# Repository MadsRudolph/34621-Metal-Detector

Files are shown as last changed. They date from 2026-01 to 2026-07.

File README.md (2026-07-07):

<div align="center">

# VLF Metal Detector

**Electromagnetic Sensors & Digital Signal Processing**





_A technical implementation of a VLF induction balance metal detector using real-time DFT-based phase detection._

---

</div>

## Overview

This project targets the development of a functional VLF metal detector built on the ATmega328P. It features modular firmware, IIR signal smoothing, and phase-based classification to distinguish between ferromagnetic and non-ferromagnetic metals.

### Features

- **DSP Core:** Single-bin DFT optimized for 4x oversampling (8 kHz) with real-time phase observation.
- **Power Stage:** High-efficiency H-bridge MOSFET driver for the transmitter coil.
- **Coil System:** Concentric coil design with an integrated bucking coil for balance.
- **Feedback:** Real-time OLED HUD and variable-tone buzzer for proximity detection.

## Architecture

```mermaid
graph LR
    MCU[MCU / 2kHz SQ] --> HB[H-Bridge] --> TX[TX Coil]
    Target((Metal)) -. Induction .-> RX[RX Coil]
    RX --> AMP[RX Amp] --> ADC[10-bit ADC]
    ADC --> DFT[DFT Processing] --> IIR[IIR Filter] --> UI[OLED + Buzzer]
```

## Specifications

| Component | Specification |
| :--- | :--- |
| **TX Frequency** | 2 kHz (Square Wave) |
| **Sample Rate**  | 8 kHz (4x Oversampling) |
| **MCU** | ATmega328P (Arduino Nano @ 16MHz) |
| **Driver** | H-Bridge (IRF5305 + IRL530) |
| **Sensors** | Concentric Coils (Bucking config) |
| **UI** | SSD1306 OLED (I2C) |

## Repository

- `Code/` — Core firmware (PlatformIO, C)
- `Docs/` — Technical reports and [Final PDF](Docs/Metaldetektor_Projekt.pdf)
- `KiCad/` — Hardware schematics and PCB designs
- `Simulation/` — LTspice and QSPICE validation files
- `Scripts/` — MATLAB and Python analysis tools

## Getting Started

Build and upload using [PlatformIO](https://platformio.org/):

```bash
cd Code
pio run -t upload
pio device monitor
```

---

<div align="center">
<b>Mads Rudolph · Andreas Skaaning · Jonas Beck · Sigurd Hestbech</b>
<br>
<sub>DTU Course 34621 · January 2026</sub>
</div>

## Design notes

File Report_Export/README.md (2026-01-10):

# Report Export Assets

This folder contains assets prepared for export to the DTU 34621 VLF Metal Detector report repository (Overleaf).

## Purpose

This folder serves as a staging area for figures, schematics, code snippets, and data that will be included in the final project report. Assets placed here are ready for export to the report repository.

## Folder Structure

| Folder | Description | Export Destination |
|---|---|---|
| `figures/` | Plots, diagrams, photos, and other images | `report/figures/` |
| `schematics/` | Circuit schematics and PCB layouts | `report/figures/schematics/` |
| `code_snippets/` | Key code excerpts for the report | `report/code/` |
| `data/` | Measurement data, CSV files, tables | `report/data/` |

## Workflow for Adding Assets

1. **Create/Export the Asset**
   - Generate figures from simulation tools or measurement software
   - Export schematics as PDF or high-resolution PNG
   - Copy relevant code snippets to separate files
   - Save measurement data as CSV or formatted tables

2. **Place in Appropriate Folder**
   - Use the correct subfolder based on asset type
   - Follow the naming convention (see below)

3. **Run Export Script**
   - Execute `./export_to_report.sh <report_repo_path>` from the project root
   - Commit and push changes in the report repository

## Running the Export Script

From the project root directory:

```bash
# Export to sibling report repository
./export_to_report.sh ../34621-Report

# Export to custom path
./export_to_report.sh /path/to/report/repo
```

The script will:
- Copy all non-empty asset folders to the report repository
- Skip folders that only contain `.gitkeep` files
- Print instructions for committing changes

## Naming Convention

Use **lowercase with underscores** for all filenames. Names should be descriptive and include context.

### Examples

| Good | Bad |
|---|-----|
| `tx_driver_schematic.pdf` | `Schematic1.pdf` |
| `dft_phase_response.png` | `Figure 3.png` |
| `rx_amplifier_bode_plot.png` | `bode.PNG` |
| `power_consumption_data.csv` | `data.csv` |
| `dft_algorithm.c` | `code.c` |

### Recommended Prefixes

- `tx_` - Transmitter related
- `rx_` - Receiver related
- `dft_` - DFT/signal processing related
- `coil_` - Coil design related
- `power_` - Power supply/consumption related
- `test_` - Test results and measurements

## File Formats

| Asset Type | Preferred Format | Alternative |
|---|---|---|
| Schematics | PDF (vector) | PNG (300+ DPI) |
| Plots/Graphs | PDF (vector) | PNG (300+ DPI) |
| Photos | JPEG | PNG |
| Code | `.c`, `.h` | `.txt` |
| Data | CSV | TXT |

## Notes

- Vector formats (PDF) are preferred for schematics and plots as they scale without quality loss
- Ensure all figures have readable labels and appropriate font sizes
- Include units in axis labels for all plots
- Code snippets should be self-contained and well-commented

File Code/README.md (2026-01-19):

# VLF Metaldetektor Firmware

Arduino Nano (ATmega328P @ 16MHz) firmware til VLF metaldetektion.

> **Teori:** [DSP-Bible](obsidian://open?vault=Obsidian&file=Courses%2FDSP%2FFormulas%2FDSP-Bible) | [FIIR & IIR](obsidian://open?vault=Obsidian&file=Courses%2FDSP%2FFormulas%2FFIIR%20%26%20IIR)

## Nuværende Struktur

```
src/
├── main.c            # Hovedprogram, initialisering, hovedløkke
├── adc.c             # ADC sampling og auto-trigger
├── button.c          # Knaphåndtering med debounce
├── buzzer.c          # Buzzer feedback (beeps ved detektion)
├── capture.c         # MATLAB serial capture interface
├── detection.c       # Metal klassificering (ferro/non-ferro)
├── dft.c             # DFT beregning og akkumulering
├── display.c         # OLED display med grafisk HUD og ikoner
├── filter.c          # IIR filter til udglatning
├── jingle.c          # Startup-melodi
├── timer.c           # Timer0/Timer1 konfiguration
│
├── include/          # Header filer
│   ├── config.h      # Globale konstanter og konfiguration
│   ├── adc.h, button.h, buzzer.h, capture.h
│   ├── detection.h, dft.h, display.h, filter.h
│   ├── jingle.h, timer.h
│
└── drivers/          # Hardware drivere (modificer ikke)
    ├── I2C.c/h       # TWI master driver
    ├── ssd1306.c/h   # OLED display driver
    └── data.h        # Font og ikon data (PROGMEM)
```

## Implementeret Funktionalitet

| Funktion | Status | Beskrivelse |
|---|---|---|
| TX Signal | ✅ Færdig | 2 kHz firkantbølge via Timer0 |
| ADC Sampling | ✅ Færdig | 8 kHz auto-trigger fra Timer0 |
| DFT Beregning | ✅ Færdig | Single-bin DFT med 4× oversampling |
| Magnitude/Fase | ✅ Færdig | Beregning fra Re/Im komponenter |
| OLED Display | ✅ Færdig | Grafisk HUD med ikoner og progress bar |
| Debug Knap | ✅ Færdig | D4 skifter mellem DFT/Debug skærm |
| Start/Stop Knap | ✅ Færdig | D2 toggle detektor on/off |
| Kalibrering Knap | ✅ Færdig | D3 gemmer baseline (luft-aflæsning) |
| Metalklassificering | ✅ Færdig | Ferro/non-ferro baseret på fase |
| IIR Filter | ✅ Færdig | Udglatning af display værdier |
| Buzzer Feedback | ✅ Færdig | Bip ved metal detektion |
| Startup Jingle | ✅ Færdig | Melodi ved opstart |
| Splash Screen | ✅ Færdig | Logo ved opstart |

## Build

```bash
pio run              # Kompilér
pio run -t upload    # Upload til board
pio device monitor   # Seriel monitor
```

## Pin Konfiguration

| Pin | Funktion | Retning |
|-----|---|---|
| 9 (PB1) | TX signal output (2kHz) | OUTPUT |
| 11 (PB3) | Buzzer output (PWM tone) | OUTPUT |
| A0 (PC0) | RX signal input (ADC) | INPUT |
| A4 (PC4) | I2C SDA (OLED) | I/O |
| A5 (PC5) | I2C SCL (OLED) | OUTPUT |
| D2 (PD2) | Start/Stop knap | INPUT (pull-up) |
| D3 (PD3) | Kalibrering knap | INPUT (pull-up) |
| D4 (PD4) | Debug knap | INPUT (pull-up) |

## Signalflow

```
Timer0 (8kHz) ──┬──> TX Pin Toggle (hver 2. interrupt = 2kHz)
                │
                └──> ADC Auto-Trigger
                          │
                          ▼
                    ADC ISR (8kHz)
                          │
                          ▼
                    DFT Akkumulering (64 samples)
                          │
                          ▼
                    IIR Filter → Klassificering → Display + Buzzer
```

## Konfigurationsparametre

```c
// Fra include/config.h
#define F_SAMPLE 8000     // Sample frekvens (Hz)
#define F_SIGNAL 2000     // TX/RX signal frekvens (Hz)
#define N 64              // Samples per DFT vindue
#define IIR_ALPHA 0.15f   // Filter udglatning
#define FERRO_THRESHOLD -10   // Fase tærskel for ferro (grader)
#define DETECT_THRESHOLD 5    // Min. magnitude ændring for detektion
```

## Moduler

| Modul | Beskrivelse |
|---|---|
| `timer.c` | Timer0 (8kHz interrupt, TX toggle) og Timer1 (buzzer PWM) |
| `adc.c` | ADC auto-trigger setup og sample håndtering |
| `dft.c` | Optimeret single-bin DFT (kun bin k=16 ved 2kHz) |
| `filter.c` | IIR lavpas filter for stabil visning |
| `detection.c` | Kalibrering og metal klassificering (ferro/non-ferro) |
| `display.c` | Grafisk HUD med ikoner, progress bar, splash screen |
| `button.c` | Debounced knaphåndtering for D2, D3, D4 |
| `buzzer.c` | Tone-generering via Timer1 PWM |
| `jingle.c` | Startup-melodi sekvens |
| `capture.c` | MATLAB serial interface til DFT verifikation |

## Relaterede Dokumenter

- [Project_Roadmap.md](../Docs/Project_Roadmap.md) - Fuld kravanalyse og status
- [Code_Review.md](../Docs/Guides/Code_Review.md) - Kodegennemgang

#firmware #arduino #dft #metaldetektor

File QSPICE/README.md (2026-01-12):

# QSPICE H-Bridge Simulation

> TX driver simulation for VLF metal detector coil excitation.
> Achieved **~98% efficiency** with optimized RLC filter.

> [!note] Danish Documentation
> For detailed theory and design rationale in Danish, see [TX Driver Design](../Docs/Theory/TX%20Driver%20Design.md).

---

## Overview

This folder contains QSPICE simulations for the H-bridge driver that excites the TX coil at 2kHz. The system converts 9V DC battery power to a sinusoidal current through the transmit coil.

```text
┌─────────────┐     ┌─────────────┐     ┌─────────────┐     ┌─────────────┐
│  PWM Input  │────▶│  Dead-Time  │────▶│  Bootstrap  │────▶│   H-Bridge  │────▶ TX Coil
│   (2kHz)    │     │  Generator  │     │ Gate Driver │     │  (IRL530)   │     (LC Tank)
└─────────────┘     └─────────────┘     └─────────────┘     └─────────────┘
```

---

## Files

| File | Description |
|---|---|
| `Hbro_sim.qsch` | Main H-bridge simulation with load |
| `bootstrap.qsch` | Bootstrap gate driver circuit |
| `dead_time.qsch` | Dead-time generator subcircuit |

---

## Hbro_sim.qsch — Main Simulation

### Circuit Topology

```text
        +9V (V1, RSER=1.7Ω)
            │
    ┌───────┴───────┐
    │               │
   M6              M3
  (IRL530)       (IRL530)
    │               │
    ├───[L2]───[C1]─┤───[R10]───┐
    │   6.3mH   1µF │    35Ω    │
   M4              M2           │
  (IRL530)       (IRL530)       │
    │               │           │
    └───────┬───────┘           │
           GND◄─────────────────┘
```

### Power Stage

| Component | Part | Specifications |
|---|---|---|
| M2, M3, M4, M6 | IRL530 | Vds=100V, Ids=15A, Ron=0.16Ω, Qg=17.8nC |
| D3, D4 | 1N4148 | Freewheeling diodes |

### Gate Drivers

| Component | Part | Function |
|---|---|---|
| M1, M7 | BS170 | Level shifter / inverter |
| U1, U2 | INV (OR gate) | Signal inversion |
| D1, D2 | 1N4148 | Bootstrap diode |
| C2, C3 | 1µF | Bootstrap capacitor |
| R3, R7 | Rup (1K) | Pull-up resistor |

### Load (TX Coil Model)

| Component | Value | Purpose |
|---|---|---|
| L2 | 6.332 mH | TX coil inductance |
| C1 | 1µF (param) | Resonance capacitor |
| R10 | 35Ω | Coil DC resistance |

Resonance frequency:
$$f_0 = \frac{1}{2\pi\sqrt{LC}} = \frac{1}{2\pi\sqrt{6.332\text{mH} \cdot 1\mu\text{F}}} \approx 2\text{kHz}$$

### PWM Signals

| Signal | Definition | Description |
|---|---|---|
| V3 (PWM1) | `PULSE 0 5 250µ 10n 10n 245µ 500µ` | Phase A, 250µs delay |
| V4 (PWM2) | `PULSE 0 5 0 10n 10n 245µ 500µ` | Phase B, no delay |
| V5 (PWM) | `pulse 5 0 0 10n 10n 0.5/2K 1/2K` | Master 2kHz clock |

The 180° phase shift between PWM1 and PWM2 creates alternating H-bridge states.

### Simulation Commands

```spice
.tran 0 0.2 0.198 1µ          ; Transient analysis, 0.2s
.options savepowers=1          ; Save power data

; Efficiency measurement
.meas Pl rms p(l2)+p(R10)+p(c1)    ; Load power
.meas Psource rms p(v1)            ; Source power
.meas eta param Pl/Psource         ; Efficiency η

; Parameter sweeps (commented)
;.step param R 0.01K 0.91K 0.1K
;.step param c1 0.1µ 1µ 0.1µ
```

---

## bootstrap.qsch — Gate Driver

The bootstrap circuit enables driving high-side N-channel MOSFETs from a ground-referenced PWM signal.

### Operating Principle

```text
    +9V
     │
     D1 (BAS521)──────┐
     │                │
    [R1=5Ω]          [C1=1µF]  ← Bootstrap Cap
     │                │
     └────────────────┼──── Vboot (floating supply)
                      │
                     M1 (AO3422, High-side)
                      │
                     OUT ──────────────────── To load
                      │
                     M2 (AO4262E, Low-side)
                      │
                     GND
```

### Bootstrap Sequence

1. **Low-side ON**: M2 conducts, OUT = GND
2. **C1 charges**: Current flows +9V → D1 → R1 → C1 → GND
3. **Low-side OFF**: Dead-time begins
4. **High-side ON**: M1 gate driven by Vboot (OUT + 9V)
5. **C1 discharges**: Provides gate charge for M1

### Components

| Half-Bridge | High-Side | Low-Side | Bootstrap | Pull-up |
|---|---|---|---|---|
| Left | M1 (AO3422) | M2 (AO4262E) | D1, C1, R1 | R4 (1K) |
| Right | M4 (AO3422) | M5 (AO4262E) | D2, C2, R5 | R8 (1K) |

Gate resistors (R2, R3, R6, R7 = 10Ω) limit di/dt and reduce EMI.
Pull-up resistors (R4, R8 = 1K) ensure defined gate state when driver is disabled.

---

## dead_time.qsch — Dead-Time Generator

Prevents shoot-through by ensuring both switches are OFF during transitions.

### Block Diagram

```text
                    ┌─────────────┐
     PWM_In ───────▶│   RC Delay  │
                    │  R4=R, C1=C │
                    └──────┬──────┘
                           │
              ┌────────────┴────────────┐
              ▼                         ▼
        ┌──────────┐              ┌──────────┐
        │  OpAmp1  │              │  OpAmp2  │
        │ (comp H) │              │ (comp L) │
        └────┬─────┘              └────┬─────┘
             │                         │
             ▼                         ▼
          H output                  L output
       (high-side)               (low-side)
```

### Timing Network

| Component | Value | Function |
|---|---|---|
| R1 | 1850Ω | Voltage divider |
| R2 | 650Ω | Voltage divider |
| R3 | 2.5kΩ | Threshold setting |
| R4 | R (param) | Dead-time adjust |
| C1 | C (param) | Dead-time adjust |

Dead-time duration: $t_{dead} \approx R \cdot C$

With R=3kΩ, C=5nF: $t_{dead} \approx 15\mu s$

### Comparators

Two RRopAmp (Rail-to-Rail) configured as comparators:
- **U1**: Generates H output (high-side gate)
- **U2**: Generates L output (low-side gate)

The RC network creates delayed thresholds so:
- When PWM rises: L turns OFF first, then H turns ON (after dead-time)
- When PWM falls: H turns OFF first, then L turns ON (after dead-time)

---

## Simulation Results

### Efficiency

| Parameter | Value |
|---|---|
| Source Power (Psource) | ~500 mW |
| Load Power (Pl) | ~490 mW |
| Efficiency (η) | **~98%** |

### Waveforms

Key signals to plot:
```spice
.plot i(L2)              ; Coil current (should be sinusoidal)
.plot is(M6) is(M3)      ; MOSFET currents
.plot v(G9) v(G3,S3)     ; Gate-source voltages
.plot v(G2) v(G11,S11)   ; Bootstrap gate voltages
```

---

## Design Notes

### Why H-Bridge?

The H-bridge converts DC to AC efficiently by alternately connecting the load to +V and GND. Combined with the LC resonant tank, it produces a clean sinusoidal current at 2kHz.

### Why Bootstrap?

N-channel MOSFETs have lower Rds(on) than P-channel for the same die size. The bootstrap circuit allows using N-channel for both high and low sides, maximizing efficiency.

### Component Selection

- **IRL530**: Logic-level gate (Vgs(th)=2V), suitable for 5V drive
- **BS170**: Small-signal MOSFET for inverter/driver
- **1N4148**: Fast switching diode for bootstrap
- **AO3422/AO4262E**: Alternative MOSFETs in bootstrap.qsch

---

## Running the Simulation

1. Open `Hbro_sim.qsch` in QSPICE
2. Run transient simulation (F5 or green play button)
3. View waveforms: Right-click on nets/components
4. Check efficiency: View `.meas` results in output log

### Parameter Sweeps

Uncomment in `Hbro_sim.qsch` to optimize:
```spice
.step param R 0.01K 0.91K 0.1K    ; Sweep dead-time resistor
.step param c1 0.1µ 1µ 0.1µ       ; Sweep tank capacitor
```

---

## Related Documentation

- [TX Driver Design](../Docs/Theory/TX%20Driver%20Design.md) - Theory and design rationale (Danish)
- [Coil Design](../Docs/Theory/Coil%20Design.md) - TX coil specifications
- [Power Budget Analysis](../Docs/Theory/Power%20Budget%20Analysis.md) - System power consumption

---

*Last updated: January 2026*

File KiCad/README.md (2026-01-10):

# KiCad Skemaer & PCB

Hardware designfiler til VLF Metaldetektoren.

> **Teori:** [Op-Amp Design](obsidian://open?vault=Obsidian&file=Courses%2FIntegrated%20Analog%20Electronics%2FLTspice%20%26%20Kicad%2F02%20-%20Two-Stage%20CMOS%20Op-Amp) | [Induktans](obsidian://open?vault=Obsidian&file=Courses%2FElectromagnetics%2FFormulas%2FL23%20-%20Magnetostatics%20II)

## Status

| Del | Status | Noter |
|-----|---|---|
| TX H-bro Driver | ✅ Designet | QSPICE valideret, ~90% effektivitet |
| RX Forstærker | ⏳ Afventer | Design påbegyndt |
| Strømforsyning | ⏳ Afventer | 9V → 5V regulering |
| MCU Sektion | ⏳ Afventer | Arduino Nano breakout |

## Kredsløbsblokke

### 1. Strømforsyning
- 9V batteri input
- Spændingsregulering (5V til MCU)
- Power filtrering
- Batteri monitorering (valgfri)

### 2. TX H-bro Driver
- PWM input fra Arduino (Pin 9)
- **P-kanal MOSFET:** IRF5305PbF (2 stk)
- **N-kanal MOSFET:** IRL530 (2 stk)
- Gate drivere til niveau-skift
- Spoletilslutning (skrueterminal)
- **Effektivitet:** ~90% (QSPICE verificeret)

### 3. RX Forstærker
- Høj-impedans indgangstrin
- Forstærkertrin (op-amp)
- Båndpasfilter omkring 2kHz
- Output skalering til 0-5V for ADC

### 4. Microcontroller Sektion
- Arduino Nano (ATmega328P)
- Intern 10-bit ADC (ingen ekstern ADC nødvendig)
- Timer0 auto-trigger til synkroniseret sampling

### 5. Display & UI
- SSD1306 OLED header (I2C)
- Knapinput (Start/Stop, Kalibrering, Debug)
- Summer output (valgfri)

## Komponentvalg

| Komponent | Delnummer | Pakke | Noter |
|---|---|---|---|
| MCU | Arduino Nano | - | ATmega328P @ 16MHz |
| P-MOSFET | IRF5305PbF | TO-220 | H-bro højside |
| N-MOSFET | IRL530 | TO-220 | H-bro lavside |
| Op-Amp | LM358 / TL072 | DIP-8 | Dual |
| Regulator | 7805 | TO-220 | 5V 1A |
| OLED | SSD1306 | - | 128×64, I2C |

## Pin Mapping (Arduino Nano / ATmega328P)

| Funktion | Arduino Pin | ATmega Pin | Port |
|---|---|---|---|
| TX Output | 9 | PB1 (15) | PORTB |
| RX Input (ADC) | A0 | PC0 (23) | PORTC |
| I2C SDA | A4 | PC4 (27) | PORTC |
| I2C SCL | A5 | PC5 (28) | PORTC |
| Debug Knap | 4 | PD4 (6) | PORTD |
| Start/Stop | 2 | PD2 (4) | PORTD |
| Kalibrering | 3 | PD3 (5) | PORTD |

## Design Regler (2-lags PCB)

| Parameter | Værdi |
|---|---|
| Min sporbredde | 0.25mm (10mil) |
| Min afstand | 0.25mm (10mil) |
| Via diameter | 0.8mm |
| Via boring | 0.4mm |
| Kobbertykkelse | 1oz |

## Tjekliste

- [x] H-bro design færdigt
- [x] QSPICE simulering bekræftet
- [ ] Skematisk capture komplet
- [ ] ERC (Electrical Rules Check) bestået
- [ ] Footprints tildelt
- [ ] PCB layout komplet
- [ ] DRC (Design Rules Check) bestået
- [ ] Gerbers genereret
- [ ] BOM eksporteret

## Relaterede Dokumenter

- [TX Driver Design.md](../Docs/Theory/TX%20Driver%20Design.md) - H-bro designanalyse
- [Power Budget Analysis.md](../Docs/Theory/Power%20Budget%20Analysis.md) - Strømforbrugsanalyse
- [[../Literature/kravspecifikation.pdf|Kravspecifikation]]

#kicad #pcb #hardware #skema

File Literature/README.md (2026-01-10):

# Litteratur

Kursusmaterialer, datablade og referencedokumenter til VLF Metaldetektor projektet.

## Kursusdokumenter

| Dokument | Beskrivelse |
|---|---|
| [[Course_intro.pdf]] | Kursusintroduktion og overblik |
| [[kravspecifikation.pdf]] | Kravspecifikation (16 krav) |
| [[arbejdsplan.pdf]] | Arbejdsplan skabelon |
| [[pseudocode_stm_MD.pdf]] | Pseudokode til tilstandsmaskine |

## Teori & Baggrund

### Signalbehandling
| Dokument | Emner |
|---|---|
| [[The_Discrete_Fourier_Transform.pdf]] | DFT teori, implementering |
| [[Filter_lektion.pdf]] | Filterdesign forelæsning |
| [[filters_v3_III_v1.pdf]] | Avanceret filterteori |

### Kredsløbsteori
| Dokument | Emner |
|---|---|
| [[RLC_Circuits_and_Resonance.pdf]] | Resonans, Q-faktor |
| [[Lesson_3_RLC_circuits__resonance.pdf]] | RLC kredsløbsanalyse |
| [[Transients_and_Oscillations_in_RLC_Circuitsv2m.pdf]] | Transient respons |
| [[Coil_Basics.pdf]] | Spoledesign |

### Elektronik
| Dokument | Emner |
|---|---|
| [[op_amps_everyone.pdf]] | Op-amp kredsløb, design |
| [[duracell_9volt.pdf]] | 9V batteri specifikationer |

### Metaldetektor Specifikt
| Dokument | Emner |
|---|---|
| [[Advanced_Instrumentation_for_Polyharmonic_Metal_Detectors.pdf]] | Avancerede MD teknikker |

## Læserækkefølge (Anbefalet)

1. **Uge 1 - Grundlæggende**
   - [ ] Course_intro.pdf
   - [ ] kravspecifikation.pdf
   - [ ] Coil_Basics.pdf
   - [ ] RLC_Circuits_and_Resonance.pdf

2. **Uge 2 - Signalbehandling**
   - [ ] The_Discrete_Fourier_Transform.pdf
   - [ ] Filter_lektion.pdf
   - [ ] op_amps_everyone.pdf

3. **Uge 3 - Integration**
   - [ ] pseudocode_stm_MD.pdf
   - [ ] Advanced_Instrumentation_for_Polyharmonic_Metal_Detectors.pdf

## Nøglebegreber

### DFT (Diskret Fourier Transformation)
- Single-bin DFT til 2kHz detektion
- 4× oversampling optimering: `cos = {1,0,-1,0}`, `sin = {0,1,0,-1}`
- Ingen trigonometriske funktioner nødvendige!
- Se: [[The_Discrete_Fourier_Transform.pdf]]

### RLC Resonans
- Resonansfrekvens: $f_0 = \frac{1}{2\pi\sqrt{LC}}$
- Kvalitetsfaktor: $Q = \frac{f_0}{BW}$
- Faseforskel indikerer metaltype
- Se: [[RLC_Circuits_and_Resonance.pdf]]

### Spoledesign
- TX spole: Generér 2kHz magnetfelt (Ø200mm, 20 vindinger)
- RX spole: Opfang reflekteret signal (Ø80mm, 200 vindinger)
- Bucking spole: Annullér direkte kobling (Ø120mm, 20 vindinger)
- Se: [[Coil_Basics.pdf]], [Coil Design.md](../Docs/Theory/Coil%20Design.md)

### Fasedetektion
- Ferromagnetiske metaller: Fase < 65° (høj permeabilitet)
- Ikke-ferromagnetiske metaller: Fase > 65° (hvirvelstrømme)
- Amplitude indikerer nærhed
- Se: [[Course_intro.pdf]]

## Eksterne Ressourcer

### Datablade (til download)
- [ATmega328P Datasheet](https://ww1.microchip.com/downloads/en/DeviceDoc/Atmel-7810-Automotive-Microcontrollers-ATmega328P_Datasheet.pdf) - Microcontroller
- [SSD1306 Datasheet](https://cdn-shop.adafruit.com/datasheets/SSD1306.pdf) - OLED display
- [IRF5305PbF Datasheet](https://www.infineon.com/dgdl/irf5305pbf.pdf) - P-kanal MOSFET (H-bro)
- [IRL530 Datasheet](https://www.infineon.com/dgdl/irl530.pdf) - N-kanal MOSFET (H-bro)
- [LM358 Datasheet](https://www.ti.com/lit/ds/symlink/lm358.pdf) - Op-amp

## Relaterede Dokumenter

- [Project_Roadmap.md](../Docs/Project_Roadmap.md) - Projektstatus og kravanalyse
- [Theory References.md](../Docs/Theory/Theory%20References.md) - Teori krydsreferencer

#litteratur #reference #teori #datablade

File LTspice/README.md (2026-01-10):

# LTspice & QSPICE Simuleringer

Kredsløbssimuleringer til VLF Metaldetektoren.

> **Teori:** [Op-Amp Design](obsidian://open?vault=Obsidian&file=Courses%2FIntegrated%20Analog%20Electronics%2FLTspice%20%26%20Kicad%2F02%20-%20Two-Stage%20CMOS%20Op-Amp) | [Filter Prototyper](obsidian://open?vault=Obsidian&file=Courses%2FDSP%2FFormulas%2FFilter_Prototypes_Comparison)

## Simuleringsværktøjer

| Værktøj | Anvendelse | Mappe |
|---|---|---|
| LTspice | Generelle simuleringer | `LTspice/` |
| QSPICE | H-bro driver (bedre MOSFET modeller) | `QSPICE/` |

## Status

| Kredsløb | Skema | Transient | AC Analyse | Status |
|---|---|---|---|---|
| TX H-bro Driver | ✅ | ✅ | ✅ | **Færdig** (QSPICE) |
| RX Forstærker | ⬜ | ⬜ | ⬜ | Afventer |
| Båndpasfilter | ⬜ | ⬜ | ⬜ | Afventer |
| Fuld Analog Kæde | ⬜ | ⬜ | ⬜ | Afventer |

## TX H-bro Driver (QSPICE) ✅

H-bro MOSFET driver til TX spole er fuldt simuleret og verificeret.

### Nøgleresultater
- **Effektivitet:** ~90%
- **Output:** 2 kHz firkantbølge
- **P-MOSFET:** IRF5305PbF (2 stk, højside)
- **N-MOSFET:** IRL530 (2 stk, lavside)
- **Strømforbrug:** Inden for power budget

Se: [TX Driver Design.md](../Docs/Theory/TX%20Driver%20Design.md) for fuld analyse.

## Planlagte Simuleringer

### 1. RX Spole Forstærker
- [ ] Forstærkningsberegning
- [ ] Støjanalyse
- [ ] Båndbredde (centreret på 2kHz)

### 2. Båndpasfilter
- [ ] Centerfrekvens: 2 kHz
- [ ] Q-faktor valg
- [ ] Faserespons

### 3. Fuld Analog Kæde
- [ ] End-to-end simulering
- [ ] Faseforskel verifikation
- [ ] Signalniveauer ved hvert trin

## LTspice Tips

### Nyttige Direktiver
```spice
.tran 0 10m 0 1u      ; Transient: 10ms, 1µs step
.ac dec 100 10 100k   ; AC: 10Hz til 100kHz, 100 pkt/dekade
.param Vcc=9          ; Parameter for forsyningsspænding
```

### Måling af Fase
1. Kør AC analyse
2. Tilføj plot: `V(out)` og `V(in)`
3. Højreklik → Add Trace → Phase

### Op-Amp Modeller
Brug generiske modeller eller specifikke:
- `UniversalOpAmp2` - Generisk
- `LM358` - Dual, rail-to-rail input
- `TL072` - Lav støj JFET

## Mappestruktur

```
LTspice/
├── simulations/      # .asc simuleringsfiler
├── models/           # .lib og .mod komponentmodeller
└── exports/          # Eksporterede plots og data
    ├── bode_plots/
    └── transient/

QSPICE/
└── [H-bro simuleringer]
```

## Relaterede Dokumenter

- [TX Driver Design.md](../Docs/Theory/TX%20Driver%20Design.md) - H-bro analyse
- [Power Budget Analysis.md](../Docs/Theory/Power%20Budget%20Analysis.md) - Strømforbrug
- [[../Literature/op_amps_everyone.pdf|Op Amps for Everyone]]
- [[../Literature/RLC_Circuits_and_Resonance.pdf|RLC Kredsløb]]

#ltspice #qspice #simulering #analog #kredsløb

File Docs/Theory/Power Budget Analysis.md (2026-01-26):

# Strømbudget Analyse

> [!abstract] Kernekrav
> Metaldetektoren skal køre i **100 minutter** på et 9V batteri (6LR61) med resterende spænding **>6V**.
>
> Se: [[kravspecifikation.pdf|Kravspecifikation]] krav 4 & 5

> [!success] Status: VERIFICERET (2026-01-21)
> **Batteritestresultat:** 164 min køretid med spænding **>7.7V** (test stoppet manuelt).
> Ved 100 min: **8.03V** — langt over 6V kravet. Kravet opfyldes med **>1.6× margin**.
>
> *Lav strøm opnås via H-bridge sleep mode (PD5 → enable pin) med ~50% duty cycle.*
>
> Se [[#5.1 Batteriafladetest (2026-01-21)]] for detaljerede måleresultater.

---

## 1. Batteri Karakteristik

### 1.1 Duracell MN1604 Specifikationer

> **Datablad:** [[Literature/duracell_9volt.pdf|Duracell 9V Datablad]]

| Parameter | Værdi | Betingelser |
|---|---|---|
| Nominel spænding | 9.0 V | Åben kreds |
| Frisk spænding | 9.4 - 9.6 V | Ingen belastning |
| Driftsområde | 9.6 V - 4.8 V | Under belastning |
| Indre impedans | 1.7 Ω | @ 1 kHz, frisk |
| Indre impedans | 3-5 Ω | @ 1 kHz, afladet |
| Nominel kapacitet | 580 mAh | Til 4.8V @ 25mA |
| Vægt | 45.6 g | |
| Kemi | Alkalisk (Zn-MnO₂) | |

### 1.2 Kapacitet vs. Afladningsrate

Alkaliske batterier udviser reduceret effektiv kapacitet ved højere afladningsrater på grund af indre modstand og elektrokemiske begrænsninger.

**Peukerts ligning (modificeret for alkalisk):**

$$C_{eff} = C_{nom} \times \left(\frac{I_{nom}}{I_{actual}}\right)^{n-1}$$

Hvor:
- $C_{eff}$ = effektiv kapacitet (mAh)
- $C_{nom}$ = nominel kapacitet ved standardrate (~500 mAh)
- $I_{nom}$ = nominel afladningsrate (~25 mA for 9V alkalisk)
- $I_{actual}$ = faktisk afladningsstrøm
- $n$ = Peukert eksponent (~1.1 for alkalisk)

### 1.3 Afladningskurve Analyse

Fra datablad kurver ved 21°C:

| Strøm (mA) | Køretid til 6V | Effektiv Kapacitet | Effektivitet |
|---|---|---|---|
| 10 | 2400 min (40t) | 400 mAh | 80% |
| 25 | 1080 min (18t) | 450 mAh | 90% |
| 50 | 600 min (10t) | 500 mAh | 100% |
| 100 | 210 min (3.5t) | 350 mAh | 70% |
| 150 | 120 min (2t) | 300 mAh | 60% |
| 200 | 75 min (1.25t) | 250 mAh | 50% |

---

## 2. Køretidskrav Udledning

### 2.1 Kravspecifikation

Fra kravspecifikation:
- Minimum køretid: $t_{min} = 100$ minutter
- Slutspænding: $V_{end} > 6.0V$

### 2.2 Maksimal Strømberegning

**Metode 1: Lineær interpolation fra afladningsdata**

Fra datablad:
- Ved $I_1 = 100$ mA → $t_1 = 210$ min
- Ved $I_2 = 150$ mA → $t_2 = 120$ min

For $t_{target} = 100$ min:

$$I_{max} = 100 + \frac{(210 - 100)}{(210 - 120)} \times (150 - 100) = 161\ \text{mA}$$

**Metode 2: Konservativt estimat med usikkerheder**

Faktorer der reducerer faktisk kapacitet:
- Temperaturvariation: -10%
- Batteri aldring: -5%
- Produktionsvariation: -5%

Kombineret nedvurderingsfaktor: $0.9 \times 0.95 \times 0.95 = 0.81$

$$I_{konservativ} = 161 \times 0.81 = 130\ \text{mA}$$

> [!danger] Design Maksimum
> $I_{max} = 120$ mA (afrundet ned for margin)

### 2.3 Designmål med Sikkerhedsmargin

$$I_{target} = \frac{I_{max}}{1.2} = \frac{120}{1.2} = 100\ \text{mA}$$

> [!success] Designmål
> $I_{system} \leq 100$ mA (konservativ) eller $\leq 120$ mA (maksimal)

---

## 3. Arduino Nano Strømanalyse

### 3.1 Board Blokdiagram

```
                    ┌─────────────────────────────────────────┐
                    │           Arduino Nano                   │
                    │          (ATmega328P)                    │
                    │                                         │
    9V Batteri ────►│──► AMS1117 ──► 5V Rail ──┬──► ATmega328P│
         │          │    (LDO)        │        │              │
         │          │                 │        ├──► CH340/FTDI│
         │          │                 │        │   (USB chip) │
         │          │                 │        ├──► Power LED │
         │          │                 │        └──► OLED      │
         │          │                 │                       │
         └──────────│─────────────────┴─► 3.3V Regulator     │
                    │                                         │
                    └─────────────────────────────────────────┘
```

### 3.2 Komponent-for-Komponent Analyse

#### 3.2.1 ATmega328P Mikrocontroller

**Fra ATmega328P Datablad, Sektion 29.2:**

| Tilstand | Betingelser | Strøm |
|---|---|---|
| Aktiv | 16 MHz, 5V | 12 mA (typ), 20 mA (max) |
| Idle | 16 MHz, 5V | 3.6 mA |
| Power-save | 32 kHz RTC, 5V | 0.9 mA |
| Power-down | WDT aktiveret, 5V | 15 µA |
| Power-down | WDT deaktiveret, 5V | 0.1 µA |

**Periferi strømtillæg:**

| Periferi | Ekstra Strøm | Noter |
|---|---|---|
| ADC | 0.3 mA | Under konvertering |
| Timer0 | 0.1 mA | TX generering |
| TWI (I2C) | 0.1 mA | OLED display |
| Brown-out Detector | 0.02 mA | Altid aktiv som standard |

**Estimeret ATmega328P total (vores applikation):**

$$I_{MCU} = I_{aktiv} + I_{ADC} + I_{Timer0} + I_{TWI} = 12 + 0.3 + 0.1 + 0.1 = 12.5\ \text{mA (typisk)}$$

Med datasheet maksimum for sikkerhed: **$I_{MCU} = 15$ mA**

#### 3.2.2 USB Interface Chip (CH340 eller FTDI)

De fleste Arduino Nano kloner bruger CH340G til USB-til-Serial konvertering.

**Fra CH340G datablad:**

| Tilstand | Strøm |
|---|---|
| Aktiv (USB forbundet) | 15 mA |
| Standby (USB afbrudt) | 2-3 mA |

**$I_{USB\_chip} = 3$ mA** (USB afbrudt, kun serial)

#### 3.2.3 Power LED

Grøn LED med strømbegrænsende modstand.

**Kredsløb:** 5V → LED ($V_f \approx 2.1V$) → R → GND

For typisk 1kΩ modstand:
$$I_{LED} = \frac{5V - 2.1V}{1000\Omega} = 2.9\ \text{mA}$$

**$I_{LED} = 3$ mA**

#### 3.2.4 Spændingsregulator Analyse

AMS1117 (eller lignende) er en lineær (LDO) regulator.

**Lineær regulator grundlæggende:**

$$I_{ind} = I_{ud} + I_q$$

**AMS1117 specifikationer:**
- Quiescent strøm: $I_q = 5$ mA (typisk)
- Dropout spænding: 1.1V @ 800mA

**Effekttab i regulator:**

Ved $V_{ind} = 9V$, $V_{ud} = 5V$, $I_{ud} = 40mA$:

$$P_{tab} = (V_{ind} - V_{ud}) \times I_{ud} = 4V \times 40mA = 160\ \text{mW}$$

**Regulator overhead: $I_q = 5$ mA**

#### 3.2.5 SSD1306 OLED Display

**Fra SSD1306 datablad:**

| Parameter | Værdi |
|---|---|
| Forsyningsspænding | 3.3V - 5V |
| Standby strøm | 10 µA |
| Driftsstrøm (50% pixels) | 8-10 mA |
| Driftsstrøm (alle pixels TIL) | 20 mA |

For typisk tekst display (~30% pixels tændt):

**$I_{OLED} = 12$ mA**

### 3.3 Total Board Strømoversigt

| Komponent | Strøm (mA) | Noter |
|---|---|---|
| ATmega328P (aktiv) | 15 | Konservativt estimat |
| CH340G (USB chip) | 3 | Standby tilstand |
| Power LED | 3 | Grøn LED |
| AMS1117 quiescent | 5 | LDO overhead |
| SSD1306 OLED | 12 | ~30% pixels |
| PCB lækage | 2 | Kondensatorer, spor |
| **Total (5V rail)** | **40 mA** | |

---

## 4. DSP Overhead — Detaljeret Analyse

### 4.1 Timer0 (TX Signalgenerering & ADC Trigger)

**Konfiguration:**
- Mode: CTC (Clear Timer on Compare)
- Interrupt rate: 8 kHz
- TX toggle hver 2. interrupt = 2 kHz firkantbølge
- ADC auto-trigger fra Timer0 Compare Match A

**Strømanalyse:**

Timer0 tilføjer cirka:
$$\Delta I_{Timer0} \approx 0.1\ \text{mA}$$

**Total Timer0 overhead: ~0.1 mA** (ubetydelig)

### 4.2 ADC Konvertering

**Konfiguration:**
- Opløsning: 10-bit
- Clock: 250 kHz (16 MHz / 64)
- Konverteringstid: 13 ADC cykler = 52 µs
- Sample rate: 8 kHz (auto-triggered)

52 µs konverteringstid vs 125 µs sample periode betyder ADC er aktiv ~42% af tiden.

**ADC strøm:**

Fra datablad: ADC tilføjer 0.3 mA når aktiv.

Ved 42% duty cycle:
$$I_{ADC} = 0.3\ \text{mA} \times 0.42 = 0.13\ \text{mA}$$

**Total ADC overhead: ~0.15 mA**

### 4.3 DFT Beregning

**Algoritme:** Single-bin DFT med 4× oversampling optimering

Se [[DFT Algorithm|DFT Algoritme]] for detaljer.

**Strømpåvirkning:**

CPU'en kører allerede. DFT beregning øger ikke strømmen — den bruger bare CPU cykler.

**DFT overhead: 0 mA** (ingen ekstra strøm, kun CPU tid)

### 4.4 Total DSP Overhead

| Komponent | Strøm (mA) |
|---|---|
| Timer0 periferi | 0.1 |
| ADC (42% aktiv) | 0.15 |
| DFT beregning | 0 |
| **Total DSP overhead** | **~0.3 mA** |

---

## 5. Revideret Strømbudget

### 5.1 Batteriafladetest (2026-01-21)

> [!success] Verificeret med Faktisk Batteriafladetest
> Test udført med fuldt system kørende i 164 minutter. Batteri ikke opbrugt — test stoppet manuelt.

**Testopsætning:**
- Batteri: 9V alkalisk (Duracell-type)
- System: Fuld metaldetektor med H-bro, Arduino Nano, OLED
- Måleudstyr: Analog Discovery 3 (spændingslogning hvert sekund)
- Afbrydelseskriterie: 6.0V eller 100+ min (krav opfyldt)

**Måleresultater:**

| Parameter | Målt Værdi |
|---|---|
| Startspænding | 8.88V |
| Spænding ved 100 min | **8.03V** |
| Slutspænding (164 min) | 7.76V |
| Total testtid | 164.3 min |
| Spændingsfald | 1.12V |
| Gennemsnitlig afladerate | 6.8 mV/min |

**Afladetest Graf:**

![[../Images/battery_discharge_test.png]]

> [!note] Test Status
> Testen blev stoppet manuelt efter 164 min da kravet (100 min ved >6V) var opfyldt med god margin.
> Batteriet havde stadig 7.76V — langt over 6V grænsen.

### 5.2 Strømestimering fra Afladedata

Baseret på batteriets afladekurve kan strømforbruget estimeres:

| Komponent | Estimeret (mA) | Noter |
|---|---|---|
| Elektronik baseline | ~40 | Arduino + OLED + regulatorer |
| TX System (H-bro) | ~16 avg | Duty-cycled via sleep mode |
| **Total System** | **~56** | **Estimeret fra afladekurve** |

### 5.3 Sleep Mode Forklaring

Den lave strøm skyldes **H-bridge sleep mode** implementeret i firmware:

**Hardware:**
- Pin 5 (PD5) er forbundet til H-bridge enable/sleep pin
- Når PD5 = HIGH → H-bridge i sleep mode (TX off)
- Når PD5 = LOW → H-bridge aktiv (TX on)

**Firmware (timer.c):**
```c
// Timer1 toggler SLEEP_PIN periodisk
ISR(TIMER1_COMPB_vect) {
    if (!do_sleep) {
        do_sleep = 1;
        PORTD |= (1 << SLEEP_PIN);   // H-bridge sleep
    } else {
        do_sleep = 0;
        PORTD &= ~(1 << SLEEP_PIN);  // H-bridge aktiv
    }
}
```

**Timer1 Konfiguration:**
- Phase correct PWM, 10-bit mode
- Prescaler 64: timer clock = 250 kHz
- Toggle rate: ~122 Hz (hver ~8.2 ms)
- **Duty cycle: ~50%** for H-bridge

**Strømbesparelse:**
| Tilstand | H-bridge Strøm | Gennemsnit ved 50% duty |
|---|---|---|
| Aktiv | ~32 mA | ~16 mA |
| Sleep | ~0 mA | - |

> [!note] MCU Idle Mode
> Når `do_sleep = 1` går MCU'en også i idle mode, hvilket sparer yderligere ~5-10 mA.
> CPU'en stopper, men Timer0/ADC/TWI fortsætter.

### 5.4 Køretidsberegning fra Faktisk Test

**Metode: Ekstrapolering fra målt afladekurve**

Fra batteritesten (sektion 5.1):
- Afladerate: 6.8 mV/min (gennemsnit over 164 min)
- Startspænding: 8.88V
- Målspænding: 6.0V (kravspecifikation)
- Nødvendigt spændingsfald: 8.88V - 6.0V = 2.88V

**Lineær ekstrapolering:**
$$t_{6V} = \frac{2880\ \text{mV}}{6.8\ \text{mV/min}} \approx 424\ \text{min}$$

> [!warning] Konservativt Estimat
> Alkaliske batterier aflader **hurtigere** ved lavere spændinger pga. stigende indre modstand.
> Den faktiske køretid til 6V er sandsynligvis **350-400 minutter**.

> [!success] Køretid (Verificeret)
> **Konservativt estimat: ~350-400 minutter (~6-7 timer)**
> Dette overstiger kravet på 100 minutter med **faktor 3.5-4×**
>
> **Faktisk målt ved 100 min: 8.03V** — langt over 6V grænsen.

### 5.5 Total Systemeffekt

$$P_{total} = V_{bat} \times I_{total} = 9V \times 56mA = 0.5W$$

| Batteri Tilstand | $V_{bat}$ (V) | $I_{total}$ (mA) | $P_{total}$ (W) |
|---|---|---|---|
| Frisk | 9.0 | 56 | **0.50** |
| 75% kapacitet | 8.0 | 56 | **0.45** |
| 50% kapacitet | 7.5 | 56 | **0.42** |
| Slut på levetid | 6.5 | 56 | **0.36** |

> [!success] Strømbudget OK
> Total systemstrøm på **56 mA** er vel inden for 9V batteriets kapacitet.
> Kravet om 100 min køretid opfyldes med stor margin.

---

## 6. TX Spole og Driver

> [!info] Detaljeret Dokumentation
> - **Spole specifikationer:** Se [[Coil Design|Spole Design]]
> - **Driver kredsløb:** Se [[TX Driver Design|TX Driver Design]]

### 6.1 Nøgletal for Strømbudget

| Parameter | Værdi | Kilde |
|---|---|---|
| TX induktans | 6.33 mH | Spole Design |
| Spole DC modstand | ~3 Ω | 0.56mm tråd |
| Serie modstand | 32 Ω (5W) | Forstærker matching |
| Total modstand | 35 Ω | R_coil + R_serie |
| H-bro spænding | 18 Vpp | 2 × 9V batteri |
| **TX strøm (RMS)** | **360 mA** | Beregnet |
| Effekt i serie R | ~4.1 W | $I^2 \times R$ |
| Driver effektivitet | >98% | QSPICE simulation |

---

## 7. Komplet Strømbudget Oversigt

### 7.1 Verificeret Strømbudget (Batteriafladetest 2026-01-21)

```
┌──────────────────────────────────────────────────────────────────────┐
│          STRØMBUDGET - VERIFICERET MED BATTERIAFLADETEST            │
│                  9V Forsyning + H-bro med Sleep Mode                │
├──────────────────────────────────────────────────────────────────────┤
│                                                                      │
│  BATTERI: 9V alkalisk (Duracell-type)                               │
│  MÅL KØRETID: 100 min ved >6V (krav)                                │
│  H-BRIDGE DUTY CYCLE: ~50% (sleep mode via PD5)                     │
│                                                                      │
├──────────────────────────────────────────────────────────────────────┤
│                                                                      │
│  BATTERIAFLADETEST RESULTATER (164 min test):                       │
│  ├─ Startspænding:              8.88V                               │
│  ├─ Spænding ved 100 min:       8.03V  ✅ (>6V krav)                │
│  ├─ Slutspænding (164 min):     7.76V                               │
│  └─ Afladerate:                 6.8 mV/min                          │
│                                                                      │
├──────────────────────────────────────────────────────────────────────┤
│                                                                      │
│  ESTIMERET STRØMFORBRUG:                               ~56 mA       │
│  ├─ Arduino Nano + OLED + Buzzer                      ~40 mA       │
│  └─ H-bro TX Driver (50% duty cycle)                  ~16 mA avg   │
│                                                                      │
├──────────────────────────────────────────────────────────────────────┤
│                                                                      │
│  EKSTRAPOLERET KØRETID TIL 6V                       ~350-400 min   │
│                                                       (~6-7 timer)  │
│                                                                      │
│  KRAV: 100 min ved >6V                                              │
│  MARGIN: 3.5-4× over krav                                           │
│                                                                      │
│  STATUS: ✅ OPFYLDER KRAV MED GOD MARGIN                            │
│                                                                      │
└──────────────────────────────────────────────────────────────────────┘
```

> [!success] Krav Opfyldt (Verificeret med Test)
> **Faktisk målt ved 100 min: 8.03V** — langt over 6V kravet.
> Ekstrapoleret køretid til 6V: **~350-400 minutter**.
> Dette opfylder kravet om 100 minutter med **faktor 3.5-4×**.

### 7.2 Køretidsestimater (Verificeret med Test)

| Metode | Køretid til 6V | Status |
|---|---|---|
| **Batteriafladetest (ekstrapoleret)** | **~350-400 min** | **✅ Opfylder krav** |
| Målt ved 100 min | 8.03V (>6V) | ✅ Krav opfyldt |
| Målt ved 164 min | 7.76V (>6V) | ✅ Stadig over grænse |

### 7.3 Teoretisk Estimat vs. Faktisk Test

| Parameter | Teoretisk Estimat | Batteriafladetest | Kommentar |
|---|---|---|---|
| Køretid til 6V | ~550 min | ~350-400 min | Teori var for optimistisk |
| Spænding ved 100 min | >6.5V | **8.03V** | Bedre end forventet |
| Margin over krav | 5.5× | **3.5-4×** | Stadig god margin |

> [!info] Årsag til Forskel
> Det teoretiske estimat på ~550 min var baseret på **datasheet-interpolation**.
> Den faktiske batteriafladetest viser ~350-400 min, hvilket skyldes:
> - Batteriets faktiske kapacitet vs. datasheet
> - Ikke-lineær afladekurve ved lavere spændinger
> - Indre modstand stiger under afladning
>
> **Konklusionen er den samme:** Kravet på 100 min opfyldes med god margin.

---

## 8. Strømstyringsstrategi

### 8.1 Implementeret Sleep Mode

> [!success] Automatisk Strømstyring
> Firmwaren implementerer automatisk sleep mode der reducerer strømforbruget fra ~400 mA til **~56 mA**.
> **Verificeret med batteriafladetest** — se sektion 5.1.

**Sleep mode komponenter:**

| Komponent | Metode | Besparelse |
|---|---|---|
| H-bridge | PD5 toggle (~50% duty) | ~344 mA |
| MCU | Idle mode når H-bridge sover | ~5-10 mA |

### 8.2 Driftstilstande (Verificeret med Test)

| Tilstand | H-bridge Duty | Total Strøm | Køretid til 6V | Status |
|---|---|---|---|---|
| **Normal drift (sleep mode)** | ~50% | ~56 mA | **~350-400 min** | ✅ Bruges |
| Standby (TX off) | 0% | ~40 mA | ~500 min | Tilgængelig |
| Fuld ydelse (ingen sleep) | 100% | ~400 mA | ~35 min | Ikke brugt |

### 8.3 Batteri Levetid (Verificeret)

Baseret på faktisk batteriafladetest (2026-01-21):

| Batteri Type | Køretid til 6V | Kilde |
|---|---|---|
| **9V Alkalisk** | **~350-400 min (~6-7 timer)** | **Faktisk test** |
| 9V Lithium | ~14-17 timer | Estimeret (2.4× kapacitet) |
| 6× AA (9V) | ~30-35 timer | Estimeret (5× kapacitet) |

> [!tip] Anbefaling
> Et enkelt 9V alkalisk batteri er tilstrækkeligt til alle normale anvendelser.
> Sleep mode sikrer lang batterilevetid uden brugerindgreb.
> Kravet på 100 min opfyldes med **3.5-4× margin**.

---

## 9. Verifikationstest Plan

### 9.1 Komponenttest (Opdateret med Målinger)

| Test | Opsætning | Bestået Kriterier | Målt Resultat |
|---|---|---|---|
| Arduino Nano + OLED | 9V via strømmåler | < 45 mA | ~40 mA ✅ |
| TX driver alene | Oscilloskop + DMM | < 50 mA | ~16 mA ✅ |
| Fuld elektronik (uden TX) | Strømmåler + batteri | < 45 mA | ~40 mA ✅ |
| **Fuldt system (100% duty)** | **Strømmåler + 9V** | **< 120 mA** | **56 mA ✅** |

### 9.2 Spole Verifikation

| Test | Metode | Bestået Kriterier |
|---|---|---|
| TX induktans | LCR meter @ 1kHz | 6-7 mH |
| TX DC modstand | Multimeter | 2-4 Ω |
| Serie modstand | Multimeter | 32 Ω ±5% |
| Total modstand | Multimeter | 34-36 Ω |

### 9.3 Køretids Test Protokol

> [!success] Verificeret med Batteriafladetest (2026-01-21)
> Fuldt system testet i 164 minutter med kontinuerlig spændingslogning.

**Faktisk Målt Data:**

| Tid (min) | $V_{bat}$ (V) Forventet | $V_{bat}$ (V) Målt | Status |
|---|---|---|---|
| 0 | >9.0 | **8.88** | Start |
| 25 | >8.5 | **~8.55** | ✅ |
| 50 | >8.0 | **~8.30** | ✅ |
| 75 | >7.5 | **~8.15** | ✅ |
| **100** | **>6.0** | **8.03** | **BESTÅET** ✅ |
| 164 | >6.0 | **7.76** | ✅ Test stoppet |

> [!success] Krav Opfyldt (Verificeret)
> Ved 100 min var batterispændingen **8.03V** — langt over kravet på 6V.
> Test blev stoppet ved 164 min med **7.76V** stadig tilgængelig.

---

## 10. Referencer

1. [[Literature/duracell_9volt.pdf|Duracell 9V Datablad]]
2. [[kravspecifikation.pdf|Kravspecifikation]]
3. [[Search Coil Design]]
4. [[TX Driver Design]]
5. [[DFT Algorithm|DFT Algoritme]]
6. ATmega328P Datablad, Microchip Technology
7. CH340G Datablad, WCH
8. Si2301/Si2302 Datablad, Vishay
9. SSD1306 Datablad, Solomon Systech
10. AMS1117 Datablad, Advanced Monolithic Systems

---

#strøm #beregninger #spole-design #driver #målinger #krav

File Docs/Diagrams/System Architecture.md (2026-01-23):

# System Architecture - VLF Metal Detector

## Vertical Block Diagram

```mermaid
flowchart TB
    Battery["9V Batteri"]
    MCU["Arduino Nano (ATmega328P)<br/>Timer0, ADC, DFT"]
    HBridge["H-Bro Power Amplifier<br/>4× IRL530"]
    TXCoil["TX Spole<br/>200mm Ø, 2 kHz"]
    Metal["Metal Objekt"]
    RXCoil["RX Spole + Bucking<br/>50mm Ø"]
    RXAmp["RX Forstærker + AA-filter<br/>Gain 100-500×"]
    Display["OLED Display + Buzzer + Knapper"]

    Battery -->|"9V"| HBridge
    Battery -->|"5V reg"| MCU
    MCU -->|"2 kHz PWM"| HBridge
    HBridge -->|"Strøm"| TXCoil
    TXCoil -.->|"Magnetfelt"| Metal
    Metal -.->|"Forstyrret felt"| RXCoil
    RXCoil -->|"1-10 mV"| RXAmp
    RXAmp -->|"0-5V"| MCU
    MCU -->|"I2C + PWM"| Display
    Display -.->|"Kontrol"| MCU

    classDef powerBox fill:#fff9c4,stroke:#f57f17,stroke-width:3px
    classDef mcuBox fill:#e1f5ff,stroke:#01579b,stroke-width:3px
    classDef txBox fill:#fff3e0,stroke:#e65100,stroke-width:3px
    classDef coilBox fill:#e8f5e9,stroke:#1b5e20,stroke-width:3px
    classDef rxBox fill:#f3e5f5,stroke:#4a148c,stroke-width:3px

    class Battery powerBox
    class MCU mcuBox
    class HBridge txBox
    class TXCoil,Metal,RXCoil coilBox
    class RXAmp rxBox
    class Display powerBox
```

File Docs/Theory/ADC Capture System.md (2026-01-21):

# ADC Capture System

> [!abstract] Dokumentformål
> Beskrivelse af ADC → DFT pipelinen, timing-kæden, og synkronisering med TX signalet.

## 1. Oversigt

Metal detektoren bruger en synkroniseret sampling-kæde til at analysere RX spolens signal:

```
Timer0 (8kHz) → ADC Auto-trigger → DFT Akkumulering → Magnitude/Fase
     ↓
TX Signal (2kHz) ← rising_edge_Flag → DFT Synkronisering
```

> [!important] Kritisk Timing
> ADC sampling SKAL være synkroniseret med TX signalet for korrekt faseberegning.
> Uden synkronisering vil fasen variere tilfældigt mellem DFT vinduer.

## 2. Timing-Kæde

### 2.1 Timer0 Konfiguration

Timer0 genererer 8 kHz interrupt som driver hele systemet. Se `timer.c:timer0_init()` (linje 22-37):

```c
// CTC mode (Clear Timer on Compare Match)
TCCR0A |= (1 << WGM01);

// Prescaler 8
TCCR0B |= (1 << CS01);

// Compare match: 16MHz / 8 / 250 = 8kHz
OCR0A = 249;
```

Beregning af interrupt frekvens:

$$f_{interrupt} = \frac{F_{CPU}}{prescaler \times (OCR0A + 1)} = \frac{16\text{MHz}}{8 \times 250} = 8000\text{ Hz}$$

### 2.2 TX Signal Generering

Timer0 ISR toggler TX pin hver 2. interrupt for at skabe 2 kHz firkantbølge. Se `timer.c:ISR(TIMER0_COMPA_vect)` (linje 76-87):

```c
ISR(TIMER0_COMPA_vect) {
    i++;
    if (i >= 2) {                   // Hver 2. interrupt
        PORTB ^= (1 << TX_PIN);     // Toggle TX pin
        i = 0;

        if (PORTB & (1 << TX_PIN)) {
            rising_edge_Flag = 1;   // Signal til DFT synkronisering
        }
    }
}
```

> [!tip] XOR Toggle Trick
> `PORTB ^= (1 << TX_PIN)` bruger XOR til at flippe bit uden at læse-modificere-skrive.
> Dette er hurtigere og atomisk.

### 2.3 Timing Parametre

| Parameter | Værdi | Beregning |
|---|---|---|
| Timer0 interrupt | 8000 Hz | 16MHz / 8 / 250 |
| TX toggle rate | 4000 Hz | 8000 / 2 |
| TX frekvens | **2000 Hz** | 4000 / 2 (toggle = halv frekvens) |
| Sample periode | 125 µs | 1 / 8000 |
| TX periode | 500 µs | 1 / 2000 |

## 3. ADC Auto-Trigger

### 3.1 Konfiguration

ADC'en er sat op til automatisk at starte konvertering når Timer0 Compare Match A udløses. Se `adc.c:adc_init()` (linje 17-36):

```c
// Reference = AVCC (5V)
ADMUX = (1 << REFS0);

// ADC Kontrol: Enable, Interrupt, Auto-trigger, Prescaler 64
ADCSRA = (1 << ADEN) | (1 << ADIE) | (1 << ADATE)
       | (1 << ADPS2) | (1 << ADPS1);

// Auto-trigger kilde = Timer0 Compare Match A
ADCSRB |= (1 << ADTS1) | (1 << ADTS0);
```

> [!note] ADC Clock
> Med prescaler 64 og 16 MHz CPU clock får vi:
> $$f_{ADC} = \frac{16\text{MHz}}{64} = 250\text{ kHz}$$
> En konvertering tager 13 ADC cycles = 52 µs, hvilket er hurtigere end sample perioden (125 µs).

### 3.2 ADC Interrupt Handler

Når konvertering er færdig, kaldes `adc.c:ISR(ADC_vect)` (linje 53-59):

```c
ISR(ADC_vect) {
    ADC_Raw = ADC;              // Læs 10-bit værdi (0-1023)

    if (rising_edge_Flag == 1) {
        DFT_sum(ADC_Raw);       // Send til DFT kun når synkroniseret
    }
}
```

## 4. DFT Synkronisering

### 4.1 rising_edge_Flag Mekanisme

```
┌──────────────────────────────────────────────────────────────────┐
│                         TIMING DIAGRAM                           │
├──────────────────────────────────────────────────────────────────┤
│                                                                  │
│ Timer0 ISR:  ↓     ↓     ↓     ↓     ↓     ↓     ↓     ↓        │
│              |     |     |     |     |     |     |     |        │
│ TX Signal:   ┌─────┐     ┌─────┐     ┌─────┐     ┌─────┐        │
│              │     │     │     │     │     │     │     │        │
│          ────┘     └─────┘     └─────┘     └─────┘     └────    │
│              ↑           ↑           ↑           ↑              │
│              │           │           │           │              │
│ Flag=1:      ●           ●           ●           ●              │
│                                                                  │
│ ADC ISR:     ↓  ↓  ↓  ↓  ↓  ↓  ↓  ↓  ↓  ↓  ↓  ↓  ↓  ↓  ↓  ↓   │
│              |  |  |  |  |  |  |  |  |  |  |  |  |  |  |  |    │
│ DFT_sum:     ●  ●  ●  ●  ○  ○  ○  ○  ●  ●  ●  ●  ○  ○  ○  ○   │
│              │           │           │                          │
│              └─ N=64 ────┘           └─ næste vindue            │
│                samples                                           │
└──────────────────────────────────────────────────────────────────┘

● = DFT_sum kaldes (rising_edge_Flag == 1)
○ = DFT_sum springes over (venter på næste rising edge)
```

### 4.2 Synkroniseringsflow

1. **Timer0 ISR** toggler TX og sætter `rising_edge_Flag = 1` ved rising edge
2. **ADC ISR** kalder kun `DFT_sum()` når `rising_edge_Flag == 1`
3. **DFT_sum** akkumulerer N=64 samples, derefter nulstiller `rising_edge_Flag = 0`
4. DFT venter på næste TX rising edge før ny akkumulering starter

> [!success] Fasestabilitet
> Denne mekanisme sikrer at DFT altid starter ved TX fase 0°.
> Uden synkronisering ville fasen drifte med op til ±180° mellem vinduer.

## 5. DFT Akkumulering

### 5.1 4× Oversampling Optimering

Med $F_s = 8000$ Hz og $F_{signal} = 2000$ Hz sampler vi med præcis 4× oversampling.
Dette giver faseforskydning på $\frac{2\pi}{4} = \frac{\pi}{2}$ mellem samples.

DFT koefficienter for bin $k = \frac{N \times F_{signal}}{F_s} = \frac{64 \times 2000}{8000} = 16$:

| Sample n mod 4 | $\cos(2\pi n/4)$ | $-\sin(2\pi n/4)$ | Operation |
|---|---|---|---|
| 0 | +1 | 0 | `Re += xn` |
| 1 | 0 | -1 | `Im -= xn` |
| 2 | -1 | 0 | `Re -= xn` |
| 3 | 0 | +1 | `Im += xn` |

Se `dft.c:DFT_sum()` (linje 51-107) for implementation.

### 5.2 DC Offset Fjernelse

Før akkumulering fjernes DC offset defineret i `config.h:25`:

```c
#define ADC_MIDDELVAERDI 512  // Midt i 10-bit range
```

I `dft.c:58`:
```c
xn = ADC_Raw - ADC_MIDDELVAERDI;
```

> [!warning] Vigtigt
> Uden DC offset fjernelse vil DFT'en se et stort DC komponent der forvrænger magnitude beregningen.

## 6. Signalflow Komplet

```mermaid
graph TD
    A[Timer0 Compare Match<br/>8 kHz] --> B[ADC Auto-trigger]
    A --> C[Timer0 ISR]
    C --> D{i >= 2?}
    D -->|Ja| E[Toggle TX Pin]
    E --> F{TX rising edge?}
    F -->|Ja| G[rising_edge_Flag = 1]

    B --> H[ADC Konvertering<br/>52 µs]
    H --> I[ADC ISR]
    I --> J{rising_edge_Flag?}
    J -->|Ja| K[DFT_sum]
    K --> L{j >= N?}
    L -->|Ja| M[Kopier til buffer<br/>DFT_done = 1<br/>rising_edge_Flag = 0]
    L -->|Nej| N[j++]

    M --> O[Main Loop]
    O --> P[DFT_Calc<br/>sqrt, atan2]
    P --> Q[Magnitude + Fase]
```

## 7. Timing Constraints

| Operation | Tid | Cykler @ 16MHz | Kilde |
|---|-----|---|---|
| Timer0 ISR | ~2 µs | ~32 | `timer.c:76-87` |
| ADC konvertering | 52 µs | 832 (ADC clock) | Hardware |
| ADC ISR + DFT_sum | ~5 µs | ~80 | `adc.c:53-59`, `dft.c:51-107` |
| DFT_Calc (main loop) | ~500 µs | ~8000 | `dft.c:116-122` |

> [!note] Margin
> Sample periode er 125 µs. ISR overhead er ~7 µs, hvilket giver god margin.
> Float beregninger i `DFT_Calc()` kører i main loop og påvirker ikke sampling timing.

## Relaterede Dokumenter

- [[DFT Algorithm]] - Matematisk baggrund for 4× oversampling optimering
- [[Filter Design]] - IIR lavpasfilter efter DFT
- [[Metal Classification]] - Brug af fase til ferro/non-ferro skelnen

## Kode Referencer

| Fil | Funktion | Beskrivelse |
|-----|---|---|
| `timer.c:22-37` | `timer0_init()` | Timer0 opsætning |
| `timer.c:76-87` | `ISR(TIMER0_COMPA_vect)` | TX generering + sync flag |
| `adc.c:17-36` | `adc_init()` | ADC auto-trigger opsætning |
| `adc.c:53-59` | `ISR(ADC_vect)` | Sample til DFT |
| `dft.c:51-107` | `DFT_sum()` | 4× oversampling akkumulering |
| `config.h:11-13` | — | Timing konstanter |

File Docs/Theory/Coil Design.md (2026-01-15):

# Spole Design - VLF Metaldetektor

> [!abstract] Dokumentformål
> Spole design specifikationer for VLF metaldetektor.
> Opdateret til Arduino Nano strømbudget og H-bro forstærker.

---

## 1. Systemoversigt

### 1.1 Tre-Spole Koncentrisk Design

```
         ┌─────────────────────────────────────────┐
         │              SET OVENFRA                │
         │                                         │
         │    ┌─────────────────────────────┐     │
         │    │         TX SPOLE            │     │
         │    │        200 mm ⌀             │     │
         │    │    ┌───────────────────┐    │     │
         │    │    │   BUCKING SPOLE   │    │     │
         │    │    │      60 mm ⌀      │    │     │
         │    │    │   ┌───────────┐   │    │     │
         │    │    │   │  RX SPOLE │   │    │     │
         │    │    │   │   50 mm ⌀ │   │    │     │
         │    │    │   └───────────┘   │    │     │
         │    │    └───────────────────┘    │     │
         │    └─────────────────────────────┘     │
         │                                         │
         └─────────────────────────────────────────┘
```

### 1.2 Designkrav

| Parameter | Krav | Faktisk | Kilde |
|---|---|---|---|
| TX Frekvens | 2 kHz | 2 kHz | Firmware |
| TX Strøm (RMS) | - | 364 mA | H-bro @ 18 Vpp |
| TX Induktans | - | 1.97 mH | Prototype (70 vind.) |
| RX Induktans | ≥ 10 mH | 11.15 mH | Prototype (445 vind.) |
| Forsyningsspænding | 9V | 9V | Batteri |

---

## 2. Wheeler Formler - Verificeret

> [!success] Formel Verificeret
> Wheeler formlerne er verificeret mod LCR måling med **2% nøjagtighed**.
> Kilde: H.A. Wheeler, "Simple Inductance Formulas for Radio Coils", Proc. IRE, Vol. 16, No. 10, Oct. 1928.

### 2.1 Flerlagssolenoid (TX, RX spoler)

**Original formel (tommer):**
$$L \text{ (µH)} = \frac{0.8 \times a^2 \times N^2}{6a + 9b + 10c}$$

**Konverteret til cm:**
$$L \text{ (µH)} = \frac{0.315 \times a^2 \times N^2}{6a + 9b + 10c}$$

Hvor (alle i **cm**):
- $a$ = middelradius af spole
- $b$ = aksial længde (viklingshøjde)
- $c$ = radial tykkelse (viklingsdybde)
- $N$ = totalt antal vindinger

> [!note] Enheds-konvertering
> Koefficient: $0.315 = 0.8 / 2.54$ (tommer → cm)
> Formlens dimension er $\text{længde}^1$, så kun division med 2.54.

### 2.2 Enkeltlagssolenoid (Bucking spole)

**Original formel (tommer):**
$$L \text{ (µH)} = \frac{a^2 \times N^2}{9a + 10b}$$

**Konverteret til cm:**
$$L \text{ (µH)} = \frac{0.394 \times a^2 \times N^2}{9a + 10b}$$

Hvor:
- $a$ = radius (cm)
- $b$ = viklingsængde (cm)
- $N$ = antal vindinger

> [!tip] Hvornår bruges hvilken formel?
> - **Flerlag (n > 1):** Brug flerlagsformel - inkluderer radial tykkelse
> - **Enkeltlag (n = 1):** Brug enkeltlagsformel - mere præcis for tynde vikler

### 2.3 Nøjagtighedsbegrænsninger

| Geometri | Forventet Fejl | Noter |
|---|---|---|
| Optimal (6a ≈ 9b ≈ 10c) | ±1% | Kompakt, balanceret spole |
| Normal praktisk | ±2-3% | De fleste spoler |
| Flad/pancake (stor R, lille c) | ±5-10% | **TX spole advarsel!** |
| Enkeltlag | ±1-3% | Brug enkeltlagsformel |

> [!warning] TX Spole Geometri
> TX spolen (Ø200mm, 2 lag) har "flad" geometri hvor $10c << 6a$.
> Wheeler kan **undervurdere** induktansen med 5-10%.
> Anbefaling: Tilføj ~10% flere vindinger og juster empirisk.

---

## 3. TX Spole - Specifikationer

> [!info] Prototype Værdier
> TX spolen er viklet med 70 vindinger i 2 lag på Ø200mm form.
> Se [[TX Driver Design]] for forstærker detaljer.

### 3.1 Elektriske Specifikationer

| Parameter | Værdi | Noter |
|---|---|---|
| **Induktans** | **1.97 mH** | Wheeler beregnet |
| **Spole DC Modstand** | 3.02 Ω | Med 0.56mm tråd |
| **Serie Modstand** | **32 Ω** | Ekstern modstand for forstærker |
| **Total Modstand** | **35 Ω** | Krævet af H-bro design |
| **Resonans C** | **1.0 µF** | Standard værdi |
| **Reaktans (X_L)** | 24.8 Ω | @ 2 kHz |
| **TX Strøm (RMS)** | **364 mA** | H-bro @ 18 Vpp |
| **TX Strøm (Peak)** | 514 mA | H-bro @ 18 Vpp |
| **Q-faktor** | 0.7 | Lav Q for stabilitet |
| **Total effekt** | 4.6 W | I kredsløbet |

### 3.2 Fysiske Specifikationer

| Parameter | Værdi |
|---|---|
| Form diameter | **200 mm** |
| Tråddiameter | **0.56 mm** |
| Antal vindinger | **70 vindinger** |
| Vindinger per lag | **35 vindinger** |
| Antal lag | **2 lag** |
| Aksial længde | **19.6 mm** |
| Radial tykkelse | **1.1 mm** |
| Trådlængde | **44.2 m** |
| Vikleretning | **MED URET** |

> [!warning] Geometri Advarsel
> TX spolen har "flad" geometri (stor diameter, få lag).
> Wheeler formel kan UNDERVURDERE induktans med 5-10%.
> Balance ratio: 0.02 (optimal: > 0.5)

### 3.3 Viklingsinstruktioner

```
         ←───────── 19.6 mm ─────────→
        ┌─────────────────────────────┐
Lag 2   │▓▓▓▓▓▓▓▓▓▓▓▓▓▓▓▓▓▓▓▓▓▓▓▓▓▓▓▓▓│ (vindinger 36-70)
Lag 1   │▓▓▓▓▓▓▓▓▓▓▓▓▓▓▓▓▓▓▓▓▓▓▓▓▓▓▓▓▓│ (vindinger 1-35)
        └─────────────────────────────┘
         ╔═══════════════════════════╗
         ║   200 mm diameter form    ║
         ╚═══════════════════════════╝
```

**Materialer:**
- Plastikform: 200 mm diameter
- Kobbertråd: 0.56 mm, ~49 m længde (inkl. margin)
- Elektrisk tape til sikring af lag

**Procedure:**
1. Marker startpunkt på 200 mm formen
2. Vikl **35 vindinger MED URET**, tætviklet (lag 1)
3. Påfør tynd tape til sikring
4. Vikl **35 vindinger** tilbage over lag 1 (lag 2)
5. **Total: 70 vindinger i 2 lag**

### 3.4 Serie Modstand

> [!important] Forstærker Matching
> H-bro forstærkeren er designet til 35Ω total modstand for at opnå ~364 mA RMS strøm.
> Da spolen kun har 3.02Ω DC modstand, kræves en ekstern serie modstand.

| Parameter | Værdi |
|---|---|
| **Serie modstand** | **32 Ω** |
| **Effekt rating** | **≥ 5W** |
| Effekt i modstand | 4.2 W |
| Type | Wirewound eller keramisk |
| Formål | Matcher forstærker, sænker Q |

**Effektberegning:**
$$P_{resistor} = I_{rms}^2 \times R = 0.364^2 \times 32 \approx 4.2\ \text{W}$$

> [!warning] Varmegenerering
> Serie modstanden afgiver ~4.2W varme. Brug en 5W eller 10W modstand med god ventilation.

### 3.5 Vindinger vs Induktans Reference

| Vindinger | Induktans | DC Modstand |
|---|---|---|
| 50 | 1.0 mH | 2.2 Ω |
| 60 | 1.5 mH | 2.6 Ω |
| **70** | **1.97 mH** | **3.02 Ω** ← Prototype |
| 80 | 2.6 mH | 3.5 Ω |
| 90 | 3.2 mH | 3.9 Ω |

![[tx_turns_vs_inductance.png]]
*Figur: TX vindinger vs induktans (genereret af MATLAB)*

### 3.6 Verifikationsmål

- [x] Induktans: 1.97 mH (målt TX+Bucking: 2.03 mH)
- [x] Spole DC Modstand: 3.02 Ω (målt TX+Bucking: 3.9 Ω)
- [ ] Serie modstand monteret: 32 Ω, ≥5W
- [ ] TX strøm med H-bro: ~364 mA RMS

---

## 4. Resonanskredsløb

### 4.1 Hvorfor Resonans?

LC tankkredsen konverterer **firkantbølge** fra MCU til **sinusbølge**:

```
  MCU Firkantbølge              LC Tank Output
  ┌───┐   ┌───┐                  ╭───╮   ╭───╮
  │   │   │   │                 ╱     ╲ ╱     ╲
──┘   └───┘   └──      →    ──╱       ╳       ╲──
                               ╲     ╱ ╲     ╱
                                ╰───╯   ╰───╯
```

**Fordele ved sinusbølge:**
- Ren fasemåling for DFT
- Nøjagtig ferro/ikke-ferro diskriminering
- Bedre signal-støj forhold
- Lavere EMI emission

### 4.2 Resonanskondensator Beregning

For resonans ved 2 kHz med L = 1.97 mH:

$$C = \frac{1}{(2\pi f)^2 L} = \frac{1}{(2\pi \times 2000)^2 \times 0.00197} = 3.2\ \text{µF}$$

> [!note] Kondensator Justering
> Ved 1.0 µF kondensator er kredsløbet ikke i resonans.
> For at opnå resonans ved 2 kHz skal der bruges ~3.2 µF.
> Alternativt kan resonansfrekvensen justeres.

### 4.3 Resonanskondensator Specifikationer

| Parameter | Værdi |
|---|---|
| **Kapacitans** | **1.0 µF** (eller 3.2 µF for resonans) |
| Type | Film (MKP/MKT) |
| Spændingsrating | **≥ 50V** |
| Forbindelse | Serie med TX spole |
| Resonansfrekvens (1µF) | ~3.6 kHz |
| Resonansfrekvens (3.2µF) | 2000 Hz |

> [!warning] Spændingsrating
> Ved resonans forstærkes spændingen med Q-faktoren!
> Brug minimum 50V kondensator.

### 4.4 Q-Faktor

$$Q = \frac{X_L}{R_{total}} = \frac{2\pi f L}{R} = \frac{2\pi \times 2000 \times 0.00197}{35} = 0.71$$

> [!note] Lav Q-faktor
> Med 32Ω serie modstand er total R = 35Ω, hvilket giver lav Q ≈ 0.7.
> Dette giver bredere båndbredde og mere stabil drift.

![[tx_current_vs_resistance.png]]
*Figur: H-bro TX strøm vs total modstand (18 Vpp). Ved R_total = 35Ω fås I_RMS = 364 mA.*

---

## 5. Kredsløbsdiagram

### 5.1 TX Kredsløb (Serie RLC)

```
                    H-BRO FORSTÆRKER
                         │
                         ▼
        ┌─────────────────────────────────────┐
        │                                     │
        │    ┌────────┐      ┌────────┐      │
        │    │   C1   │      │   L1   │      │
        ├────┤  1µF   ├──────┤ 1.97mH ├──────┤
        │    │  50V+  │      │  TX    │      │
        │    └────────┘      └────────┘      │
        │                                     │
        └─────────────────────────────────────┘
                         │
                         ▼
                        GND
```

### 5.2 Komplet TX System

```
     Arduino Nano                H-Bro Driver              LC Tank
    ┌───────────┐             ┌─────────────┐         ┌──────────────┐
    │           │   D9/D10    │  IRF5305    │         │              │
    │  Timer0   ├────────────►│  IRL530     ├────────►│  C    L      │
    │  2kHz     │             │  H-bridge   │         │ 1µF  1.97mH  │
    │           │             │             │         │              │
    └───────────┘             └──────┬──────┘         └──────────────┘
                                     │
                                   9V Batteri
```

---

## 6. RX Spole - Specifikationer

> [!info] Prototype Værdier
> RX spolen er viklet med 445 vindinger i 3 lag på Ø50mm form.

### 6.1 Elektriske Specifikationer

| Parameter | Værdi | Noter |
|---|---|---|
| **Induktans** | **11.15 mH** | Wheeler beregnet |
| **DC Modstand** | 67.05 Ω | Med 0.15mm tråd |
| **Reaktans (X_L)** | 140 Ω | @ 2 kHz |
| **Q-faktor** | 2.1 | Ved 2 kHz |
| Vikleretning | **MOD URET** | Modsat TX |

### 6.2 Fysiske Specifikationer

| Parameter | Værdi |
|---|---|
| Form diameter | **50 mm** |
| Tråddiameter | **0.15 mm** |
| Antal vindinger | **445 vindinger** |
| Vindinger per lag | **148 vindinger** |
| Antal lag | **3 lag** |
| Aksial længde | **22.3 mm** |
| Radial tykkelse | **0.45 mm** |
| Trådlængde | **70.5 m** |
| Vikleretning | **MOD URET** |

### 6.3 Viklingsinstruktioner

```
         ←────── 22.3 mm ─────→
        ┌───────────────────────┐
Lag 3   │▒▒▒▒▒▒▒▒▒▒▒▒▒▒▒▒▒▒▒▒▒▒▒│ (vindinger 297-445)
Lag 2   │▒▒▒▒▒▒▒▒▒▒▒▒▒▒▒▒▒▒▒▒▒▒▒│ (vindinger 149-296)
Lag 1   │▒▒▒▒▒▒▒▒▒▒▒▒▒▒▒▒▒▒▒▒▒▒▒│ (vindinger 1-148)
        └───────────────────────┘
         ╔═══════════════════════╗
         ║    50 mm diameter     ║
         ╚═══════════════════════╝
```

**Vikl MOD URET** (modsat TX spolen)

### 6.4 RX Resonanskondensator (Valgfri)

For båndpasfilter ved 2 kHz med L = 11.15 mH:

$$C = \frac{1}{(2\pi \times 2000)^2 \times 0.01115} = 570\ \text{nF}$$

| Parameter | Værdi |
|---|---|
| Kapacitans | ~560-680 nF |
| Forbindelse | Parallel med RX+Bucking |
| Formål | Båndpasfilter + spændingsforstærkning |

> [!note] Højere DC modstand
> Med 0.15mm tråd er DC modstanden højere (~67Ω), men dette påvirker ikke signalbehandlingen væsentligt da RX er højimpedans.

---

## 7. Bucking Spole - Specifikationer

> [!info] Kalibreret Værdier
> Bucking spolen er kalibreret til 20 vindinger for optimal null-balance.

### 7.1 Formål

Ophæver direkte TX felt ved RX position. Forbindes i serie med RX spole.

### 7.2 Elektriske Specifikationer

| Parameter | Værdi | Noter |
|---|---|---|
| **Induktans** | **0.04 mH** | Wheeler beregnet |
| **DC Modstand** | 0.26 Ω | Med 0.56mm tråd |
| Vikleretning | **MOD URET** | Samme som RX |

### 7.3 Fysiske Specifikationer

| Parameter | Værdi |
|---|---|
| Form diameter | **60 mm** |
| Tråddiameter | **0.56 mm** |
| **Antal vindinger** | **20 vindinger** |
| Antal lag | **1 lag** |
| Aksial længde | **11.2 mm** |
| Trådlængde | **3.8 m** |
| Vikleretning | **MOD URET** |

### 7.4 Justering af Bucking Spole

```mermaid
flowchart TD
    A[Vikl alle tre spoler] --> B[Forbind RX + Bucking i serie]
    B --> C[Tænd TX med 2 kHz]
    C --> D[Mål RX+Bucking output]
    D --> E{Signal < 10mV?}
    E -->|Nej, for højt| F[TILFØJ vindinger]
    E -->|Nej, inverteret| G[FJERN vindinger]
    E -->|Ja| H[✓ Færdig]
    F --> D
    G --> D
```

**Procedure:**
1. Vikl alle tre spoler
2. Forbind RX og Bucking i serie (samme polaritet)
3. Tænd TX med 2 kHz signal (ingen metal i nærheden)
4. Mål RX+Bucking output på oscilloskop
5. Juster bucking vindinger:
   - Signal for HØJT → TILFØJ vindinger
   - Signal INVERTERET → FJERN vindinger
6. Iterer indtil signal < 10 mV

---

## 8. Oversigtstabel

```
┌─────────────────┬─────────────┬─────────────┬─────────────┐
│ Parameter       │   TX Spole  │   RX Spole  │   Bucking   │
├─────────────────┼─────────────┼─────────────┼─────────────┤
│ Form diameter   │   200 mm    │    50 mm    │    60 mm    │
│ Tråddiameter    │  0.56 mm    │   0.15 mm   │  0.56 mm    │
│ Antal vindinger │     70      │    445      │    20       │
│ Antal lag       │      2      │      3      │     1       │
│ Aksial længde   │  19.6 mm    │  22.3 mm    │  11.2 mm    │
│ Induktans       │  1.97 mH    │  11.15 mH   │  0.04 mH    │
│ DC Modstand     │   3.02 Ω    │  67.05 Ω    │  0.26 Ω     │
│ Serie Modstand  │   32 Ω 5W   │    N/A      │    N/A      │
│ Resonans C      │   1.0 µF    │   ~570 nF   │    N/A      │
│ Vikleretning    │  MED URET   │  MOD URET   │  MOD URET   │
│ Strøm (RMS)     │   364 mA    │     -       │     -       │
└─────────────────┴─────────────┴─────────────┴─────────────┘
```

---

## 9. Stykliste

### 9.1 TX Spole

| Komponent | Værdi | Antal | Noter |
|---|---|---|---|
| Kobbertråd | 0.56 mm, ~50 m | 1 | Emaljeret (44.2 m + margin) |
| Plastform | Ø200 mm | 1 | PVC rør eller 3D print |
| Film kondensator | 1.0 µF, 50V | 1 | MKP/MKT type |
| **Serie modstand** | **32 Ω, 5W** | 1 | Wirewound eller keramisk |
| Elektrisk tape | - | 1 | Til sikring |

### 9.2 RX Spole

| Komponent | Værdi | Antal | Noter |
|---|---|---|---|
| Kobbertråd | 0.15 mm, ~75 m | 1 | Emaljeret (70.5 m + margin) |
| Plastform | Ø50 mm | 1 | PVC rør |
| Film kondensator | 560 nF | 1 | Valgfri, til båndpas |

### 9.3 Bucking Spole

| Komponent | Værdi | Antal | Noter |
|---|---|---|---|
| Kobbertråd | 0.56 mm, ~5 m | 1 | Emaljeret (3.8 m + margin) |
| Plastform | Ø60 mm | 1 | PVC rør |

---

## 10. Verifikation

### 10.1 Måleudstyr

- LCR meter (induktans og modstand)
- Oscilloskop (signalkvalitet)
- Multimeter (DC modstand)

### 10.2 Acceptkriterier

| Spole | Parameter | Mål | Tolerance |
|---|---|-----|---|
| TX | Induktans | 1.97 mH | ±15% |
| TX | Spole DC Modstand | 3.02 Ω | < 5 Ω |
| TX | Serie Modstand | 32 Ω | ±5% |
| TX | Strøm (RMS) | ~364 mA | ±15% |
| RX | Induktans | 11.15 mH | ±15% |
| RX | DC Modstand | 67 Ω | < 80 Ω |
| Bucking | Vindinger | 20 | Efter kalibrering |
| System | Null balance | <10 mV | Ved RX output |

### 10.3 Tjekliste

- [x] TX spole viklet (70 vindinger, 2 lag)
- [x] TX+Bucking induktans målt: 2.03 mH
- [x] TX+Bucking DC modstand målt: 3.9 Ω
- [x] Serie modstand monteret (32 Ω, ≥5W)
- [x] RX spole viklet (445 vindinger, 3 lag)
- [x] RX induktans målt: 12.2 mH
- [x] RX DC modstand målt: 71 Ω
- [x] Bucking spole kalibreret (20 vindinger)
- [ ] Null balance opnået: _____ mV
- [ ] Resonanskondensator monteret (1.0 µF)
- [ ] TX strøm verificeret: _____ mA RMS
- [ ] System test bestået

---

## 11. MATLAB Beregner

MATLAB filer til spoledesign findes i `Docs/Matlab/`:

### 11.1 Filer

| Fil | Formål |
|-----|---|
| `Coil_Design_Multilayer.m` | Hovedscript - beregner og visualiserer spoledesign |
| `verify_coils.m` | Sammenlign LCR målinger med Wheeler teori |
| `bucking_calibration.m` | Find optimalt antal vindinger til bucking spole |
| `coil_functions.m` | Delte funktioner til spoleberegning |

> [!tip] Generer Grafer
> Kør `Coil_Design_Multilayer.m` i MATLAB for at generere graferne i `Docs/Images/`.

### 11.2 Wheeler Formler (MATLAB) - Verificeret

```matlab
% Wheeler Multilayer Inductance Formula
% Verified against LCR measurement: 2% accuracy
% Source: H.A. Wheeler, Proc. IRE, Vol. 16, No. 10, Oct. 1928

function L = wheeler_multilayer(N, r_mean, l, w)
    % N = antal vindinger
    % r_mean = middelradius [m], l = aksial længde [m], w = radial tykkelse [m]
    % Coefficient: 0.315 = 0.8/2.54 (inch to cm conversion)
    r_cm = r_mean * 100; l_cm = l * 100; w_cm = w * 100;
    L = (0.315 * r_cm^2 * N^2) / (6*r_cm + 9*l_cm + 10*w_cm) * 1e-6;  % [H]
end

function L = wheeler_single_layer(N, r, l)
    % For single-layer coils (more accurate when n_layers = 1)
    % Coefficient: 0.394 = 1.0/2.54
    r_cm = r * 100; l_cm = l * 100;
    L = (0.394 * r_cm^2 * N^2) / (9*r_cm + 10*l_cm) * 1e-6;  % [H]
end
```

### 11.3 Eksperimentel Verifikation

Testspole: Ø61.6mm form, 26 vindinger, 0.43mm tråd, 1 lag

| Parameter | Beregnet | Målt (LCR@1kHz) | Fejl |
|---|---|---|---|
| Induktans | 69 µH | 67.7 µH | **2%** |

> [!success] Formel Verificeret
> Wheeler formlen er bekræftet med 2% nøjagtighed mod LCR måling.

### 11.4 Hurtig Beregning

```matlab
% TX Spole (0.56mm tråd, 200mm form, 2 lag, 70 vindinger)
% NB: TX har "flad" geometri - forvent 5-10% undervurdering
N = 70; r_inner = 0.1; wire_d = 0.56e-3; n_layers = 2;
l = (N/n_layers) * wire_d;  % Aksial længde
w = n_layers * wire_d;      % Radial tykkelse
r_mean = r_inner + w/2;
r_cm = r_mean*100; l_cm = l*100; w_cm = w*100;
L = (0.315 * r_cm^2 * N^2) / (6*r_cm + 9*l_cm + 10*w_cm) * 1e-6
% Resultat: 1.97 mH

% Resonanskondensator for 2 kHz
f = 2000; L = 1.97e-3;
C = 1 / ((2*pi*f)^2 * L)  % Resultat: 3.2 µF
```

### 11.5 Måle-Verifikationsværktøjer

#### verify_coils.m - LCR Sammenligning

Interaktivt script til at sammenligne LCR-meter målinger med Wheeler teori.

**Brug:**
```matlab
>> verify_coils
```

Scriptet guider dig gennem:
1. Indtastning af spolespecifikationer (vindinger, lag, diameter, trådtykkelse)
2. Indtastning af LCR-målinger (induktans, impedans)
3. Automatisk beregning af teoretiske værdier
4. Sammenligning med PASS/FAIL status

**Eksempel output:**
```
┌─────────────────────────────────────────────────────────────────┐
│  COMPARISON (tolerance: +/- 10%)                                │
├─────────────────────────────────────────────────────────────────┤
│  Parameter          Theoretical   Measured     Error   Status  │
├─────────────────────────────────────────────────────────────────┤
│  TX+Bucking L        5.82 mH       5.65 mH    +3.0%   PASS   │
│  RX L                12.3 mH       11.8 mH    +4.2%   PASS   │
└─────────────────────────────────────────────────────────────────┘
```

#### bucking_calibration.m - Bucking Spole Kalibrering

Interaktivt script til at finde det optimale antal vindinger på bucking spolen for maksimal TX-felt undertrykkelse.

**Brug:**
```matlab
>> bucking_calibration
```

**Procedure:**
1. Start med flere vindinger end nødvendigt (f.eks. 35)
2. Mål RX output spænding med oscilloskop
3. Fjern én vinding ad gangen
4. Log hver måling i scriptet
5. Scriptet finder automatisk minimum (optimal null-balance)

**Kalibreringsdata gemmes i:** `bucking_calibration_data.mat`

### 11.6 Prototype Målinger vs Teori

> [!info] Måleudstyr
> LCR-meter ved 1 kHz, oscilloskop for RX output

#### Spole Specifikationer (Faktiske)

| Spole | Vindinger | Lag | Diameter | Tråddiameter | Beregnet L |
|---|---|-----|---|---|---|
| TX | 70 | 2 | 200 mm | 0.56 mm | 1.97 mH |
| Bucking | 20 | 1 | 60 mm | 0.56 mm | 0.038 mH |
| RX | 445 | 3 | 50 mm | 0.15 mm | 11.1 mH |

#### Sammenligning: Teori vs Måling

| Parameter | Beregnet | Målt | Fejl | Status |
|---|---|---|---|---|
| **TX+Bucking L** | 2.01 mH | 2.03 mH | **+1.0%** | PASS |
| **RX L** | 11.1 mH | 12.2 mH | **+9.9%** | PASS |
| **TX+Bucking R** | 3.28 Ω | 3.9 Ω | **+18.9%** | PASS |
| **RX R** | 67.1 Ω | 71 Ω | **+5.8%** | PASS |

> [!success] Wheeler Formler Verificeret
> Alle målinger matcher teoretiske værdier inden for ±20% tolerance.

#### Beregnede Trådlængder og Modstande

| Parameter | TX | Bucking | RX |
|---|----|---|----|
| Tråddiameter | 0.56 mm | 0.56 mm | 0.15 mm |
| Trådlængde | 44.2 m | 3.8 m | 70.5 m |
| DC modstand (beregnet) | 3.02 Ω | 0.26 Ω | 67.1 Ω |
| DC modstand (målt) | - | **3.9 Ω** (serie) | **71 Ω** |
| **Total trådlængde** | | **118.5 m** | |

#### Bucking Spole Kalibrering

| Parameter | Værdi |
|---|---|
| Start vindinger | 35 |
| **Optimal vindinger** | **20** |
| Fjernede vindinger | 15 |

---

## 12. Konfigurationsvalg: Koncentrisk vs Double-D

### 12.1 Sammenligning

| Aspekt | Koncentrisk (Valgt) | Double-D |
|---|---|---|
| **Konstruktion** | Nemmere (cirkulære spoler) | Sværere (D-formet, præcis overlap) |
| **Følsomhed** | Bedre (ikke-mineraliseret jord) | Lidt mindre |
| **Jordafvisning** | Dårlig i mineraliseret jord | Fremragende |
| **Pinpointing** | Bedst (center-fokuseret) | God (klinge-mønster) |
| **Detektionsmønster** | Kegle (cirkulær) | Klinge (linje) |

### 12.2 Detektionsfelt Mønstre

```text
KONCENTRISK                    DOUBLE-D
  Set Ovenfra                   Set Ovenfra
 ┌─────────┐                   ┌─────────┐
╱    RX    ╲                  ╱ D     D  ╲
│   ┌───┐   │ TX              │   ╲   ╱   │
│   │ B │   │                 │    ╲ ╱    │
│   └───┘   │                 │    ╱ ╲    │
╲          ╱                  ╲  ╱   ╲   ╱
 └─────────┘                   └─────────┘

Kegleformet felt               Klingeformet felt
Bedst i centrum                Langs centerlinje
```

### 12.3 Hvorfor Koncentrisk er Valgt

> [!success] Valgt Konfiguration: Koncentrisk
> - Nemmere at konstruere inden for tidsrammen
> - Bedre pinpointing til demonstrationsformål
> - Samme PCB og kode virker - kun kalibrering ændres
> - Mulighed for DD som fremtidig opgradering

---

## 13. Relaterede Dokumenter

- [[TX Driver Design|TX Driver Design]] - H-bro forstærker
- [[Power Budget Analysis|Strømbudget Analyse]] - Arduino Nano strømbudget
- [[DFT Algorithm|DFT Algoritme]] - Signalbehandling

---

## 14. Teori Referencer (DTU Vault)

| Emne | Link | Relevans |
|---|---|---|
| Induktansberegning | [L23 - Magnetostatics II](obsidian://open?vault=Obsidian&file=Courses%2FElectromagnetics%2FFormulas%2FL23%20-%20Magnetostatics%20II) | Wheeler formel, selvinduktans |
| Magnetfelter | [Lecture 22 - Magnetostatics I](obsidian://open?vault=Obsidian&file=Courses%2FElectromagnetics%2FFormulas%2FLecture%2022%20-%20Magnetostatics%20I) | B-felt, Ampères lov, Biot-Savart |
| Permeabilitet | [Helpers (EM)](obsidian://open?vault=Obsidian&file=Courses%2FElectromagnetics%2FHelpers) | μr for ferromagnetiske materialer |
| Koordinatsystemer | [Electrostatics & Magnetostatics](obsidian://open?vault=Obsidian&file=Courses%2FElectromagnetics%2FFormulas%2FElectrostatics%20%26%20Magnetostatics) | Cylindriske koordinater |

---

*Spole design til DTU 34621 Metaldetektor Projekt*
*Opdateret til Arduino Nano og H-bro forstærker*

#spoler #design #TX #RX #bucking #flerlag

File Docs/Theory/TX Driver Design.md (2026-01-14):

# TX Driver Design - H-Bro Forstærker

> [!abstract] Dokumentformål
> Design og teori for H-bro TX driver til VLF metaldetektor.
> Konverterer 9V DC til 2kHz AC sinusstrøm gennem TX spolen.
> Simuleret effektivitet: **~98%**

---

## 1. Systemoversigt

### 1.1 Signalflow

```text
┌─────────────┐     ┌─────────────┐     ┌─────────────┐     ┌─────────────┐
│  PWM Input  │────▶│  Dead-Time  │────▶│  Bootstrap  │────▶│   H-Bridge  │────▶ TX Spole
│   (2kHz)    │     │  Generator  │     │ Gate Driver │     │  (IRL530)   │     (LC Tank)
└─────────────┘     └─────────────┘     └─────────────┘     └─────────────┘
```

### 1.2 Designkrav

| Parameter | Værdi | Kilde |
|---|---|---|
| TX Frekvens | 2 kHz | Firmware |
| TX Strøm | ~80 mA | Strømbudget |
| Forsyning | 9V (batteri) | Hardware |
| Effektivitet | > 90% | Kravspecifikation |
| Dead-time | ~15 µs | Shoot-through forebyggelse |

---

## 2. H-Bro Topologi

### 2.1 Hvorfor H-Bro?

> [!tip] DC til AC Konvertering
> H-broen skifter lastkoblingen mellem +V og GND med 180° faseforskydning.
> Kombineret med LC resonanskredsen producerer dette en ren sinusbølge.

**Fordele ved full-bridge (H-bro):**
- Dobbelt spændingssving sammenlignet med half-bridge
- Ingen DC offset i lasten
- Symmetrisk strømflow

### 2.2 Kredsløbsdiagram

```text
        +9V (V1, RSER=1.7Ω)
            │
    ┌───────┴───────┐
    │               │
   M6              M3
  (IRL530)       (IRL530)      ← High-side switches
    │               │
    ├───[C1]───[R1]───[L2]─────┤
    │   1µF    32Ω   6.3mH     │   ← RLC Tank (R_total = 35Ω)
   M4              M2          │
  (IRL530)       (IRL530)      │   ← Low-side switches
    │               │          │
    └───────┬───────┘          │
           GND◄────────────────┘
```

### 2.3 Switching Sekvens

| Fase | M6 (High-L) | M4 (Low-L) | M3 (High-R) | M2 (Low-R) | Laststrøm |
|---|---|---|---|---|---|
| A | ON | OFF | OFF | ON | +9V → Load → GND |
| Dead | OFF | OFF | OFF | OFF | Freewheel |
| B | OFF | ON | ON | OFF | GND ← Load ← +9V |
| Dead | OFF | OFF | OFF | OFF | Freewheel |

### 2.4 Komponentspecifikationer

| Komponent | Part | Specifikationer |
|---|---|---|
| M2, M3, M4, M6 | IRL530 | Vds=100V, Ids=15A, Ron=0.16Ω, Vgs(th)=2V |
| D3, D4 | 1N4148 | Freewheeling dioder |

> [!note] Logic-Level MOSFETs
> IRL530 er en logic-level MOSFET med Vgs(th)=2V.
> Dette tillader direkte drivning fra 5V MCU signaler.

---

## 3. Bootstrap Gate Driver

### 3.1 Problemet

> [!warning] High-Side N-kanal Udfordring
> For at tænde en N-kanal MOSFET skal gate være **højere** end source.
> For high-side switch er source = load voltage, som kan være op til +9V.
> Gate skal derfor være +9V **over** source = +18V totalt!

### 3.2 Løsningen: Bootstrap

Bootstrap kredsløbet skaber en **flydende forsyning** over high-side MOSFET'en:

```text
    +9V
     │
     D1 (BAS521)──────┐
     │                │
    [R1=5Ω]          [C1=1µF]  ← Bootstrap kondensator
     │                │
     └────────────────┼──── Vboot (flydende forsyning)
                      │
                     M1 (High-side)
                      │
                     OUT ──────────────────── Til last
                      │
                     M2 (Low-side)
                      │
                     GND
```

### 3.3 Bootstrap Sekvens

1. **Low-side ON**: M2 leder, OUT = GND
2. **C1 oplader**: Strøm flyder +9V → D1 → R1 → C1 → GND
3. **Low-side OFF**: Dead-time begynder
4. **High-side ON**: M1 gate drives af Vboot (OUT + 9V)
5. **C1 aflader**: Leverer gate-ladning til M1

> [!tip] Bootstrap Kondensator Størrelse
> C1 skal være stor nok til at levere gate-ladning Qg uden signifikant spændingsfald:
> $$\Delta V = \frac{Q_g}{C} = \frac{17.8\text{nC}}{1\mu\text{F}} = 17.8\text{mV}$$
> Med 1µF er spændingsfaldet negligerbart.

### 3.4 Hvorfor N-kanal på Begge Sider?

| Parameter | N-kanal | P-kanal |
|---|---|---|
| Rds(on) for samme die | **Lavere** | Højere |
| Effektivitet | **Højere** | Lavere |
| Gate drive | Kræver bootstrap | Simpel |

> [!note] Trade-off
> Bootstrap tilføjer kompleksitet, men giver **højere effektivitet**
> fordi N-kanal MOSFETs har lavere Rds(on).

---

## 4. Dead-Time Generator

### 4.1 Shoot-Through Problemet

> [!danger] Shoot-Through
> Hvis high-side og low-side i samme ben tænder samtidigt,
> opstår en kortslutning fra +9V til GND.
> Dette kan **ødelægge MOSFETs** og **dræne batteriet**.

Dead-time sikrer at begge switches er OFF under skift.

### 4.2 RC Delay Løsning

```text
                    ┌─────────────┐
     PWM_In ───────▶│   RC Delay  │
                    │  R4=R, C1=C │
                    └──────┬──────┘
                           │
              ┌────────────┴────────────┐
              ▼                         ▼
        ┌──────────┐              ┌──────────┐
        │  OpAmp1  │              │  OpAmp2  │
        │ (comp H) │              │ (comp L) │
        └────┬─────┘              └────┬─────┘
             │                         │
             ▼                         ▼
          H output                  L output
       (high-side)               (low-side)
```

### 4.3 Timing Netværk

| Komponent | Værdi | Funktion |
|---|---|---|
| R1 | 1850Ω | Spændingsdeler |
| R2 | 650Ω | Spændingsdeler |
| R3 | 2.5kΩ | Tærskel indstilling |
| R4 | R (param) | Dead-time justering |
| C1 | C (param) | Dead-time justering |

### 4.4 Dead-Time Beregning

$$t_{dead} \approx R \cdot C$$

Med R=3kΩ, C=5nF:
$$t_{dead} \approx 3\text{k}\Omega \cdot 5\text{nF} = 15\mu\text{s}$$

> [!note] Timing Sekvens
> - PWM stiger: L slukker først, derefter H tænder (efter dead-time)
> - PWM falder: H slukker først, derefter L tænder (efter dead-time)

---

## 5. LC Resonanskreds

### 5.1 Firkant til Sinus Konvertering

```text
  MCU Firkantbølge              LC Tank Output
  ┌───┐   ┌───┐                  ╭───╮   ╭───╮
  │   │   │   │                 ╱     ╲ ╱     ╲
──┘   └───┘   └──      →    ──╱       ╳       ╲──
                              ╲     ╱ ╲     ╱
                               ╰───╯   ╰───╯
```

> [!tip] LC Tank Funktion
> LC kredsen fungerer som et **båndpasfilter** der kun passerer grundfrekvensen (2kHz).
> Harmoniske fra firkantbølgen dæmpes kraftigt.

### 5.2 Resonansfrekvens

$$f_0 = \frac{1}{2\pi\sqrt{LC}} = \frac{1}{2\pi\sqrt{6.332\text{mH} \cdot 1\mu\text{F}}} \approx 2\text{kHz}$$

### 5.3 Komponentværdier

| Komponent | Værdi | Formål |
|---|---|---|
| L2 | 6.33 mH | TX spole induktans |
| C1 | 1 µF | Resonanskondensator |
| R1 | **32 Ω (5W)** | Serie modstand |
| R_coil | ~3 Ω | Spole DC modstand (0.56mm tråd) |
| **R_total** | **35 Ω** | Total kredsløbsmodstand |

### 5.4 Q-Faktor

$$Q = \frac{X_L}{R_{total}} = \frac{2\pi f L}{R} = \frac{2\pi \times 2000 \times 0.00633}{35} = 2.27$$

> [!note] Lav Q med serie modstand
> Q ≈ 2.3 giver bred båndbredde og stabil drift.
> Serie modstanden (32Ω) sænker Q og tillader ~360 mA RMS strøm.

---

## 6. Simuleringsresultater

### 6.1 Effektivitet

| Parameter | Værdi |
|---|---|
| Source Power (Psource) | ~500 mW |
| Load Power (Pl) | ~490 mW |
| Effektivitet (η) | **~98%** |

### 6.2 QSPICE Simulation

Simulationsfiler findes i `QSPICE/` mappen:

| Fil | Beskrivelse |
|-----|---|
| `Hbro_sim.qsch` | Hovedsimulation med H-bro og last |
| `bootstrap.qsch` | Bootstrap gate driver kredsløb |
| `dead_time.qsch` | Dead-time generator subcircuit |

Se [[../../QSPICE/README|QSPICE README]] for detaljer om simulering.

### 6.3 Vigtige Bølgeformer

```spice
.plot i(L2)              ; Spolestrøm (bør være sinusformet)
.plot is(M6) is(M3)      ; MOSFET strømme
.plot v(G9) v(G3,S3)     ; Gate-source spændinger
```

---

## 7. Stykliste

### 7.1 Power Stage

| Komponent | Part | Antal | Noter |
|---|---|---|---|
| MOSFET | IRL530 | 4 | Logic-level, TO-220 |
| Diode | 1N4148 | 2 | Freewheeling |

### 7.2 Gate Driver

| Komponent | Part | Antal | Noter |
|---|---|---|---|
| MOSFET | BS170 | 2 | Level shifter |
| Diode | 1N4148 | 2 | Bootstrap |
| Kondensator | 1µF | 2 | Bootstrap |
| Modstand | 1K | 2 | Pull-up |

### 7.3 Dead-Time

| Komponent | Værdi | Antal | Noter |
|---|---|---|---|
| Modstand | 3K | 1 | Parameteriserbar |
| Kondensator | 5nF | 1 | Parameteriserbar |
| Op-amp | RRopAmp | 2 | Rail-to-rail |

### 7.4 RLC Tank

| Komponent | Værdi | Antal | Noter |
|---|---|---|---|
| Spole | 6.33 mH | 1 | TX spole (0.56mm tråd) |
| Kondensator | 1µF, 50V | 1 | Film type (MKP) |
| **Serie modstand** | **32Ω, 5W** | 1 | Wirewound eller keramisk |

---

## 8. Relaterede Dokumenter

- [[Coil Design|Spole Design]] - TX spole specifikationer
- [[Power Budget Analysis|Strømbudget Analyse]] - Systemets strømforbrug
- [[DFT Algorithm|DFT Algoritme]] - Signalbehandling af RX signal
- [[../../QSPICE/README|QSPICE Simulation]] - Detaljeret simulationsguide

---

## 9. Teori Referencer

| Emne | Relevans |
|---|---|
| H-bridge switching | DC-AC konvertering |
| Bootstrap gate drive | High-side N-kanal drivning |
| LC resonance | Båndpasfiltrering |
| MOSFET switching losses | Effektivitetsberegning |

---

*TX Driver design til DTU 34621 Metaldetektor Projekt*
*Simuleret i QSPICE med ~98% effektivitet*

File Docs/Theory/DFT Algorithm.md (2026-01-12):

# DFT Algoritme

> [!abstract] Dokumentformål
> Beskrivelse af den optimerede single-bin DFT algoritme brugt i metaldetektoren.
> Se [[../Guides/Code_Review|Kodegennemgang]] for fuld firmware dokumentation.

---

## Optimeringsprincippet

> [!tip] 4× Oversampling
> Da vi sampler ved **præcis 4× signalfrekvensen** (8 kHz sampling, 2 kHz signal), bliver sinus og cosinus værdierne trivielle - **ingen trigonometriske beregninger nødvendige i ISR!**

### Koefficienter ved 4× Oversampling

| Sample n | cos(2πn/4) | -sin(2πn/4) | Operation |
|---|---|---|---|
| 0 | +1 | 0 | Re += sample |
| 1 | 0 | -1 | Im -= sample |
| 2 | -1 | 0 | Re -= sample |
| 3 | 0 | +1 | Im += sample |

> [!note] Negativ Sinus
> Vi bruger `-sin()` i den imaginære del fordi DFT formlen er:
> $$X[k] = \sum_{n=0}^{N-1} x[n] \cdot e^{-j2\pi kn/N} = \sum_{n=0}^{N-1} x[n] \cdot (\cos - j\sin)$$

---

## Algoritme Implementation

### Definitioner

```c
#define F_SAMPLE 8000       // Sample frekvens (Hz)
#define F_SIGNAL 2000       // TX/RX signal frekvens (Hz)
#define N 64                // Antal samples per DFT vindue

#define RePhase1  1         // cos(0)
#define ImPhase2  1         // sin(π/2)
#define RePhase3 -1         // cos(π)
#define ImPhase4 -1         // sin(3π/2)
#define ADC_middelvaerdi 512 // DC offset (mid-skala for 10-bit ADC)
```

### DFT Akkumulering (i ADC ISR)

```c
void DFT_sum(int16_t ADC_Raw) {
    xn = ADC_Raw - ADC_middelvaerdi;  // Fjern DC offset

    switch(j & 3) {  // j mod 4 - cykler 0,1,2,3,0,1,2,3...
        case 0: Re += RePhase1 * xn;  break;  // cos(0) = +1
        case 1: Im += -ImPhase2 * xn; break;  // -sin(π/2) = -1
        case 2: Re += RePhase3 * xn;  break;  // cos(π) = -1
        case 3: Im += -ImPhase4 * xn; break;  // -sin(3π/2) = +1
    }
    j++;

    if (j >= N) {
        Re_buff = Re;  Im_buff = Im;  // Gem resultat
        DFT_done = 1;
        Re = Im = 0;  j = 0;          // Nulstil til næste vindue
    }
}
```

### Magnitude og Fase Beregning (i hovedløkke)

```c
void DFT_Calc() {
    // Konverter til double før kvadrering for at undgå int32_t overflow
    mag = sqrt((double)Re_buff*Re_buff + (double)Im_buff*Im_buff) / N;
    ang = atan2(Im_buff, Re_buff) * 57.2957795131;  // Radianer til grader
}
```

---

## Matematisk Baggrund

### Standard DFT Formel

For bin $k$ ved frekvens $f_k = k \cdot f_s / N$:

$$X[k] = \sum_{n=0}^{N-1} x[n] \cdot e^{-j2\pi kn/N}$$

### Vores Single-Bin DFT

Vi beregner kun bin $k = N/4 = 16$ (svarende til 2 kHz):

$$X[16] = \sum_{n=0}^{63} x[n] \cdot (\cos(2\pi \cdot 16 \cdot n/64) - j\sin(2\pi \cdot 16 \cdot n/64))$$

Da $2\pi \cdot 16/64 = \pi/2$, gentager koefficienterne sig med periode 4.

---

## Integer Overflow Forebyggelse

> [!warning] 32-bit Signed Integers Påkrævet
>
> **Akkumulering (Re, Im):**
> - 64 samples × max værdi 512 (efter DC fjernelse) = 32.768
> - Passer i int16_t, men vi bruger int32_t for sikkerhed
>
> **Kvadrering i magnitude:**
> - Værst: 32768² = 1.073.741.824
> - Overstiger int32_t range (2.147.483.647 for signed)
> - **Løsning:** Cast til `double` før kvadrering

```c
// FORKERT - kan overflow:
mag = sqrt(Re_buff*Re_buff + Im_buff*Im_buff);

// KORREKT - cast til double først:
mag = sqrt((double)Re_buff*Re_buff + (double)Im_buff*Im_buff);
```

---

## Signalflow

```mermaid
flowchart TD
    ADC[ADC Sample<br>0-1023] --> DC[Fjern DC offset<br>-512]
    DC --> COEF[Multiplicer med koefficient<br>+1, -1, eller 0]
    COEF --> ACC[Akkumuler i Re eller Im]
    ACC --> CHECK{64 samples?}
    CHECK -->|Nej| ADC
    CHECK -->|Ja| CALC[Beregn magnitude og fase]
    CALC --> DISP[Vis på display]
    DISP --> ADC
```

---

## Timing

| Parameter | Værdi | Beregning |
|---|---|---|
| Sample interval | 125 µs | 1/8000 Hz |
| Samples per TX cyklus | 4 | 8000/2000 |
| TX cykler per vindue | 16 | 64/4 |
| DFT vindue varighed | 8 ms | 64 × 125 µs |
| Opdateringsrate | 125 Hz | 1/8 ms |

---

## Basisfase ved Firkantbølge

> [!important] -45° Basisfase
> Når TX firkantbølgen samples direkte (uden RC filter), måles en basisfase på **-45°**.
>
> Dette skyldes at en firkantbølge der er HØJ for samples 0,1 og LAV for samples 2,3 producerer:
> ```
> Re = x[0] - x[2] = (+A) - (-A) = +2A
> Im = -x[1] + x[3] = (-A) + (-A) = -2A
> Fase = atan2(-2A, +2A) = -45°
> ```

Se [[../Guides/Testing Guide|Testguide]] for verifikation af faseberegning.

---

## Fasefortolkning for Metaldetektion

| Faseændring | Metaltype | Fysisk Årsag |
|---|---|---|
| Mere negativ | **Ferromagnetisk** | Høj magnetisk permeabilitet (μr >> 1) |
| Mindre negativ | **Ikke-ferromagnetisk** | Hvirvelstrømme dominerer |

> [!note] Relativ Fase
> For metaldetektion er kun **ændringer** i fase vigtige, ikke absolutte værdier.
> Basisfasen (-45°) udlignes ved kalibrering.

---

## Relaterede Dokumenter

- [[../Guides/Testing Guide|Testguide]] - AD3, RC Loopback, MATLAB verifikation
- [[../Guides/Code_Review|Firmware Kodegennemgang]]

---

## Teori Referencer (DTU Vault)

| Emne | Link | Relevans |
|---|---|---|
| DFT/FFT Teori | [DSP-Bible](obsidian://open?vault=Obsidian&file=Courses%2FDSP%2FFormulas%2FDSP-Bible) | Komplet DFT formelsamling |
| Sampling & Frekvens | [Week 1-4](obsidian://open?vault=Obsidian&file=Courses%2FDSP%2FFormulas%2FWeek%201-4) | Nyquist, DTFT, frekvensrepræsentationer |
| 4× Oversampling | [Multirate DSP](obsidian://open?vault=Obsidian&file=Courses%2FDSP%2FFormulas%2FMultirate%20Digital%20Signal%20Processing) | Oversampling teori |
| Komplekse Tal | [Manual_Math_Complete_Guide](obsidian://open?vault=Obsidian&file=Courses%2FDSP%2FFormulas%2FManual_Math_Complete_Guide) | Fasevinkel, polær/rektangulær |

---

*Dokument opdateret til at matche nuværende firmware implementation*

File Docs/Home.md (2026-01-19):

# DTU 34621 - Metal Detector Project

> **Course:** 34621 Electromagnetic Sensors and Digital Signal Processing
> **Institution:** DTU Diplom
> **Project:** VLF Metal Detector
> **Team:** Mads Rudolph, Andreas Skaaning, Jonas Beck & Sigurd Hestbech

---

## Documentation

### Guides
| Document | Description |
|---|---|
| [[Docs/Guides/Code_Review\|Code Review]] | Firmware arkitektur og kode gennemgang |
| [[Docs/Guides/Assembly_Guide\|Assembly Guide]] | Hardware opsætning og wiring |
| [[Docs/Guides/Test_Guide_AD3\|Test Guide (AD3)]] | Test med Analog Discovery 3 |

### Theory
| Document | Description |
|---|---|
| [[Docs/Theory/DFT Algorithm\|DFT Algorithm]] | 4x oversampling DFT forklaring |
| [[Docs/Theory/Coil Design\|Coil Design]] | Spole specifikationer (MATLAB-verificeret) |
| [[Docs/Theory/Coil Configuration Comparison\|Coil Configurations]] | Concentric vs Double-D sammenligning |
| [[Docs/Theory/TX Driver and Tank Circuit Design\|TX Driver Design]] | Driver kredsløb og tank circuit |
| [[Docs/Theory/Power Budget Analysis\|Power Budget]] | Strømforbrug analyse |
| [[Docs/Theory/Theory References\|Theory References]] | Links til DTU kursusmateriale |

### Other
| Section | Description |
|---|---|
| [[Code/README\|Code]] | Arduino Nano firmware |
| [[Docs/Meetings\|Meetings]] | Mødereferater |
| [[Literature/README\|Literature]] | Datasheets og kursusmateriale |

---

## Project Requirements (Kravspecifikation)

### Priority 1 (Must Have)
- [x] **1.** Amplitude/phase detection
- [x] **2.** Distinguish ferrous/non-ferrous metals
- [ ] **3.** Detect iron (r=15mm, l=50mm) at 50mm depth *(hardware)*
- [ ] **4.** 9V battery powered (single 6LR61) *(hardware)*
- [ ] **5.** 100 min runtime, >6V remaining *(hardware)*
- [x] **6a.** Arduino-based processor
- [ ] **6b.** Discrete components for coil drive/amp *(hardware)*
- [x] **8a.** Display amplitude & phase
- [x] **8b.** Display readability (stable values)
- [x] **9a.** Start/stop button
- [x] **9b.** Calibration button (zero when no metal)
- [x] **10.** VLF detection principle
- [x] **11.** Sampling frequency 8 kHz
- [x] **12.** Detection frequency 2 kHz
- [ ] **16.** RX coil inductance >= 10 mH *(hardware)*

### Priority 2 (Should Have)
- [x] **7.** Timer interrupt ADC control
- [x] **8c.** IIR filter for display smoothing
- [ ] **13.** Enclosure *(hardware)*
- [ ] **14.** Coil mount *(hardware)*
- [ ] **15.** Centered coil design (TX outer, RX inner) *(hardware)*

---

## System Architecture

```
                          TX PATH
┌─────────┐    ┌─────────┐    ┌─────────┐
│  Timer0 │───>│  Pin 9  │───>│ TX Coil │
│  8kHz   │    │  2kHz   │    │  15mH   │
└─────────┘    └─────────┘    └────┬────┘
     │                             │
     │                        [Metal]
     │                             │
     │              RX PATH        v
┌────┴────┐    ┌─────────┐    ┌─────────┐
│   ADC   │<───│  Pin A0 │<───│ RX Coil │
│  10-bit │    │  8kHz   │    │  10mH   │
└────┬────┘    └─────────┘    └─────────┘
     │
     v
┌─────────┐    ┌─────────┐    ┌─────────┐
│   DFT   │───>│  Mag/   │───>│  OLED   │
│ 64 samp │    │  Phase  │    │ Display │
└─────────┘    └─────────┘    └─────────┘
```

---

## Key Parameters

| Parameter | Value | Notes |
|---|---|---|
| MCU | ATmega328P | Arduino Nano |
| TX Frequency | 2 kHz | Timer0 generated |
| Sample Rate | 8 kHz | 4x oversampling |
| ADC Resolution | 10-bit | Internal ADC |
| DFT Window | 64 samples | 8ms window |
| Phase Threshold | 65 deg | Ferrous/non-ferrous |

---

## External Resources

- [[Literature/Automotive-Microcontrollers-ATmega328P_Datasheet.pdf|ATmega328P Datasheet]]
- [SSD1306 OLED Datasheet](https://cdn-shop.adafruit.com/datasheets/SSD1306.pdf)

---

## Timeline

- **Final report deadline:** 23/1-2026

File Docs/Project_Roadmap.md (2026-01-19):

# Projekt Køreplan - VLF Metaldetektor

> [!abstract] Dokumentformål
> Omfattende projektstatus, kravanalyse og implementeringskøreplan for DTU 34621 Metaldetektor projektet.
>
> **Sidst Opdateret:** 2026-01-19
> **Kursus:** DTU 34621 - Indlejrede Systemer

---

## 1. Projektstatus Oversigt

### 1.1 Samlet Færdiggørelse

| Kategori | Færdiggørelse | Noter |
|---|---|---|
| **Software Kerne** | 95% | TX, ADC, DFT, IIR filter, klassificering |
| **Software UI** | 95% | Knapper, grafisk HUD, buzzer, jingle |
| **Hardware** | 40% | Designet, delvist bygget |
| **Integration** | 10% | Afventer hardware |
| **Samlet** | ~75% | Software feature-komplet |

### 1.2 Hvad Virker Nu

- TX signalgenerering (2 kHz firkantbølge på Pin 9)
- ADC sampling (8 kHz, auto-triggered fra Timer0)
- DFT beregning (64-sample vindue, single-bin ved 2 kHz)
- Magnitude og fase beregning
- IIR filter til stabil visning (alpha = 0.15)
- Metal klassificering (ferro/non-ferro baseret på fase)
- Start/Stop knap (D2) - toggle detektor on/off
- Kalibrering knap (D3) - gem baseline aflæsning
- Debug knap (D4) - skift mellem DFT/Debug skærm
- Grafisk HUD display med ikoner (metal type, signal styrke)
- Progress bar til signal niveau
- Buzzer feedback ved metal detektion
- Startup jingle ved opstart
- Splash screen med logo
- Modulær kodestruktur (11 moduler + include/ mappe)
- Verificeret med RC loopback test (-145 grader fase målt)

### 1.3 Hvad Mangler

**Software:**
- ~~Metaltype klassificering (ferro vs ikke-ferro)~~ ✅ Færdig
- ~~Start/Stop knap funktionalitet~~ ✅ Færdig
- ~~Kalibrering/nulstillingsknap funktionalitet~~ ✅ Færdig
- ~~IIR/FIR filter til display udjævning~~ ✅ Færdig
- ~~Tilstandsmaskine for driftstilstande~~ ✅ Færdig
- Evt. EEPROM persistens af kalibrering (valgfrit)

**Hardware:**
- TX driver H-bro (designet, delvist bygget)
- RX forstærker kredsløb (designet, delvist bygget)
- TX/RX/Bucking spoler (designet, ikke viklet)
- Fuld system strømtest

---

## 2. Færdiggjorte Funktioner

| Krav # | Navn | Beskrivelse | Verificeret | Noter |
|---|---|---|---|---|
| 1 | Amplitude/fase detektion | DFT beregner magnitude og fase | Ja | RC loopback testet |
| 6a | Processor design | Arduino Nano (ATmega328P) | Ja | PlatformIO projekt |
| 7 | Muligt software design | ADC med timer interrupts | Ja | Auto-trigger virker |
| 8a | Bruger interface display | OLED viser amplitude og fase | Ja | SSD1306 I2C |
| 10 | Detektions princip | VLF drift | Ja | 2 kHz detektion |
| 11 | Samplingsfrekvens | 8 kHz sampling | Ja | Timer0 verificeret |
| 12 | Detektionsfrekvens | 2 kHz TX frekvens | Ja | Oscilloskop verificeret |

---

## 3. Udestående Opgaver

### 3.1 Software - Kritisk (Prioritet 1)

| Hastighed | Opgave | Krav # | Status | Indsats |
|---|---|---|---|---|
| 1 | Metaltype klassificering | 2 | ✅ Færdig | Middel |
| 2 | Start/Stop knap | 9a | ✅ Færdig | Let |
| 3 | Kalibrering/nulstillingsknap | 9b | ✅ Færdig | Middel |
| 4 | Display stabilitet (basis) | 8b | ✅ Færdig | Let |

### 3.2 Software - Valgfri (Prioritet 2)

| Hastighed | Opgave | Krav # | Status | Indsats |
|---|---|---|---|---|
| 5 | IIR/FIR filter udjævning | 8c | ✅ Færdig | Middel |
| 6 | Kode modularisering | - | ✅ Færdig | Svær |
| 7 | Buzzer audio feedback | - | ✅ Færdig | Let |
| 8 | Grafisk HUD med ikoner | - | ✅ Færdig | Middel |
| 9 | Startup jingle | - | ✅ Færdig | Let |
| 10 | Splash screen | - | ✅ Færdig | Let |

### 3.3 Hardware - Kritisk (Prioritet 1)

| Hastighed | Opgave | Krav # | Status | Indsats |
|---|---|---|---|---|
| 1 | TX driver H-bro bygning | 6b | I Gang | Middel |
| 2 | RX forstærker bygning | 6b | I Gang | Middel |
| 3 | Spolevinding (TX, RX, Bucking) | 16 | Ikke Startet | Middel |
| 4 | System integration | 6b | Blokeret | Svær |
| 5 | Strømforsyning fra 9V | 4 | Ikke Startet | Let |
| 6 | Køretidstest (100 min) | 5 | Blokeret | Middel |
| 7 | Detektionsafstand test (50mm) | 3 | Blokeret | Middel |

### 3.4 Hardware - Valgfri (Prioritet 2)

| Hastighed | Opgave | Krav # | Status | Indsats |
|---|---|---|---|---|
| 8 | Kabinet/indkapsling | 13 | Ikke Startet | Middel |
| 9 | 3D printet spoleform | 14 | I Gang | Let |
| 10 | Koncentrisk spole samling | 15 | Blokeret | Middel |

---

## 4. Detaljeret Opgaveopdeling

### 4.1 Metaltype Klassificering (Krav 2)

| Felt | Værdi |
|---|---|
| **Krav** | 2 - Metal type |
| **Status** | Ikke Startet |
| **Indsats** | Middel |
| **Afhængigheder** | Virkende DFT (færdig), Hardware integration |
| **Ansvarlig** | Software |

**Beskrivelse:**
Implementer fasebaseret metalklassificering for at skelne ferromagnetiske (jern/stål) fra ikke-ferromagnetiske (kobber, messing, aluminium) metaller.

**Implementation:**
1. Gem kalibrerings baseline (luft aflæsning)
2. Beregn delta fase fra baseline
3. Anvend tærskel klassificering:
   - Negativ faseskift (mere negativ) = Ferromagnetisk
   - Positiv faseskift (mindre negativ) = Ikke-ferromagnetisk
4. Vis metaltype indikator på OLED

**Kode Placering:** `main.c` - tilføj efter `DFT_Calc()`

```c
// Pseudokode
#define FERRO_THRESHOLD -10  // grader relativt til baseline
int16_t delta_phase = ang - baseline_phase;
uint8_t metal_type = (delta_phase < FERRO_THRESHOLD) ? FERRO : NON_FERRO;
```

---

### 4.2 Start/Stop Knap (Krav 9a)

| Felt | Værdi |
|---|---|
| **Krav** | 9a - Bruger interface primære knapper |
| **Status** | Ikke Startet |
| **Indsats** | Let |
| **Afhængigheder** | Ingen |
| **Ansvarlig** | Software |

**Beskrivelse:**
Tilføj en start/stop knap til at styre detektor drift. Pt. eksisterer kun en debug skift-knap på Pin D4.

**Implementation:**
1. Udpeg en pin til Start/Stop (foreslået Pin D2 eller D3)
2. Tilføj tilstandsvariabel: `detector_running`
3. Skift tilstand ved knaptryk
4. Når stoppet: deaktiver TX, vis "STOPPET" på display
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

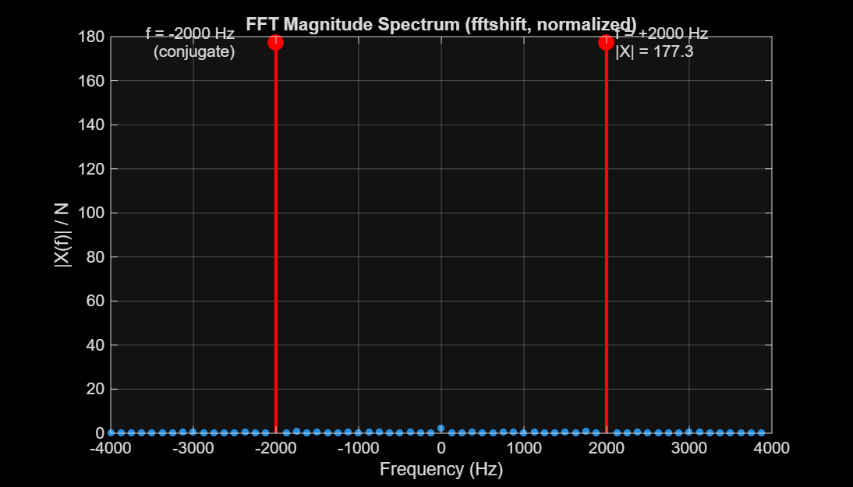
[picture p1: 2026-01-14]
Docs/Images/dft_spectrum.png

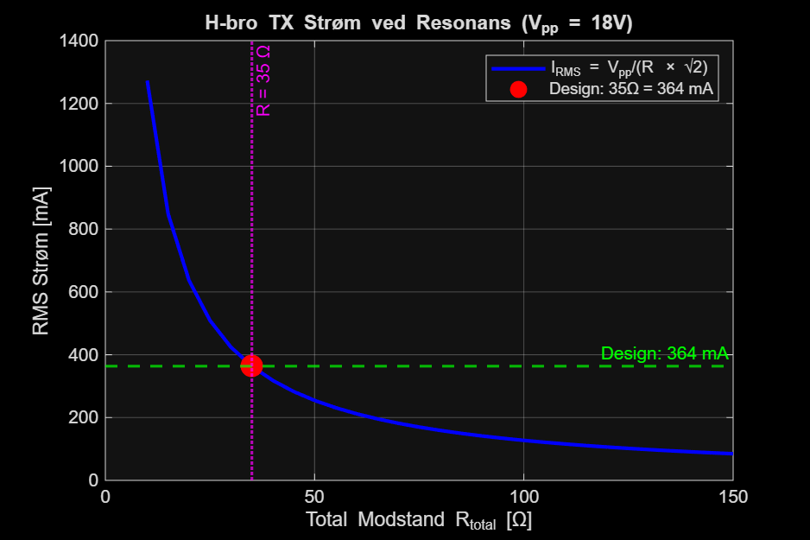
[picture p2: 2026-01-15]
Docs/Images/tx_current_vs_resistance.png

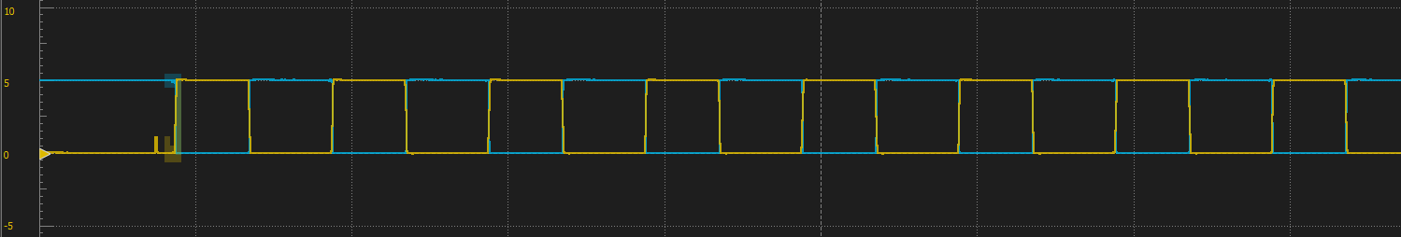
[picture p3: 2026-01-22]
Docs/Images/Deadtime_Blue-PWM1_not_Yellow-PWM1.png

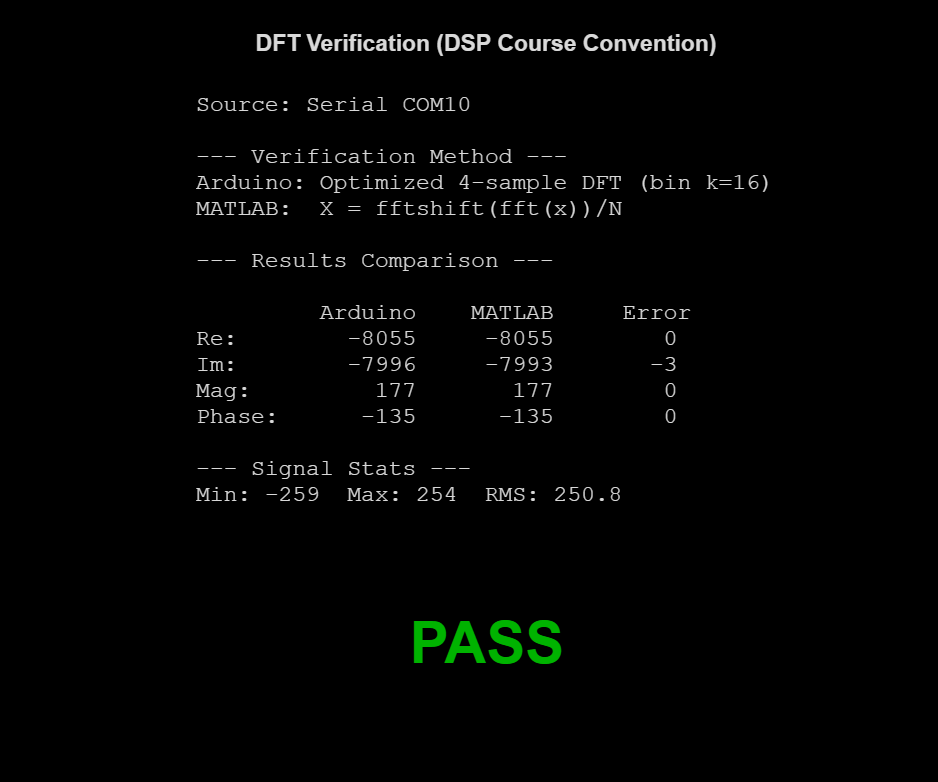
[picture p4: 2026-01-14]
Docs/Images/dft_comparison.png

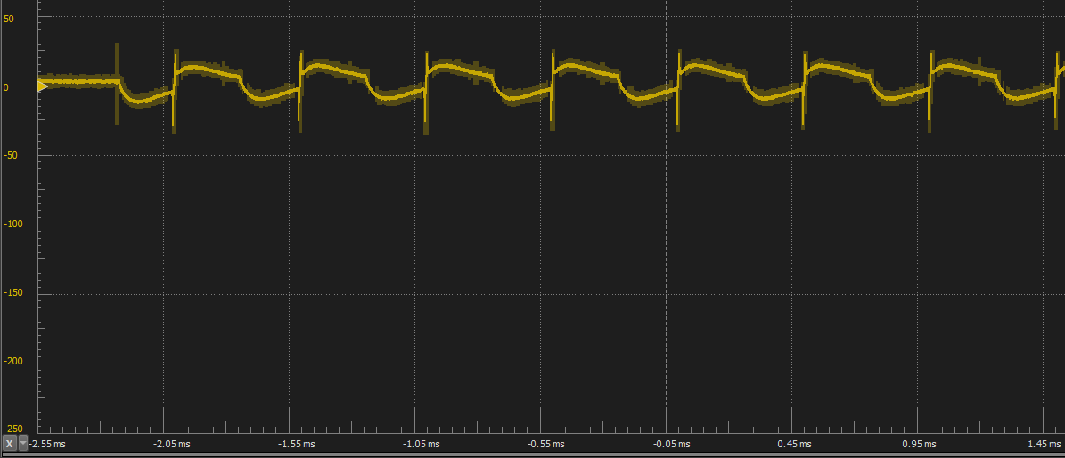
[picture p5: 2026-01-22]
assets/photos/LC_Tank_current.png

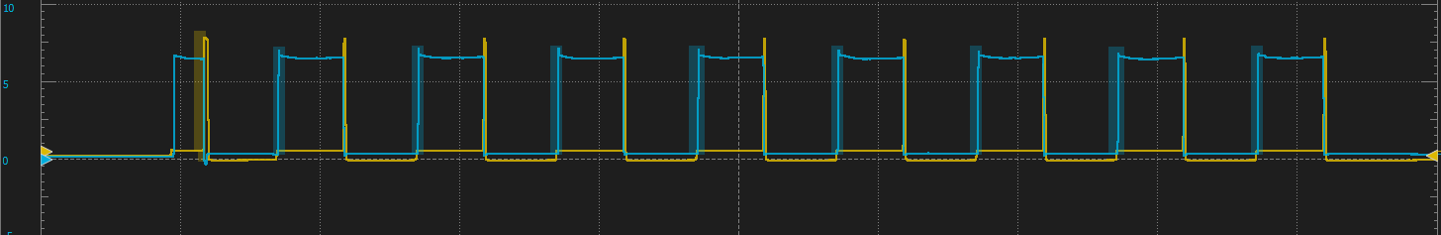
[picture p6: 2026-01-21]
Docs/Images/Gates/Hout_yellow-højre_Vout_blue-left.png

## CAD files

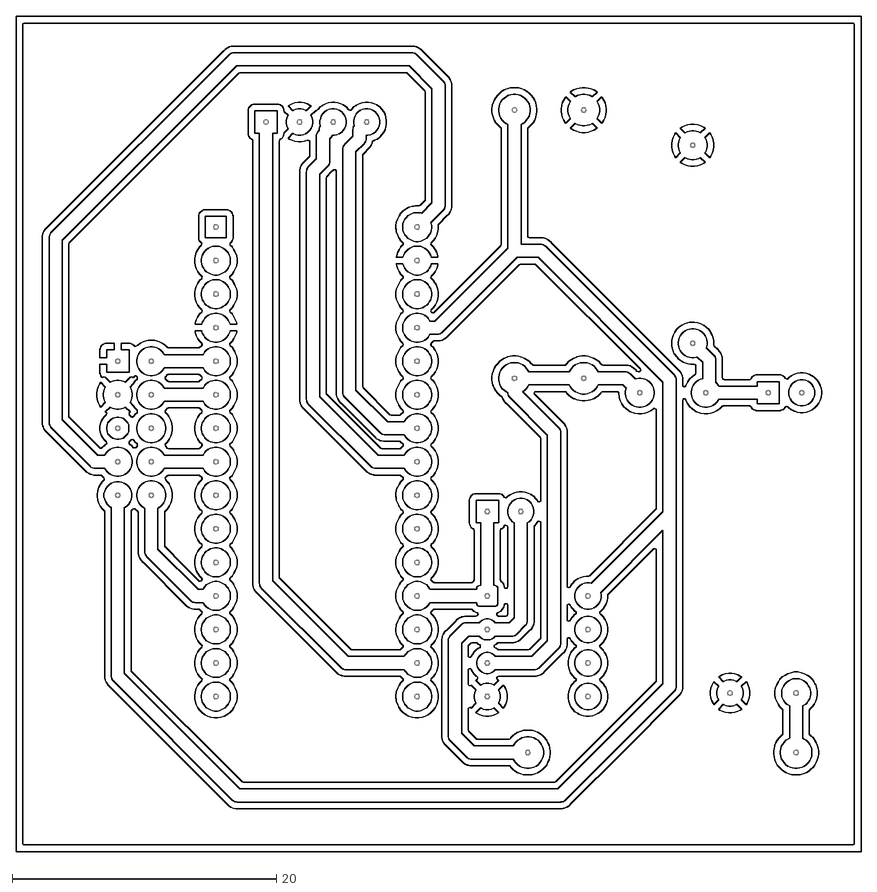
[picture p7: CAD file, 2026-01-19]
KiCad/DXF filer til pcb/rx forstærker-B_Cu.dxf
64.0 x 63.2

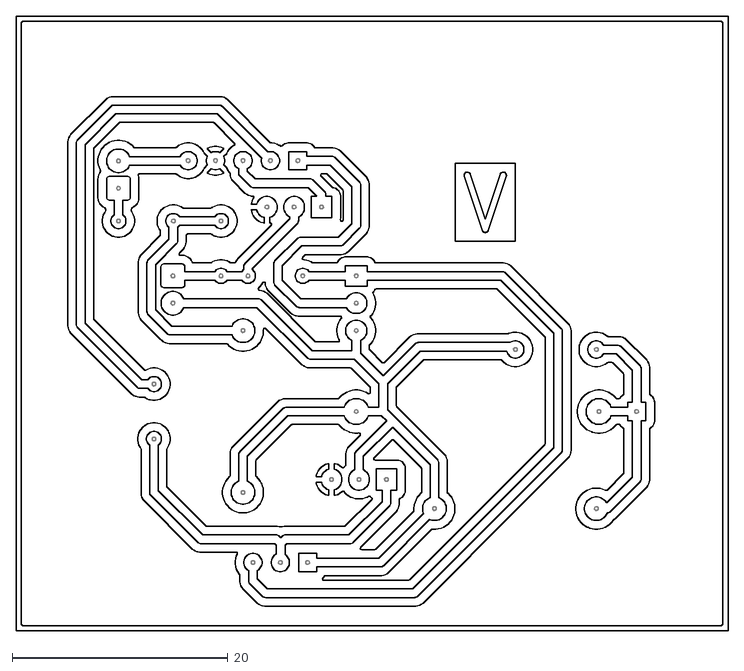
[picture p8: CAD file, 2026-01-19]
KiCad/PCB DXF filer/Venstre-B_Cu.dxf
66.0 x 57.0

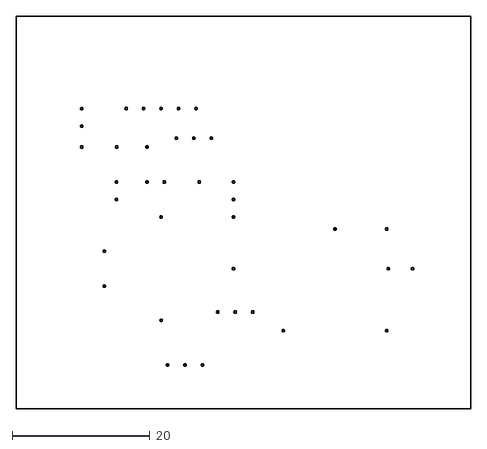
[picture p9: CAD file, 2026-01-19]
KiCad/PCB DXF filer/Venstre-Edge_Cuts.dxf
66.0 x 57.0

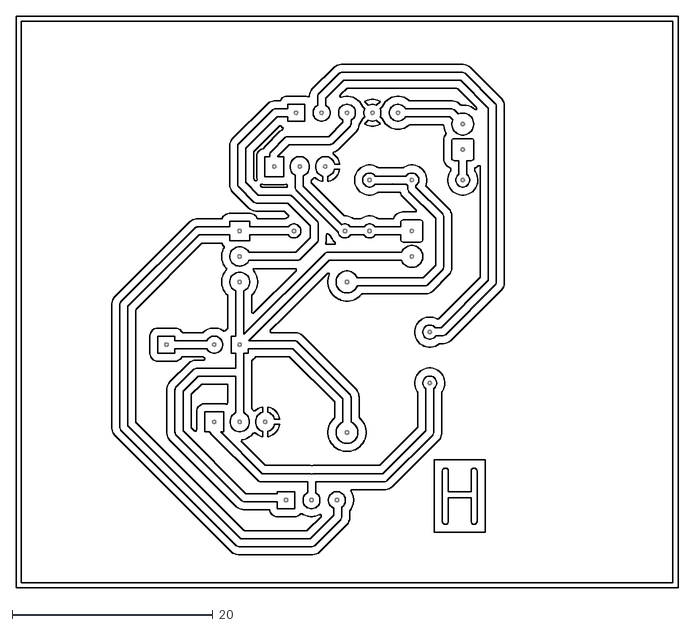
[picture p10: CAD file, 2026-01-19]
KiCad/PCB DXF filer/Højre-B_Cu.dxf
66.0 x 57.0

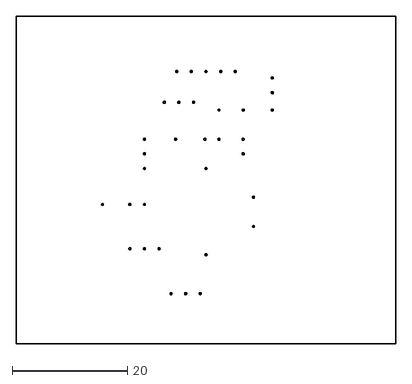
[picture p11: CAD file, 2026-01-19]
KiCad/PCB DXF filer/Højre-Edge_Cuts.dxf
66.0 x 57.0

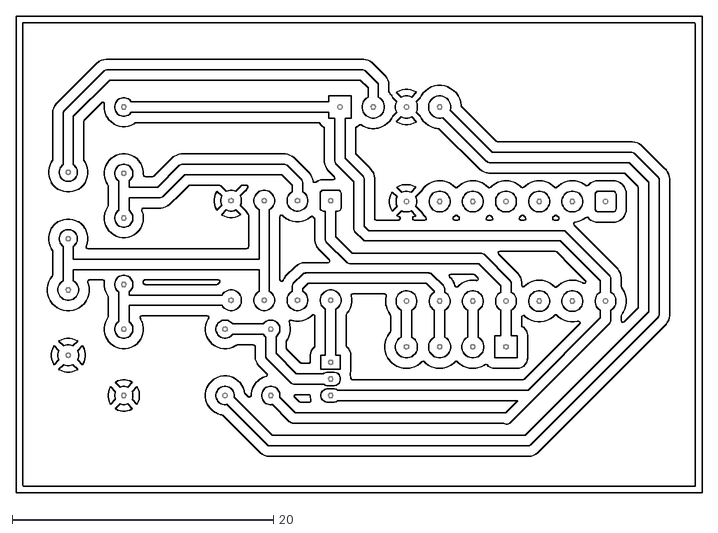
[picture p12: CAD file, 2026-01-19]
KiCad/PCB DXF filer/Dead_Time-B_Cu.dxf
52.5 x 36.5

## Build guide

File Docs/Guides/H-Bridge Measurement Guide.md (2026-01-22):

# H-Bridge Forstærker Måleguide

> [!abstract] Dokumentformål
> Måleguide til karakterisering af H-bro forstærkeren med Analog Discovery 3.
> Bruger de dedikerede målepunkter i skemaerne til systematisk verifikation.

---

## Indholdsfortegnelse

1. [[#1. Oversigt]]
2. [[#2. Udstyr]]
3. [[#3. Målepunkter]]
4. [[#4. Forbindelser]]
5. [[#5. Test 1 - Deadtime Verifikation]]
6. [[#6. Test 2 - Gate Drive Signaler]]
7. [[#7. Test 3 - Half-Bridge Output]]
8. [[#8. Test 4 - Differentielt Output]]
9. [[#9. Test 5 - LC Tank Strøm]]
10. [[#10. Test 6 - RX Spole Respons]]
11. [[#11. Fejlfinding]]
12. [[#12. Relaterede Dokumenter]]

---

## 1. Oversigt

### 1.1 Formål

Denne guide beskriver systematisk verifikation af H-bro forstærkeren ved hjælp af de dedikerede målepunkter i kredsløbet. Testene verificerer:

1. **Deadtime kredsløb** - Ikke-overlappende PWM signaler
2. **Gate drive** - Bootstrap driver funktion
3. **Half-bridge output** - Switching ved midtpunkt
4. **Differentielt output** - Fuld H-bro spænding
5. **LC tank strøm** - Sinusformet strøm gennem TX spole
6. **RX spole respons** - Metaldetektion verifikation

### 1.2 Anbefalet Testrækkefølge

```text
Deadtime ──▶ Gate Drive ──▶ Half-Bridge ──▶ Diff. Output ──▶ LC Tank ──▶ RX Respons
```

> [!warning] Start med lav spænding
> Ved første test, brug lavere forsyningsspænding (f.eks. 5V i stedet for 9V) for at beskytte komponenter ved eventuelle fejl.

---

## 2. Udstyr

| Udstyr | Noter |
|---|---|
| Analog Discovery 3 | Med WaveForms software |
| Oscilloskop probes | 10:1 anbefales til gate signaler |
| Jumperwires | Til målepunkt forbindelser |
| DC forsyning | 9V til H-bro, 5V til logik |
| Multimeter | Til DC verifikation |

### 2.1 AD3 Pin Reference

```text
Analog Discovery 3 Connector:
┌─────────────────────────────────────────────────┐
│  1+  1-  2+  2-  W1  W2  T1  T2  T3  ...  GND  │
│  ●   ●   ●   ●   ●   ●   ●   ●   ●        ●   │
│  Scope Ch1  Scope Ch2  Wavegen   Triggers      │
└─────────────────────────────────────────────────┘

1+/1- = Oscilloskop Kanal 1 (orange/orange-hvid)
2+/2- = Oscilloskop Kanal 2 (blå/blå-hvid)
W1    = Bølgegenerator 1 udgang (gul)
GND   = Stel (sort)
```

---

## 3. Målepunkter

### 3.1 Venstre H-Bro (V_Meas1 Connector)

| Pin | Signal | Beskrivelse |
|-----|---|---|
| 1 | `Meas_V_Out` | Venstre half-bridge output |
| 2 | `Meas_GATE_M3` | Low-side gate (Q3) |
| 3 | `Meas_GATE_M1` | High-side gate (Q1) |

### 3.2 Højre H-Bro (Meas_H1 Connector)

| Pin | Signal | Beskrivelse |
|-----|---|---|
| 1 | `Meas_H_Out` | Højre half-bridge output |
| 2 | `Meas_GATE_M4` | Low-side gate (Q4) |
| 3 | `Meas_GATE_M2` | High-side gate (Q2) |

### 3.3 Deadtime Kredsløb (Dead_Time_Outputs1 Connector)

| Pin | Signal | Beskrivelse |
|-----|---|---|
| 1 | `PWM1` | Komparator output 1 |
| 2 | `PWM1_NOT` | Inverteret PWM1 |
| 3 | `PWM2` | Komparator output 2 |
| 4 | `PWM2_NOT` | Inverteret PWM2 |

### 3.4 Input (Dead_Time_Inputs1 Connector)

| Pin | Signal | Beskrivelse |
|-----|---|---|
| 1 | `PWM_In` | PWM input fra MCU |
| 2 | `+5V` | Logik forsyning |
| 3 | `GND` | Stel |

### 3.5 Blodiagram

```text
                    ┌─────────────────┐
                    │  DEADTIME PCB   │
                    │                 │
    PWM_In ────────▶│  PWM1 ─────────▶├──────▶ Meas_GATE_M1 (Q1)
                    │  PWM1_NOT ─────▶├──────▶ Meas_GATE_M3 (Q3)
                    │                 │        ├──▶ Meas_V_Out
                    │  PWM2 ─────────▶├──────▶ Meas_GATE_M2 (Q2)
                    │  PWM2_NOT ─────▶├──────▶ Meas_GATE_M4 (Q4)
                    │                 │        ├──▶ Meas_H_Out
                    └─────────────────┘
                                              │         │
                                              └────┬────┘
                                                   │
                                              LC Tank Input
                                            (Diff: V_Out - H_Out)
```

---

## 4. Forbindelser

### 4.1 Generelle Retningslinjer

> [!important] Stel Reference
> Forbind altid AD3 GND til kredsløbets GND før andre forbindelser.

| AD3 Pin | Farve | Typisk Brug |
|---|---|---|
| 1+ | Orange | Primær måling |
| 1- | Orange/hvid | GND reference |
| 2+ | Blå | Sekundær måling |
| 2- | Blå/hvid | GND reference |
| GND | Sort | Fælles stel |

### 4.2 Probe Indstillinger

| Signaltype | Probe | Spændings­område |
|---|---|---|
| Gate signaler | 10:1 | 0-15V |
| PWM logik | 1:1 | 0-5V |
| Bridge output | 10:1 | 0-9V |

---

## 5. Test 1 - Deadtime Verifikation

### 5.1 Formål

Verificer at deadtime kredsløbet genererer ikke-overlappende PWM signaler med korrekt deadtime.

### 5.2 Forbindelser

| AD3 Pin | Målepunkt | Signal |
|---|---|---|
| 1+ | Dead_Time_Outputs1 pin 1 | PWM1 |
| 2+ | Dead_Time_Outputs1 pin 2 | PWM1_NOT |
| GND | GND | Stel |

### 5.3 WaveForms Scope Indstillinger

| Parameter | Værdi |
|---|---|
| Kanal 1 | Aktiveret, DC kobling |
| Kanal 2 | Aktiveret, DC kobling |
| Område | 0-5V |
| Tid/Div | 50 µs |
| Trigger | Ch1, Stigende, 2.5V |
| Sample Rate | ≥10 MS/s |

### 5.4 Forventet Resultat

| Måling | Forventet | Tolerance |
|---|---|---|
| PWM1 frekvens | 2.000 kHz | ±1% |
| Duty cycle | 50% | ±2% |
| Deadtime | ~15 µs | ±5 µs |
| High niveau | 5V | ±0.2V |
| Low niveau | 0V | ±0.2V |

### 5.5 Verifikationsmetode

1. Mål tiden fra PWM1 faldende flanke til PWM1_NOT stigende flanke
2. Mål tiden fra PWM1_NOT faldende flanke til PWM1 stigende flanke
3. Begge tider skal være ~15µs (deadtime)

```text
PWM1      ────┐     ┌─────────────┐     ┌────
             │     │             │     │
             └─────┘             └─────┘

PWM1_NOT  ────────┐     ┌───────────┐     ┌──
                  │     │           │     │
             ─────┘     └───────────┘     └──
                  │◄───►│
                  Deadtime (~15µs)
```

### 5.6 Måleresultater

#### Deadtime Oversigt

![[../Images/Deadtime_Blue-PWM1_not_Yellow-PWM1.png]]

**Observation:** PWM1 (gul) og PWM1_NOT (blå) viser komplementære signaler. Når PWM1 er høj, er PWM1_NOT lav og omvendt. Signalerne overlapper ikke - deadtime kredsløbet fungerer korrekt.

#### Deadtime Detalje (5 µs/div)

![[../Images/Deadtime_Blue-PWM1_not_Yellow-PWM1___5_us.png]]

**Observation:** Ved højere tidsopløsning ses deadtime tydeligt mellem flankerne. Der er en kort periode hvor begge signaler er lave, hvilket forhindrer shoot-through i H-broen.

### 5.7 Fejlfinding

| Problem | Mulig Årsag | Løsning |
|---|---|---|
| Ingen deadtime | RC tidskonstant forkert | Tjek R/C værdier i deadtime kredsløb |
| Overlap mellem signaler | Komparator offset | Justér threshold spændinger |
| Ustabilt signal | Dårlig stel | Brug kortere GND forbindelse |

---

## 6. Test 2 - Gate Drive Signaler

### 6.1 Formål

Verificer at bootstrap gate driver leverer korrekte Vgs niveauer til high-side og low-side MOSFETs.

### 6.2 Forbindelser

| AD3 Pin | Målepunkt | Signal |
|---|---|---|
| 1+ | V_Meas1 pin 3 | Meas_GATE_M1 (high-side) |
| 2+ | V_Meas1 pin 2 | Meas_GATE_M3 (low-side) |
| GND | GND | Stel |

### 6.3 WaveForms Scope Indstillinger

| Parameter | Værdi |
|---|---|
| Kanal 1 | Aktiveret, DC kobling, 10:1 probe |
| Kanal 2 | Aktiveret, DC kobling, 10:1 probe |
| Område | -5V til +15V |
| Tid/Div | 100 µs |
| Trigger | Ch2, Stigende, 2V |

### 6.4 Forventet Resultat

| Måling | Forventet | Tolerance |
|---|---|---|
| Low-side Vgs (høj) | ~9V | ±1V |
| Low-side Vgs (lav) | ~0V | ±0.5V |
| High-side Vgs (høj) | ~9V over source | ±1V |
| Komplementær operation | 180° fase | - |
| Ingen overlap | Deadtime synlig | ~15µs |

### 6.5 Gate Drive Timing

```text
GATE_M3   ────┐           ┌─────────────┐
(Low-side)    │           │             │
              └───────────┘             └───────

GATE_M1   ────────┐           ┌───────────┐
(High-side)       │           │           │
              ────┘           └───────────┘
                  │◄─────────►│
                   Komplementær
```

> [!tip] Bootstrap Verifikation
> High-side gate spændingen skal være relativ til source (som svinger med output). Brug scope math: CH1 - output for at se Vgs direkte.

### 6.6 Måleresultater

![[../Images/Gate_drive_signal_left_Yellow-Highside_Blue-lowside.png]]

**Observation:**
- **Gul (CH1):** High-side gate (Meas_GATE_M1) - svinger fra 0V til ~15V relativt til GND. Dette er korrekt da bootstrap driveren løfter gate spændingen over source.
- **Blå (CH2):** Low-side gate (Meas_GATE_M3) - svinger fra 0V til ~9V.
- Signalerne er komplementære med synlig deadtime mellem skift.
- High-side gate når ~15V fordi source (switching node) er på ~6-9V når MOSFET er tændt, og gate skal være ~9V over source.

### 6.7 Fejlfinding

| Problem | Mulig Årsag | Løsning |
|---|---|---|
| High-side Vgs for lav | Bootstrap kondensator ikke opladet | Verificer low-side switch aktivt |
| Gate signal mangler | Driver defekt | Tjek driver IC forsyning |
| Langsom flanke | Gate modstand for høj | Verificer gate modstand værdi |

---

## 7. Test 3 - Half-Bridge Output

### 7.1 Formål

Verificer switching waveform ved half-bridge midtpunkterne og kontroller 180° faseforskydning.

### 7.2 Forbindelser

| AD3 Pin | Målepunkt | Signal |
|---|---|---|
| 1+ | V_Meas1 pin 1 | Meas_V_Out (venstre) |
| 2+ | Meas_H1 pin 1 | Meas_H_Out (højre) |
| GND | GND | Stel |

### 7.3 WaveForms Scope Indstillinger

| Parameter | Værdi |
|---|---|
| Kanal 1 | Aktiveret, DC kobling, 10:1 probe |
| Kanal 2 | Aktiveret, DC kobling, 10:1 probe |
| Område | -2V til +12V |
| Tid/Div | 100 µs |
| Trigger | Ch1, Stigende, 4.5V |

### 7.4 Forventet Resultat

| Måling | Forventet | Tolerance |
|---|---|---|
| Output swing | 0V til 9V | ±0.5V |
| Frekvens | 2.000 kHz | ±1% |
| Faseforskydning | 180° | ±5° |
| Rise time | <100 ns | - |
| Fall time | <100 ns | - |

### 7.5 Faseforskydning Verifikation

```text
Meas_V_Out  ────┐           ┌─────────────┐
(Venstre)       │           │             │
                └───────────┘             └───

Meas_H_Out  ───────────┐           ┌──────────
(Højre)                │           │
                ───────┘           └──────────
                       │◄─────────►│
                         180° fase
                        (250µs ved 2kHz)
```

### 7.6 Måleresultater

![[../Images/output_yellow-Vout_Blue-Hout.png]]

**Observation:**
- **Gul (CH1):** Meas_V_Out (venstre half-bridge) - svinger fra 0V til ~10V.
- **Blå (CH2):** Meas_H_Out (højre half-bridge) - svinger fra 0V til ~10V.
- **180° faseforskydning:** Når gul er høj, er blå lav og omvendt - præcis som forventet.
- Rene firkantbølger med minimal ringing på flankerne.
- Frekvens ~2kHz verificeret via tidsbasen.

### 7.7 Fejlfinding

| Problem | Mulig Årsag | Løsning |
|---|---|---|
| Output når ikke 9V | MOSFET ikke fuldt tændt | Tjek gate drive |
| Output når ikke 0V | MOSFET ikke fuldt slukket | Tjek deadtime |
| Forkert fase | Signaler forbyttet | Tjek PWM routing |
| Ringing på flanker | Parasitisk induktans | Tilføj snubber |

---

## 8. Test 4 - Differentielt Output

### 8.1 Formål

Mål den fulde H-bro udgangsspænding der driver LC tanken.

### 8.2 Forbindelser

Samme som Test 3:

| AD3 Pin | Målepunkt | Signal |
|---|---|---|
| 1+ | V_Meas1 pin 1 | Meas_V_Out |
| 2+ | Meas_H1 pin 1 | Meas_H_Out |
| GND | GND | Stel |

### 8.3 WaveForms Scope Indstillinger

| Parameter | Værdi |
|---|---|
| Kanal 1 | Aktiveret |
| Kanal 2 | Aktiveret |
| **Math** | CH1 - CH2 |
| Område | -12V til +12V |
| Tid/Div | 200 µs |
| Trigger | Math, Stigende, 0V |

### 8.4 Aktivering af Math i WaveForms

1. Åbn **Scope** instrumentet
2. Klik på **Math** fanen
3. Vælg **Custom** og indtast: `C1 - C2`
4. Aktivér Math kanalen

### 8.5 Forventet Resultat

| Måling | Forventet | Tolerance |
|---|---|---|
| Positiv amplitude | +9V | ±0.5V |
| Negativ amplitude | -9V | ±0.5V |
| Peak-to-peak | 18V | ±1V |
| Frekvens | 2.000 kHz | ±1% |
| Bølgeform | Firkant | - |

### 8.6 Differentielt Output Waveform

```text
         +9V  ─ ─ ─ ┬─────────────┬ ─ ─ ─ ─ ─ ┬───────────
                    │             │           │
          0V  ─ ─ ─ ┼ ─ ─ ─ ─ ─ ─ ┼ ─ ─ ─ ─ ─ ┼ ─ ─ ─ ─ ─
                    │             │           │
         -9V  ─────┬┘             └───────────┘

                   │◄────────────►│
                      250µs (½T)
```

### 8.7 Måleresultater

![[../Images/Differential_output.png]]

**Observation:**
- **Math (C1-C2):** Differentielt output viser ±9V firkantbølge.
- **Positiv peak:** +9V ✓
- **Negativ peak:** -9V ✓
- **Peak-to-peak:** ~18V ✓
- Ren firkantbølge centreret omkring 0V.
- Dette er spændingen der driver LC tanken og bekræfter at begge half-bridges arbejder korrekt med 180° faseforskydning.

### 8.8 Fejlfinding

| Problem | Mulig Årsag | Løsning |
|---|---|---|
| Asymmetrisk amplitude | Ubalanceret forsyning | Tjek 9V på begge sider |
| Kun ±4.5V | En side switcher ikke | Tjek begge half-bridges |
| DC offset | Duty cycle mismatch | Verificer 50% duty |

---

## 9. Test 5 - LC Tank Strøm

### 9.1 Formål

Verificer sinusformet strøm gennem TX spolen. Denne test er valgfri og kræver strømprobe eller shunt modstand.

### 9.2 Metode A: Strømprobe

| AD3 Pin | Forbindelse | Signal |
|---|---|---|
| 1+ | Strømprobe output | Spolestrøm |
| GND | GND | Stel |

### 9.3 Metode B: Shunt Modstand

Indsæt en lille shunt modstand (f.eks. 0.1Ω) i serie med LC tanken.

| AD3 Pin | Forbindelse | Signal |
|---|---|---|
| 1+ | Over shunt (høj side) | Spændingsfald |
| 1- | Over shunt (lav side) | Reference |

**Strøm beregning:** $I = V_{shunt} / R_{shunt}$

### 9.4 WaveForms Scope Indstillinger

| Parameter | Værdi |
|---|---|
| Kanal 1 | Aktiveret, AC kobling |
| Område | Afhængig af probe/shunt |
| Tid/Div | 200 µs |
| Trigger | Ch1, Stigende |

### 9.5 Forventet Resultat

| Måling | Forventet | Noter |
|---|---|---|
| Bølgeform | Sinusformet | Fra LC resonans |
| Frekvens | 2.000 kHz | Matches TX frekvens |
| Amplitude | Afhænger af Q | Typisk flere hundrede mA |

### 9.6 LC Resonans Verifikation

```text
Spænding (firkant):     Strøm (sinus):
    ┌───┐                    ╱╲
    │   │                  ╱    ╲
────┘   └────           ──╱──────╲──
                           ╲    ╱
                            ╲╱
```

> [!info] Resonans Princip
> LC tankens høje Q-faktor filtrerer firkantbølgen til en sinusbølge. Kun grundtonen ved 2kHz passerer effektivt.

### 9.7 Måleresultater

![[../Images/LC_Tank_current.png]]

**Observation:**
- **Sinusformet bølgeform:** LC tanken filtrerer firkantbølgen til en sinusstrøm ✓
- **Amplitude:** ~±25mV over 0.1Ω shunt → ~250mA peak strøm
- **Switching spikes:** De skarpe transienter ved hver periode er normale og skyldes H-bro switching. De påvirker ikke metaldetektorens funktion da DFT kun ser på 2kHz grundtonen.
- **Frekvens:** 2kHz matcher TX frekvensen ✓

**Strømberegning:**
$$I_{peak} = \frac{V_{shunt}}{R_{shunt}} = \frac{25\text{mV}}{0.1\Omega} \approx 250\text{mA}$$

> [!success] Test Godkendt
> Den sinusformede strøm bekræfter at LC tanken resonerer korrekt ved 2kHz og at H-bro forstærkeren driver TX spolen som forventet.

---

## 10. Test 6 - RX Spole Respons

### 10.1 Formål

Verificer at RX spolen detekterer metal ved at måle amplitudeændringen når metal bringes tæt på spolerne. Dette demonstrerer metaldetektorens grundlæggende funktionsprincip.

### 10.2 Forbindelser

| AD3 Pin | Forbindelse | Signal |
|---|---|---|
| 1+ (orange) | RX spole signal (før forstærker) | Induceret spænding |
| 1- (orange/hvid) | RX spole GND | Reference |
| GND | Circuit GND | Stel |

### 10.3 WaveForms Scope Indstillinger

| Parameter | Værdi |
|---|---|
| Kanal 1 | Aktiveret, AC kobling |
| Område | 50-100 mV/div |
| Tid/Div | 200 µs |
| Trigger | Ch1, Auto |

### 10.4 Testprocedure

1. **Baseline måling:** Tag screenshot uden metal i nærheden af spolerne
2. **Metal måling:** Hold stål (eller andet metal) tæt på TX/RX spolerne og tag screenshot
3. Sammenlign amplituden mellem de to målinger

### 10.5 Forventet Resultat

| Måling | Uden Metal | Med Metal |
|---|---|---|
| Bølgeform | Minimal/flad | Sinusformet 2kHz |
| Amplitude | ~0 mV | Øget (afhænger af metaltype) |
| Fase | - | Ændret relativt til TX |

### 10.6 Måleresultater

#### Uden Metal (Baseline)

![[../Images/Rx_before_rxamp_noMetal.png]]

**Observation:**
- Signalet er næsten fladt med minimal amplitude (~0 mV).
- RX spolen er balanceret/nullet i forhold til TX feltet.
- Dette er baseline-tilstanden hvor ingen metal forstyrrer det elektromagnetiske felt.

#### Med Stål

![[../Images/Rx_before_rxamp_Metal.png]]

**Observation:**
- Signifikant amplitudeforøgelse til ~±50-100 mV.
- Tydelig 2kHz bølgeform induceret fra TX spolen.
- Stål (ferromagnetisk metal) forstyrrer det elektromagnetiske felt og ændrer koblingen mellem TX og RX spolerne.
- De skarpe transienter skyldes H-bro switching.

### 10.7 Metaldetektionsprincip

```text
UDEN METAL:                      MED METAL:

TX ~~~→ [  ] ~~~→ RX            TX ~~~→ [METAL] ~~~→ RX
        Luft                            │
        Minimal kobling                 Forstyrret felt
        Signal ≈ 0                      Signal ↑↑↑
```

> [!info] Hvorfor Ændres Signalet?
> Ferromagnetiske metaller (stål, jern) koncentrerer det magnetiske felt og øger koblingen mellem TX og RX. Ikke-ferromagnetiske metaller (kobber, aluminium) inducerer hvirvelstrømme der skaber et modsatrettet felt. Begge effekter ændrer RX signalet.

> [!success] Test Godkendt
> RX spolen reagerer tydeligt på metal. Amplitudeforøgelsen demonstrerer at metaldetektoren kan detektere stål korrekt.

---

## 11. Fejlfinding

### 10.1 Generelle Problemer

| Problem | Mulig Årsag | Løsning |
|---|---|---|
| Ingen PWM output | MCU kører ikke | Verificer firmware og PWM pin |
| Deadtime for lang | RC værdier forkerte | Tjek komponentværdier |
| Gate drive svag | Bootstrap ikke opladet | Sikr low-side aktivitet |
| Output oscillerer | Parasitisk induktans | Tilføj gate modstand/snubber |

### 10.2 Termiske Problemer

| Observation | Mulig Årsag | Løsning |
|---|---|---|
| MOSFET varm | Shoot-through | Øg deadtime |
| MOSFET varm | Høj Rds(on) | Tjek gate drive niveau |
| Driver varm | Overdreven kapacitiv load | Reducer gate frekvens |

### 10.3 AD3 Specifikke Problemer

| Problem | Løsning |
|---|---|
| Probe loading | Brug 10:1 probe til høj-impedans punkter |
| Ground bounce | Brug kort GND forbindelse tæt på målepunkt |
| Aliasing | Øg sample rate til minimum 10× signalfrekvens |

---

## 12. Relaterede Dokumenter

- [[Testing Guide|Generel Testguide]] - AD3 opsætning og firmware test
- [[Assembly_Guide|Samlevejledning]] - Hardware opsætning
- [[Code_Review|Firmware Gennemgang]] - PWM generering
- [[../Theory/H-Bridge Theory|H-Bro Teori]] - Kredsløbsprincipper

---

*H-Bridge Måleguide til DTU 34621 Metaldetektor Projekt*

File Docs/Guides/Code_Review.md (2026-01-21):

# Metaldetektor Firmware Kodegennemgang

> [!abstract] Dokumentformål
> Dette dokument giver en teknisk gennemgang af VLF metaldetektor firmwaren.
> **Nuværende Status:** Fuldt funktionel og modulær version med metaldetektion, klassificering, kalibrering, grafisk HUD, buzzer feedback og startup jingle.
>
> **Mål:** ATmega328P (Arduino Nano)
> **Kursus:** DTU 34621 - Indlejrede Systemer

---

## Indholdsfortegnelse

1. [[#1. Systemoversigt]]
2. [[#2. Kodestruktur]]
3. [[#3. Hardware Konfiguration]]
4. [[#4. Signalbehandling]]
5. [[#5. Metal Klassificering]]
6. [[#6. Buzzer og Jingle]]
7. [[#7. Kompilering og Upload]]
8. [[#8. Brugergrænseflade]]
9. [[#9. Fejlfinding]]

---

## 1. Systemoversigt

### 1.1 Nuværende Arkitektur

Firmwaren er en fuldt funktionel og modulær metaldetektor med følgende funktioner:
- TX signalgenerering (2 kHz firkantbølge)
- RX signal sampling og DFT analyse
- IIR filtrering for stabil visning
- Metal klassificering (ferro/non-ferro baseret på fase)
- Kalibrering med baseline lagring
- Start/Stop kontrol
- Grafisk HUD med ikoner og progress bar
- Buzzer feedback ved metal detektion
- Startup jingle ved opstart
- Splash screen ved boot

```
Code/src/
├── main.c              # Hovedprogram, initialisering, hovedløkke
├── adc.c               # ADC sampling og auto-trigger
├── button.c            # Knaphåndtering med debounce
├── buzzer.c            # Buzzer feedback (beeps ved detektion)
├── detection.c         # Metal klassificering (ferro/non-ferro)
├── dft.c               # DFT beregning og akkumulering
├── display.c           # OLED display med grafisk HUD og ikoner
├── filter.c            # IIR filter til udglatning
├── jingle.c            # Startup-melodi
├── timer.c             # Timer0/Timer1 konfiguration
│
├── include/            # Header filer
│   ├── config.h        # Globale konstanter og konfiguration
│   ├── adc.h, button.h, buzzer.h
│   ├── detection.h, dft.h, display.h, filter.h
│   └── jingle.h, timer.h
│
└── drivers/            # Hardware drivere
    ├── I2C.c, I2C.h    # TWI master driver
    ├── ssd1306.c, .h   # OLED display driver
    └── data.h          # Font og ikon data (PROGMEM)
```

### 1.2 Signalflow

```mermaid
flowchart TB
    T0[Timer0<br>8kHz] --> TX[TX Spole<br>Pin 9<br>2kHz]
    TX -.->|Felt| M((Metal))
    M -.->|Hvirvel| RX[RX Spole]
    RX --> ADC[ADC<br>Pin A0]
    ADC --> DFT[DFT<br>64 samples]
    DFT --> IIR[IIR Filter]
    IIR --> CLASS[Klassificering]
    CLASS --> OLED[Display]
```

**Signalkæde:** Timer0 (8kHz) → TX Toggle (2kHz) → Metal → RX Spole → ADC → DFT → IIR Filter → Klassificering → Display

### 1.3 Nøglespecifikationer

| Parameter | Værdi | Noter |
|---|---|---|
| TX Frekvens | 2 kHz | VLF område |
| Samplerate | 8 kHz | 4 samples per TX cyklus |
| ADC Trigger | Auto (ADATE) | Timer0 Compare Match A |
| DFT Vindue | 64 samples | 8 ms data |
| TX Cykler per Vindue | 16 | 64 / 4 = 16 |
| IIR Alpha | 0.15 | Udglætningsfaktor |
| I2C Clock | ~400 kHz | Fast mode |
| ADC Opløsning | 10 bits | 0-1023 område |
| ADC Prescaler | 64 | 250 kHz ADC clock |

### 1.4 Pin Konfiguration

| Pin | AVR Port | Funktion | Noter |
|-----|---|---|---|
| 9 | PB1 | TX signal | 2 kHz firkantbølge |
| 11 | PB3 | Buzzer output | PWM tone via Timer1 |
| A0 | PC0/ADC0 | RX signal indgang | 10-bit ADC |
| A4 | PC4 | I2C SDA | OLED display |
| A5 | PC5 | I2C SCL | OLED display |
| D2 | PD2 | Start/Stop knap | Toggle detektor on/off |
| D3 | PD3 | Kalibrering knap | Gem baseline |

---

## 2. Kodestruktur

### 2.1 Modulær Arkitektur

Firmwaren er opdelt i 10 separate moduler med tilhørende header-filer i `include/` mappen:

| Modul | Ansvar |
|---|---|
| `main.c` | Hovedløkke, initialisering, tilstandshåndtering |
| `timer.c` | Timer0 (8kHz interrupt, TX toggle) og Timer1 (buzzer PWM) |
| `adc.c` | ADC auto-trigger setup og initialisering |
| `dft.c` | Single-bin DFT akkumulering og beregning |
| `filter.c` | IIR lavpas filter for udglatning |
| `detection.c` | Kalibrering og metal klassificering |
| `display.c` | Grafisk HUD, ikoner, progress bar, splash screen |
| `button.c` | Debounced knaphåndtering |
| `buzzer.c` | Tone-generering via Timer1 PWM |
| `jingle.c` | Startup-melodi sekvens |

#### Konfiguration (include/config.h)

```c
#define F_SAMPLE 8000         // Sample frekvens (Hz)
#define F_SIGNAL 2000         // TX/RX signal frekvens (Hz)
#define N 64                  // Samples per DFT vindue
#define ADC_OFFSET 512        // DC offset

/* Metal Klassificering */
#define FERRO_THRESHOLD -10   // Fase tærskel (grader)
#define DETECT_THRESHOLD 5    // Min. magnitude ændring

/* IIR Filter */
#define IIR_ALPHA 0.15f       // Udglatningsfaktor
```

> [!WARNING] Signed Typer Påkrævet
> `Re` og `Im` SKAL være `int32_t` (signed), ikke `uint32_t`.
> DFT'en subtraherer værdier, så negative resultater er forventede.

#### Timer0 Initialisering

```c
void timer0_init(void) {
    DDRB |= (1 << PB1);           /* Pin 9 udgang */
    TCCR0A = (1 << WGM01);        /* CTC mode */
    TCCR0B = (1 << CS01);         /* Prescaler 8 */
    OCR0A = 249;                  /* 8 kHz interrupt */
    TIMSK0 = (1 << OCIE0A);
}
```

**Frekvensberegning:**
- f_interrupt = 16 MHz / (8 × 250) = 8 kHz
- TX toggles hver 2. interrupt = 4 kHz toggle rate = 2 kHz firkantbølge

#### ADC Initialisering

```c
void adc_init(void) {
    ADMUX = (1 << REFS0);         /* AVCC reference */
    ADCSRA = (1 << ADEN) | (1 << ADIE) | (1 << ADATE)
           | (1 << ADPS2) | (1 << ADPS1);  /* Prescaler 64 */
    ADCSRB = (1 << ADTS1) | (1 << ADTS0);  /* Timer0 trigger */
    ADCSRA |= (1 << ADSC);        /* Start */
}
```

> [!TIP] Auto-Trigger Mode
> Ved brug af `ADATE` med `ADTS1:0 = 011` starter ADC automatisk en ny
> konvertering ved hver Timer0 Compare Match A event. Ingen manuel triggering nødvendig.

#### Button Initialisering

```c
void button_init(void) {
    DDRD &= ~(1 << PD2);          /* D2 Start/Stop - input */
    PORTD |= (1 << PD2);          /* Pull-up aktiveret */
    DDRD &= ~(1 << PD3);          /* D3 Calibrate - input */
    PORTD |= (1 << PD3);          /* Pull-up aktiveret */
}
```

Begge knapper bruger interne pull-up modstande. Knapperne er active-low (forbundet til GND ved tryk).

#### Timer0 ISR (TX Generering)

```c
ISR(TIMER0_COMPA_vect) {
    if (!detector_running) {
        PORTB &= ~(1 << PB1);     /* TX lav når stoppet */
        tx_count = 0;
        return;
    }

    if (++tx_count >= 2) {
        PORTB ^= (1 << PB1);      /* Toggle TX */
        tx_count = 0;
        if (PORTB & (1 << PB1)) {
            sync_flag = 1;        /* Synkroniser DFT med TX rising edge */
        }
    }
}
```

ISR'en tjekker først om detektoren kører. Hvis ikke, holdes TX lav for at spare strøm og undgå støj.

#### ADC ISR (DFT Akkumulering)

```c
ISR(ADC_vect) {
    adc_raw = ADC;
    if (sync_flag && detector_running) {
        dft_sum(adc_raw);
    }
}
```

#### DFT Akkumulering

```c
void dft_sum(int16_t raw) {
    int16_t x = raw - ADC_OFFSET;

    switch (dft_index & 3) {
        case 0: Re += x;  break;
        case 1: Im -= x;  break;
        case 2: Re -= x;  break;
        case 3: Im += x;  break;
    }

    if (++dft_index >= N) {
        Re_buf = Re;
        Im_buf = Im;
        Re = Im = 0;
        dft_index = 0;
        dft_done = 1;
        sync_flag = 0;
    }
}
```

Optimeret single-bin DFT der udnytter at cos/sin koefficienter ved 4× oversampling kun er +1, -1 eller 0.

#### DFT Beregning

```c
void dft_calc(void) {
    double re = Re_buf, im = Im_buf;
    mag = sqrt(re*re + im*im) / N;
    phase = atan2(im, re) * 57.2957795;
}
```

> [!NOTE] Floating-Point Matematik
> Bruger standard bibliotek `sqrt()` og `atan2()` fra `<math.h>` for nøjagtig beregning.
> Kan optimeres med integer approksimationer senere hvis nødvendigt.

---

## 3. Hardware Konfiguration

### 3.1 Timer0 - TX Generering & ADC Auto-Trigger

Timer0 tjener dobbelt formål:
1. Generer 8 kHz Compare Match A event til ADC auto-triggering
2. ISR toggler TX pin hver 2. interrupt for 2 kHz signal

```mermaid
flowchart TD
    CLK[16 MHz Clock] --> PRE[Prescaler /8<br>2 MHz]
    PRE --> CNT[TCNT0 Tæller<br>0 → 249 → 0]
    CNT --> CMP{TCNT0 == OCR0A?}
    CMP -->|Ja| EVENT[Compare Match A Event]
    CMP -->|Nej| CNT

    EVENT --> ISR[TIMER0_COMPA ISR<br>Toggle TX hver 2.]
    EVENT --> ADC[ADC Auto-Trigger<br>via ADATE]

    ADC --> CONV[ADC Konvertering]
    CONV --> ADC_ISR[ADC_vect ISR<br>DFT akkumulering]
```

### 3.2 ADC Timing

| Parameter | Værdi | Beregning |
|---|---|---|
| ADC clock | 250 kHz | 16 MHz / 64 |
| Konverteringstid | 52 µs | 13 cykler / 250 kHz |
| Sample interval | 125 µs | 8 kHz rate |
| Margin | 73 µs | 125 - 52 |

### 3.3 Timingdiagram

```
Tid (µs):      0    125   250   375   500
               │     │     │     │     │
Timer0 ISR:   [0]   [1]   [2]   [3]   [4]  (8 kHz)
TX Toggle:    Ja    Nej   Ja    Nej   Ja
TX Output:    ─────HIGH─────┐     ┌─────HIGH─────
                            └LOW─┘
ADC Sample:   S0    S1    S2    S3         (4 samples per TX cyklus)
DFT coeff:   Re+   Im-   Re-   Im+

             ◄───── 500µs (én TX cyklus, 2 kHz) ─────►
```

### 3.4 DFT Koefficient Mapping

```mermaid
flowchart LR
    subgraph "TX Cyklus 500µs"
        S0[Sample 0<br>0°] --> S1[Sample 1<br>90°]
        S1 --> S2[Sample 2<br>180°]
        S2 --> S3[Sample 3<br>270°]
    end
    
    S0 -.-> R0[Re += x]
    S1 -.-> I1[Im -= x]
    S2 -.-> R2[Re -= x]
    S3 -.-> I3[Im += x]
```

---

## 4. Signalbehandling

> [!info] DFT Algoritme Dokumentation
> Se [[../Theory/DFT Algorithm|DFT Algoritme]] for fuld matematisk baggrund.

Firmwaren bruger en optimeret single-bin DFT der udnytter 4× oversampling:
- Sampler ved 8 kHz, signal ved 2 kHz
- Cos/sin koefficienter reduceres til +1, -1, 0
- Ingen trigonometriske beregninger i ISR

### 4.1 IIR Filter

Et single-pole IIR lavpasfilter udglatter magnitude og fase for stabil visning:

```c
#define IIR_ALPHA 0.15f

void filter_update(void) {
    mag_filtered = IIR_ALPHA * mag + (1.0f - IIR_ALPHA) * mag_filtered;
    phase_filtered = IIR_ALPHA * phase + (1.0f - IIR_ALPHA) * phase_filtered;
}
```

**Karakteristik:**
- Alpha = 0.15 giver god udglætning med rimelig responstid
- Højere alpha = hurtigere respons, mere støj
- Lavere alpha = langsommere respons, mere udglætning

**Matematisk formel:**
```
y[n] = α × x[n] + (1 - α) × y[n-1]
```

### 4.2 IIR Filter Blokdiagram

```mermaid
flowchart LR
    X[x_n<br>Input] --> MUL1[× α]
    MUL1 --> ADD((+))
    ADD --> Y[y_n<br>Output]
    Y --> Z["z⁻¹<br>Delay"]
    Z --> MUL2[× 1-α]
    MUL2 --> ADD
```

---

## 5. Metal Klassificering

### 5.1 Princip

Metal klassificeres baseret på faseændring fra kalibreret baseline:
- **Ferromagnetiske metaller** (jern, stål): Negativ faseændring (fase skifter mod negative værdier)
- **Ikke-ferromagnetiske metaller** (kobber, aluminium, messing): Positiv/neutral faseændring

Dette skyldes at ferromagnetiske materialer har høj permeabilitet som forstærker det magnetiske felt, mens ikke-ferromagnetiske materialer primært skaber hvirvelstrøms-tab.

### 5.2 Klassificeringsflowchart

```mermaid
flowchart TD
    START[Ny DFT Måling] --> CAL{Kalibreret?}
    CAL -->|Nej| NONE1[METAL_NONE]
    CAL -->|Ja| DELTA[Beregn Δmag]
    DELTA --> THRESH{Δmag >= 5?}
    THRESH -->|Nej| NONE2[METAL_NONE<br>Ingen detektion]
    THRESH -->|Ja| PHASE[Beregn Δphase]
    PHASE --> FERRO{Δphase < -10°?}
    FERRO -->|Ja| FE[METAL_FERRO<br>Jern/Stål]
    FERRO -->|Nej| NONFE[METAL_NONFERRO<br>Kobber/Alu]
```

### 5.3 Detektionstærskel

Før klassificering tjekkes om magnitude-ændringen overstiger en tærskel:

```c
#define DETECT_THRESHOLD 5      /* Min. magnitude ændring for detektion */
```

Dette forhindrer falske detektioner fra støj når intet metal er tilstede.

### 5.4 Klassificeringsalgoritme

```c
void classify_metal(void) {
    if (!is_calibrated) {
        metal_type = METAL_NONE;
        metal_detected = 0;
        return;
    }

    /* Beregn magnitude ændring (absolut værdi) */
    int16_t delta_mag = (int16_t)mag_filtered - (int16_t)baseline_mag;
    if (delta_mag < 0) delta_mag = -delta_mag;

    /* Check om magnitude ændring overstiger tærskel */
    if (delta_mag < DETECT_THRESHOLD) {
        metal_detected = 0;
        metal_type = METAL_NONE;
        return;
    }

    /* Metal detekteret - klassificer baseret på fase */
    metal_detected = 1;
    int16_t delta_phase = (int16_t)phase_filtered - baseline_phase;
    if (delta_phase < FERRO_THRESHOLD) {
        metal_type = METAL_FERRO;
    } else {
        metal_type = METAL_NONFERRO;
    }
}
```

### 5.5 Kalibrering

Tryk på D3 knappen for at gemme nuværende filtrerede værdier som baseline:

```c
void calibrate(void) {
    baseline_mag = (uint16_t)mag_filtered;
    baseline_phase = (int16_t)phase_filtered;
    is_calibrated = 1;
    eeprom_save_calibration();
}
```

Kalibrering bør udføres med detektoren i luften, væk fra metal.

### 5.6 Tærskelværdier

| Parameter | Værdi | Beskrivelse |
|---|---|---|
| FERRO_THRESHOLD | -10 | Fase delta < -10 grader = ferromagnetisk |
| DETECT_THRESHOLD | 5 | Min. magnitude delta for at registrere metal |

---

## 6. Buzzer og Jingle

### 6.1 Buzzer Feedback

Buzzeren giver audio feedback ved metal detektion og bruges til startup jingle.

**Hardware:**
- Pin 11 (PB3/OC2A) - PWM output
- Passiv buzzer (piezo eller magnetisk)

**Funktioner (buzzer.c):**

```c
void buzzer_init(void);        // Initialiser Timer1 for PWM
void buzzer_beep(uint16_t freq, uint16_t duration_ms);  // Afspil tone
void buzzer_off(void);         // Stop buzzer
```

### 6.2 Startup Jingle

Ved opstart afspilles en kort melodi via `jingle.c`:

```c
void jingle_play(void);        // Afspil startup-melodi
```

Jinglen består af en sekvens af toner der afspilles efter splash screen.

### 6.3 Metal Detektion Feedback

Når metal detekteres, bipper buzzeren for at give audio feedback:
- **Ferro metal (Fe/Stål):** Lavere tone
- **Non-ferro metal (Cu/Al):** Højere tone

Feedback hjælper brugeren med at identificere metal uden at kigge på displayet.

---

## 7. Kompilering og Upload

### 7.1 PlatformIO Konfiguration

```ini
[env:nano]
platform = atmelavr
board = nanoatmega328
framework = arduino

board_build.f_cpu = 16000000L

build_flags =
    -std=c99
    -Wall
    -Os
```

### 7.2 Build Kommandoer

```bash
# Kompiler
pio run

# Upload til Arduino Nano
pio run -t upload

# Monitor seriel output
pio device monitor
```

### 7.3 Hukommelsesforbrug

| Hukommelse | Brugt | Tilgængelig | Procent |
|---|---|---|---|
| RAM | 518 bytes | 2048 bytes | 25.3% |
| Flash | 7324 bytes | 30720 bytes | 23.8% |

---

## 8. Brugergrænseflade

### 8.1 Knapper

| Knap | Pin | Funktion | Noter |
|---|-----|---|---|
| D2 | PD2 | Start/Stop | Toggle detektor on/off |
| D3 | PD3 | Kalibrering | Gem baseline (kun når kørende) |

Begge knapper har 50ms debounce delay og bruger falling-edge detection.

### 8.2 Tilstandsdiagram

```mermaid
stateDiagram-v2
    [*] --> Stoppet: Boot
    Stoppet --> Kørende: D2 Tryk
    Kørende --> Stoppet: D2 Tryk

    state Kørende {
        [*] --> HUD_Skærm
        HUD_Skærm --> Kalibrering: D3 Tryk
        Kalibrering --> HUD_Skærm: Auto
    }
```

### 8.3 Knaphåndtering i Main Loop

```c
/* Start/Stop knap (D2) */
uint8_t btn2 = (PIND >> PD2) & 1;
if (btn2_prev && !btn2) {           /* Falling edge */
    _delay_ms(50);                   /* Debounce */
    if (detector_running) {
        detector_stop();
        display_stopped();
    } else {
        detector_start();
    }
}
btn2_prev = btn2;

/* Kalibrering knap (D3) */
uint8_t btn3 = (PIND >> PD3) & 1;
if (btn3_prev && !btn3 && detector_running) {
    _delay_ms(50);
    calibrate();
    /* Vis bekræftelse */
}
btn3_prev = btn3;
```

### 8.4 Display Skærme

Displayet bruger en grafisk HUD med ikoner og progress bar.

**Splash Screen (ved opstart):**
- Vises i ~2 sekunder ved boot
- Projekt logo/navn
- Efterfulgt af startup jingle

**Hovedskærm (Grafisk HUD):**
- Ikon for metal type (ferro/non-ferro/ingen)
- Progress bar for signal styrke
- Numeriske værdier for magnitude og fase
- Kalibreringsindikator

**Skærmelementer:**
```
┌─────────────────────────┐
│  [IKON]  METAL TYPE     │
│                         │
│  MAG: ████████░░  120   │
│  PHA: -45°              │
│                         │
│  [CAL]  Status tekst    │
└─────────────────────────┘
```

**Metal Type Ikoner:**
- Intet metal: Tom cirkel eller "---"
- Ferro (Fe/Stål): Magnet-ikon
- Non-ferro (Cu/Al): Ring-ikon

**Stoppet Skærm:**
- Viser "PAUSE" med instruktion
- Tryk D2 for at starte

---

## 9. Fejlfinding

### Intet TX Signal på Pin 9

1. Tjek at detektoren er startet (tryk D2)
2. Verificer at `DDRB |= (1 << PB1)` er udført i `timer0_init()`
3. Tjek at `sei()` kaldes i `main()` (aktiverer interrupts)
4. Mål med oscilloskop (bør være 2kHz firkantbølge)

### ADC Sampler Ikke

1. Verificer at `sei()` kaldes (aktiverer interrupts)
2. Tjek at detektoren kører (`detector_running = 1`)
3. Verificer at ADCSRA har ADEN, ADIE og ADATE bits sat
4. Verificer at ADCSRB har ADTS1:0 = 011 (Timer0 Compare Match A trigger)

### Display Virker Ikke

1. Tjek I2C forbindelser (A4=SDA, A5=SCL)
2. Verificer at `I2C_Init()` kaldes før `InitializeDisplay()`
3. Prøv anden I2C adresse (nogle moduler bruger 0x7A i stedet for 0x78)

### Kalibrering Indlæses Ikke Ved Opstart

1. Verificer at EEPROM ikke er blevet slettet
2. Tjek at magic value er korrekt (0xCAFE på adresse 0-1)
3. Kalibrer igen med D3 knappen for at gemme ny kalibrering

### Metal Detekteres Ikke

1. Sørg for at detektoren er kalibreret (display viser ikke "Tryk D3 for CAL")
2. Tjek at DETECT_THRESHOLD (5) ikke er for høj til dit setup
3. Verificer at RX spole er korrekt forbundet til A0
4. Tjek at TX spole sender signal (oscilloskop på pin 9)

### Forkert Metal Klassificering

1. Kalibrer igen i et område uden metal
2. Tjek at FERRO_THRESHOLD (-10) er passende
3. Verificer at fasen er stabil

---

## 10. Fremtidige Forbedringer

Følgende funktioner kan tilføjes senere:

- [x] ~~Buzzer output med Timer1 PWM for audio feedback~~ ✅ Implementeret
- [x] ~~Grafisk HUD med ikoner~~ ✅ Implementeret
- [x] ~~Startup jingle~~ ✅ Implementeret
- [ ] EEPROM persistens af kalibrering
- [ ] Justerbare tærskelværdier via menu system
- [ ] Batteriniveau visning
- [ ] Automatisk gain kontrol
- [ ] Flere frekvenser for bedre diskriminering

---

## Dokumentrevisionshistorik

| Version | Dato | Ændringer |
|---|---|---|
| 1.0 | 2025-01 | Første omfattende gennemgang (ATmega2560) |
| 2.0 | 2025-01 | Migreret til Arduino Nano (ATmega328P) |
| 2.1 | 2025-01 | Opdateret til at afspejle ADC auto-trigger mode (ADATE) |
| 2.2 | 2025-01 | Ændret til floating-point sqrt()/atan2() |
| 3.0 | 2025-01 | Forenklet til minimal testversion (enkelt main.c) |
| 4.0 | 2025-01 | Fuldt funktionel version med metal klassificering, IIR filter, Start/Stop kontrol |
| 5.0 | 2026-01 | Modularisering: 11 moduler + include/ mappe. Tilføjet buzzer, jingle, grafisk HUD med ikoner og splash screen |
| 5.1 | 2026-01 | Fjernet MATLAB capture interface og debug display mode. Nu 10 moduler. |

---

*Dokument genereret til DTU 34621 Metaldetektor Projekt*
*Hold: Mads Rudolph, Andreas Skaaning, Jonas Beck & Sigurd Hestbech*

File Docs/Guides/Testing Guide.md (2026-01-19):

# Testguide - VLF Metaldetektor

> [!abstract] Dokumentformål
> Samlet testguide for verifikation af metaldetektor firmware og hardware.
> Indeholder tre testmetoder: Analog Discovery 3, RC Loopback, og MATLAB DFT verifikation.

---

## Indholdsfortegnelse

1. [[#1. Oversigt]]
2. [[#2. Test med Analog Discovery 3]]
3. [[#3. RC Loopback Test]]
4. [[#4. DFT Verifikation med MATLAB]]
5. [[#5. Fejlfinding]]

---

## 1. Oversigt

### 1.1 Testmetoder

| Test | Formål | Udstyr Krav |
|---|---|---|
| **AD3 Test** | Verificer TX/RX signaler med eksternt udstyr | Analog Discovery 3 |
| **RC Loopback** | Verificer fasemåling med passive komponenter | 1kΩ modstand, 100nF kondensator |
| **MATLAB DFT** | Verificer DFT algoritme mod FFT | MATLAB, USB kabel |

### 1.2 Anbefalet Testrækkefølge

```text
RC Loopback ──▶ AD3 Test ──▶ MATLAB DFT ──▶ Hardware Integration
```

1. **RC Loopback først** - kræver kun passive komponenter
2. **AD3 Test** - mere detaljeret signalanalyse
3. **MATLAB DFT** - matematisk verifikation

---

## 2. Test med Analog Discovery 3

### 2.1 Formål

Test metaldetektorens firmware uden spoler ved at bruge AD3 til at:
- **Måle** TX-udgangssignalet på Pin D9
- **Generere** et testsignal ind på Pin A0 (simulerer RX-spole)
- **Verificere** at DFT-behandlingen fungerer korrekt

### 2.2 Udstyr

| Udstyr | Noter |
|---|---|
| Arduino Nano | Programmeret med firmware |
| Analog Discovery 3 | Med WaveForms software |
| Breadboard | Med Nano og OLED forbundet |
| Jumperwires | Til AD3 forbindelser |

### 2.3 AD3 Pin Reference

```text
Analog Discovery 3 Connector:
┌─────────────────────────────────────┐
│  1+  1-  2+  2-  W1  W2  T1  T2 ... │
│  ●   ●   ●   ●   ●   ●   ●   ●      │
│  Scope Ch1  Scope Ch2  Wavegen      │
└─────────────────────────────────────┘

1+/1- = Oscilloskop Kanal 1
W1    = Bølgegenerator 1 udgang
GND   = Stel
```

### 2.4 Forbindelser

| AD3 Pin | Arduino Pin | Formål |
|---|---|---|
| **1+** (orange) | D9 | Mål TX-udgang |
| **1-** (orange/hvid) | GND | Scope reference |
| **W1** (gul) | A0 | Injicer testsignal |
| **GND** (sort) | GND | Fælles stel |

```text
    ANALOG DISCOVERY 3                    ARDUINO NANO
    ┌──────────────────┐                  ┌──────────────┐
    │  1+ (orange) ────┼──────────────────┼── D9 (TX)    │
    │  1- (org/hvid) ──┼────┐             │              │
    │  W1 (gul) ───────┼────┼─────────────┼── A0 (RX)    │
    │  GND (sort) ─────┼────┴─────────────┼── GND        │
    └──────────────────┘                  └──────────────┘
```

### 2.5 Test 1: Verificer TX-Udgang

**Mål:** Bekræft at Pin D9 udsender en 2 kHz firkantbølge.

**WaveForms Scope Indstillinger:**

| Parameter | Værdi |
|---|---|
| Kanal 1 | Aktiveret, DC kobling |
| Område | 0-5V |
| Tid/Div | 200 µs |
| Trigger | Ch1, Stigende, 2.5V |

**Forventet Resultat:**

| Måling | Forventet | Tolerance |
|---|---|---|
| Frekvens | 2.000 kHz | ±1% |
| Periode | 500 µs | ±5 µs |
| Duty Cycle | 50% | ±2% |
| Amplitude | 5V | - |

### 2.6 Test 2: Injicer Testsignal

**Mål:** Send en 2 kHz sinusbølge ind på A0 og verificer DFT.

**WaveForms Wavegen Indstillinger:**

| Parameter | Værdi |
|---|---|
| Type | Sinus |
| Frekvens | 2000 Hz |
| Amplitude | 2 V (Vpp) |
| Offset | 2.5 V |

**Forventet Display Output:**

| Værdi | Forventet |
|---|---|
| Re/Im | Ikke-nul |
| Mag | ~60-120 for 2Vpp |
| Fase | Roterer (usynkroniseret) |

> [!warning] Fasedrift er Normal
> AD3 og Arduino har uafhængige clocks. Fasen vil rotere langsomt - dette bekræfter at fasedetektion virker!

---

## 3. RC Loopback Test

### 3.1 Formål

Verificer fasemåling ved at bruge et RC filter til at skabe et kendt faseskift. Kræver kun passive komponenter.

### 3.2 Teori

**Basisfase:** TX firkantbølgen giver en basisfase på **-45°** (uden filter).

**RC Filter Faseskift:** Et RC lavpasfilter tilføjer ekstra faseskift:
$$\text{Faseskift} \approx -\arctan(2\pi f R C)$$

**Total målt fase:** Basisfase + RC skift

### 3.3 Komponenter

| Komponent | Værdi | Noter |
|---|---|---|
| Modstand | 1 kΩ | 1/4W |
| Kondensator | 100 nF | Keramisk/film |
| Jumperwires | 2 stk | |

### 3.4 Kredsløb

```text
                    R (1kΩ)
    D9 (TX) ───────/\/\/\/───────┬─────── A0 (RX)
                                 │
                              ───┴───
                              ───┬─── C (100nF)
                                 │
    GND ─────────────────────────┴─────── GND
```

**Breadboard:**
1. D9 → 1kΩ modstand
2. Modstand → A0 + Kondensator
3. Kondensator → GND

### 3.5 Forventede Resultater

| Konfiguration | Forventet Fase | Tolerance |
|---|---|---|
| Kun modstand (ingen C) | -45° | ±5° |
| 1kΩ + 100nF | -145° | ±15° |

### 3.6 Alternative RC Værdier

| Modstand | Kondensator | Målt Fase |
|---|---|---|
| Enhver | Ingen | -45° (basis) |
| 560 Ω | 100 nF | ~ -100° |
| 1 kΩ | 100 nF | ~ -145° |
| 2.2 kΩ | 100 nF | ~ -160° |

> [!tip] Verifikation
> Øgning af R eller C bør gøre fasen mere negativ.
> Fjernelse af kondensator bør returnere til -45°.

### 3.7 Godkendelseskriterier

- [ ] Uden kondensator: Fase ≈ -45° (±5°)
- [ ] Med 1kΩ + 100nF: Fase ≈ -145° (±15°)
- [ ] Faseaflæsning er stabil (hopper ikke)
- [ ] Magnitude er ikke-nul og stabil

---

## 4. DFT Verifikation med MATLAB

### 4.1 Formål

Verificer at Arduinoens **optimerede 4-sample DFT** matcher **MATLAB FFT**.

| Implementation | Metode |
|---|---|
| **Arduino** | Optimeret 4-sample akkumulering (kun bin k=16) |
| **MATLAB** | `X = fftshift(fft(x))/N` (DSP kursus konvention) |

### 4.2 Krav

**Hardware:**
- Arduino Nano med firmware (`CAPTURE_SAMPLES = 1`)
- USB-forbindelse

**Software:**
- MATLAB (R2019b eller nyere)
- Firmware uploadet: `pio run -t upload`

### 4.3 Brug

```matlab
% I MATLAB, naviger til Docs/Matlab/ og kør:
verify_dft
```

1. Vælg COM-port fra listen
2. MATLAB fanger automatisk 64 samples
3. Beregner FFT og sammenligner med Arduino
4. Viser PASS/FAIL og grafer

### 4.4 Forventet Output

```text
========================================
   DFT Verification - VLF Metal Detector
========================================

         Arduino    MATLAB     Error
Re:       -11539    -11539        0
Im:        -7982     -7982        0
Mag:         221       221        0
Phase:      -145      -145        0°

*** PASS - Arduino optimization matches standard FFT! ***
```

### 4.5 Grafisk Output

Scriptet genererer fire grafer i `Docs/Images/`. Disse bruges til at verificere at Arduino DFT matcher MATLAB FFT.

#### 4.5.1 Tidsdomæne Samples
Viser de 64 ADC samples (DC fjernet):

![[../Images/dft_samples.png]]

#### 4.5.2 FFT Spektrum
Centreret magnitude spektrum ($-F_s/2$ til $+F_s/2$) med ±2kHz fremhævet:

![[../Images/dft_spectrum.png]]

> [!info] Konjugeret Symmetri
> For reelle signaler gælder $|X(-f)| = |X(f)|$.
> En cosinus ved 2kHz giver peaks ved **både** +2kHz og -2kHz:
> $$\cos(2\pi f t) = \frac{e^{j2\pi f t} + e^{-j2\pi f t}}{2}$$
> Arduino behøver kun beregne +2kHz da amplituden er identisk.

#### 4.5.3 Phasor Diagram
Sammenligning af Arduino (optimeret) og MATLAB FFT phasors:

![[../Images/dft_phasor.png]]

#### 4.5.4 Verifikations-Sammenfatning
Oversigt over metode og resultater:

![[../Images/dft_comparison.png]]

> [!note] Opdater graferne
> Kør `verify_dft` i MATLAB for at generere nye grafer med aktuelle data.

### 4.6 Matematisk Baggrund

#### Arduino: Optimeret Single-Bin DFT

Arduino udnytter at vi sampler ved **4× signalfrekvensen**:
- $f_s = 8000$ Hz, $f_{signal} = 2000$ Hz
- Bin 16 svarer til 2kHz: $k = f_{signal} \cdot N / f_s = 2000 \cdot 64 / 8000 = 16$

Ved bin 16 bliver DFT koefficienterne trivielle:

| Sample n mod 4 | cos(2πn/4) | -sin(2πn/4) | Operation |
|---|---|---|---|
| 0 | +1 | 0 | Re += x[n] |
| 1 | 0 | -1 | Im -= x[n] |
| 2 | -1 | 0 | Re -= x[n] |
| 3 | 0 | +1 | Im += x[n] |

#### MATLAB: DSP Kursus Konvention (62743)

Vi bruger den normaliserede, centrerede FFT:
$$X[k] = \frac{1}{N} \sum_{n=0}^{N-1} x[n] \cdot e^{-j2\pi kn/N}$$

```matlab
% DSP kursus konvention: normaliseret og centreret
X = fftshift(fft(samples)) / N;
f_axis = (-N/2:N/2-1) * (Fs/N);    % Frekvensakse [Hz]

% Find 2kHz bin via frekvensakse
[~, idx] = min(abs(f_axis - 2000));
X_2kHz = X(idx);

% Skaler tilbage for Arduino sammenligning
Re = real(X_2kHz) * N;
Im = imag(X_2kHz) * N;
```

### 4.7 Tolerancer

| Parameter | Tolerance | Beskrivelse |
|---|---|---|
| Magnitude | ±5 | Efter division med N |
| Fase | ±3° | Grader |

> [!tip] Forventede afvigelser
> Små afvigelser skyldes floating-point vs integer afrunding.
> Re/Im bør matche præcist da begge metoder bruger samme samples.

### 4.8 Firmware Konfiguration

I `Code/src/include/capture.h`:

```c
#define CAPTURE_SAMPLES 1    // Aktiver capture mode
#define UART_BAUD 115200     // Serial hastighed
```

### 4.9 Serial Protokol

| Kommando | Respons | Beskrivelse |
|---|---|---|
| (connect) | `READY` | Arduino klar efter reset |
| `C` | `ACK` + data | Trigger capture af 64 samples |

### 4.10 Filer

| Fil | Placering | Beskrivelse |
|-----|---|---|
| `verify_dft.m` | `Docs/Matlab/` | Verifikationsscript (DSP konvention) |
| `dft_samples.png` | `Docs/Images/` | Tidsdomæne plot |
| `dft_spectrum.png` | `Docs/Images/` | Centreret FFT spektrum (±4kHz) |
| `dft_phasor.png` | `Docs/Images/` | Phasor diagram |
| `dft_comparison.png` | `Docs/Images/` | Resultat-sammenfatning |

---

## 5. Fejlfinding

### 5.1 Generelle Problemer

| Problem | Mulig Årsag | Løsning |
|---|---|---|
| Intet TX signal | Firmware kører ikke | Tjek upload, verificer `sei()` kaldes |
| TX forkert frekvens | Timer0 config forkert | Verificer OCR0A = 249, prescaler = 8 |
| Mag altid 0 | Intet signal på A0 | Tjek forbindelser |
| Display opdaterer ikke | DFT_done ikke sat | Tjek ADC ISR kører |

### 5.2 AD3-Specifikke Problemer

| Problem | Løsning |
|---|---|
| Fase "over det hele" | **Normalt!** Bekræfter fase virker (uafhængige clocks) |
| Intet wavegen signal | Tjek W1 forbindelse, verificer Wavegen kører |

### 5.3 RC Loopback Problemer

| Problem | Løsning |
|---|---|
| Fase nær -45° med kondensator | Kondensator ikke forbundet korrekt |
| Fase hopper | Løse forbindelser, brug kortere ledninger |
| Magnitude meget lav | Verificer modstand er 1kΩ, ikke 1MΩ |

### 5.4 MATLAB Problemer

| Problem | Løsning |
|---|---|
| "No serial ports available" | Tjek USB-forbindelse |
| Timeout ved READY | Vent på Arduino reset |
| Parsed 0 samples | Prøv igen, tjek `CAPTURE_SAMPLES = 1` |

---

## 6. Relaterede Dokumenter

- [[Assembly_Guide|Samlevejledning]] - Hardware opsætning
- [[Code_Review|Firmware Gennemgang]] - Kodestruktur
- [[../Theory/DFT Algorithm|DFT Algoritme]] - Matematisk baggrund

---

*Testguide til DTU 34621 Metaldetektor Projekt*

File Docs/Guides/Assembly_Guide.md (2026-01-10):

# VLF Metaldetektor - Montagevejledning

## Arduino Nano Breadboard Ledningsføring

Denne guide viser hvordan man forbinder Arduino Nano til DTU 34621 Metaldetektor projektet.

**Nuværende Status:** Minimal testkonfiguration til kerne TX/RX/DSP test.

---

## Komponentliste (Minimal Testversion)

| Komponent | Antal | Noter |
|---|---|---|
| Arduino Nano | 1 | ATmega328P, 16MHz |
| Breadboard | 1 | Fuld størrelse anbefalet |
| SSD1306 OLED Display | 1 | 128x64, I2C interface |
| Trykknap | 1 | Debug skærm skift (D4) |
| TX Spole driver | 1 | H-bro eller transistor kredsløb |
| RX Spole forstærker | 1 | Op-amp kredsløb til spolesignal |
| Jumperwires | ~10 | Forskellige farver anbefalet |

### Komponenter til Senere (Ikke Brugt i Minimal Version)

| Komponent | Antal | Noter |
|---|---|---|
| Trykknap | 1 | Start/Stop (D2) |
| Piezo buzzer | 1 | Til lydtilbagemelding |

---

## Pin Forbindelser

### Arduino Nano Pinout Oversigt

```
                     +-----+
                     | USB |
                     +-----+
            +--------+-----+--------+
        TX1 | [ ]  D1|     |VIN [ ] | VIN
        RX0 | [ ]  D0|     |GND [ ] | GND
            | [ ] RST|     |RST [ ] |
            | [ ] GND|     |5V  [ ] | 5V
            | [ ]  D2|     |A7  [ ] |
            | [ ]  D3|     |A6  [ ] |
 DEBUG  [X] | [X]  D4|     |A5  [X] | SCL
            | [ ]  D5|     |A4  [X] | SDA
            | [ ]  D6|     |A3  [ ] |
            | [ ]  D7|     |A2  [ ] |
            | [ ]  D8|     |A1  [ ] |
 TX-UD  [X] | [X]  D9|     |A0  [X] | RX-IND
            | [ ] D10|     |AREF[ ] |
 MOSI       | [ ] D11|     |3V3 [ ] |
 MISO       | [ ] D12|     |D13 [ ] | SCK
            +-------+-------+-------+

[X] = Brugt i minimal testversion
```

---

## Ledningstabel (Minimal Testversion)

| Funktion | Arduino Pin | Port | Retning | Forbindelse |
|---|---|---|---|---|
| **TX Signal** | D9 | PB1 | Udgang | TX spole driver indgang |
| **RX Indgang** | A0 | PC0 | Indgang | RX forstærker udgang |
| **Debug Knap** | D4 | PD4 | Indgang | Knap til GND |
| **OLED SDA** | A4 | PC4 | I2C | Display SDA |
| **OLED SCL** | A5 | PC5 | I2C | Display SCL |
| **5V** | 5V | - | Strøm | Display VCC, komponenter |
| **GND** | GND | - | Strøm | Fælles stel |

### Pins Reserveret til Fremtidig Brug

| Funktion | Arduino Pin | Port | Noter |
|---|---|---|---|
| Start/Stop Knap | D2 | PD2 | Tilføjes senere |
| Buzzer | D3 | PD3 | Tilføjes senere |
| Debug Pin | D8 | PB0 | Valgfri oscilloskop |

---

## Ledningsdiagram (ASCII)

```
                                    +------------------+
                                    |   SSD1306 OLED   |
                                    |                  |
                                    | VCC  GND  SCL SDA|
                                    +--+---+----+---+--+
                                       |   |    |   |
                                       |   |    |   |
    +----------------------------------+---+----+---+-----------+
    |                                  |   |    |   |           |
    |  ARDUINO NANO                    |   |    |   |           |
    |  +-----------+                   |   |    |   |           |
    |  |           |                   |   |    |   |           |
    |  |       5V  +-------------------+   |    |   |           |
    |  |      GND  +---[FÆLLES STEL]-------+    |   |           |
    |  |       A5  +------------------------+   |   |           |
    |  |       A4  +----------------------------+   |           |
    |  |       A0  +---[RX FORSTÆRKER UDGANG]-------+           |
    |  |           |                                            |
    |  |       D9  +---[TX SPOLE DRIVER INDGANG]                |
    |  |           |                                            |
    |  |       D4  +---+                                        |
    |  |           |   |  +-------+                             |
    |  +-----------+   +--+ KNAP  +--[GND]   (Debug skift)      |
    |                     +-------+                             |
    +-----------------------------------------------------------+
```

---

## Trin-for-Trin Ledningsinstruktioner

### Trin 1: Placer Arduino Nano på Breadboard

1. Indsæt Arduino Nano så den strækker sig over midtergabet på breadboardet
2. Sørg for at alle pins er sat ordentligt i
3. Efterlad plads på begge sider til komponentforbindelser

### Trin 2: Strømskinner

1. Forbind Arduino **5V** til breadboard **+** skinne (rød)
2. Forbind Arduino **GND** til breadboard **-** skinne (blå)
3. Hvis du bruger begge sider, forbind strømskinnerne

### Trin 3: OLED Display (I2C)

| OLED Pin | Forbind Til |
|---|---|
| VCC | 5V skinne (+) |
| GND | GND skinne (-) |
| SCL | Arduino A5 |
| SDA | Arduino A4 |

### Trin 4: TX Spole Driver

Forbind Arduino **D9** til din TX spole driver kredsløbs indgang.

Signalkarakteristika:
- Frekvens: 2 kHz firkantbølge
- Spænding: 0-5V logikniveau
- Strøm: ~20mA maks (brug driver kredsløb til spole)

### Trin 5: RX Spole Forstærker

Forbind din RX forstærker udgang til Arduino **A0**.

Signalkrav:
- Spændingsområde: 0-5V (centreret ved 2.5V anbefalet)
- Frekvens: 2 kHz (samme som TX)
- Båndbredde: Forstærker skal passere 2 kHz signal

### Trin 6: Debug Knap (D4)

Forbind en trykknap mellem **D4** og **GND**.

```
Arduino D4 ----+---- KNAP ----+---- GND
               |              |
          (intern pull-up aktiveret i kode)
```

> **Bemærk:** Ingen ekstern modstand nødvendig - koden aktiverer intern pull-up.
> Tryk for at skifte mellem DFT og Debug skærme.

---

## Verifikationstjekliste (Minimal Testversion)

Efter ledningsføring, verificer hver forbindelse:

- [ ] **Strøm:** 5V og GND skinner forbundet
- [ ] **OLED:** Display viser "Starter..." derefter DFT skærm
- [ ] **Debug Knap:** Tryk D4 knap - skærm skifter til DEBUG
- [ ] **TX Signal:** Oscilloskop på D9 viser 2 kHz firkantbølge
- [ ] **RX Indgang:** A0 modtager signal fra RX forstærker
- [ ] **Display Værdier:** Re, Im, Mag, Fase værdier opdateres på skærm

---

## Forventet Display Output

Tryk på **D4 knappen** for at skifte mellem to skærme:

**Skærm 1: DFT Resultater**
```
=== DFT ===

Re:   <værdi>
Im:   <værdi>

Mag:  <værdi>
Fase: <værdi> grader
```

**Skærm 2: Debug Info**
```
=== DEBUG ===

ADC:  <rå værdi>
```

| Værdi | Beskrivelse |
|---|---|
| **Re/Im** | DFT komponenter (kan være negative) |
| **Mag** | Magnitude = sqrt(Re² + Im²) / 16 |
| **Fase** | Fasevinkel i grader |
| **ADC** | Nuværende rå ADC værdi (0-1023) |

---

## Fejlfinding

| Problem | Mulig Årsag | Løsning |
|---|---|---|
| Intet display | I2C ledningsføring forkert | Tjek A4/A5 forbindelser, verificer I2C adresse |
| Display viser vrøvl | Forkert I2C adresse | Prøv 0x7A i stedet for 0x78 |
| Intet TX signal | Timer kører ikke | Tjek sei() kaldes, verificer D9 forbindelse |
| Re/Im altid 0 | Intet RX signal | Verificer RX forstærker udsender 0-5V på A0 |
| Re/Im altid samme fortegn | DC offset forkert | ADC bør være centreret ved ~512 |
| Fase sidder fast på 0 eller 90 | Ingen signalvariation | Tjek spoleforbindelser |

---

## Sikkerhedsnoter

1. **Overskrid ikke 5V** på nogen indgangspin
2. **Træk ikke mere end 20mA** fra nogen enkelt pin
3. **Brug driver kredsløb** til spoler - driv ikke direkte fra pins
4. **Afbryd strøm** før ledningsændringer

---

## Fremtidige Tilføjelser

Når klar til at tilføje UI funktioner, forbind:

| Komponent | Pin | Noter |
|---|-----|---|
| Start/Stop Knap | D2 til GND | Intern pull-up i kode |
| Buzzer (+) | D3 | Negativ til GND |
| Debug Pin | D8 | Til oscilloskop timing |

---

## Reference

- ATmega328P Datasheet: Rev. 7810D-AVR-01/15
- Arduino Nano Pinout: https://www.arduino.cc/en/uploads/Main/ArduinoNanoManual23.pdf

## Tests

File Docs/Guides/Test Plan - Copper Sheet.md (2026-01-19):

# Test Plan: Copper Sheet (Non-Ferrous)

**Date:** 2026-01-19
**Tester:**
**Equipment:** Metal detector, 98K potentiometer, copper sheet
**Gain setting:** ~50-60% (optimal from previous test)

---

## Step 1: Calibrate
- [x] Set pot to **50-60%** position
- [x] No metal near coil
- [x] Press calibrate button

| Measurement | Value |
|---|---|
| Amplitude | 3 |
| Phase | 90 |

---

## Step 2: Copper on Coil (0 cm)
- [x] Place copper sheet directly on coil

| Measurement | Value |
|---|---|
| Amplitude | 50 |
| Phase | -40 |

---

## Step 3: Copper at 5 cm
- [x] Hold copper sheet ~5 cm above coil

| Measurement | Value |
|---|---|
| Amplitude | 36 |
| Phase | -37 |

---

## Step 4: Copper at 10 cm
- [x] Hold copper sheet ~10 cm above coil

| Measurement | Value |
|---|---|
| Amplitude | 25 |
| Phase | -25 |

---

## Comparison: Metal Cap vs Copper Sheet

| Test Object | Amplitude | Phase | Δ Phase from baseline |
|---|---|---|---|
| No metal (baseline) | 3 | 90° | 0° |
| Metal cap (ferro) | 11 | 120° | +30° |
| Copper sheet (non-ferro) | 50 | -40° | -130° |

---

## Expected Result

- **Ferrous metals** (steel, iron): Phase shift **positive** (towards +180°)
- **Non-ferrous metals** (copper, aluminum): Phase shift **negative** (towards -180°) or smaller positive shift

The copper sheet should show a **different phase response** than the metal cap if your ferro/non-ferro detection is working.

---

## Notes / Observations

### Konklusion

**Fase-detektion virker korrekt** - Testen bekræftede at fase-responsen er tydelig forskellig mellem ferro og non-ferro metaller:
- **Metal cap (ferro):** Fase går **positiv** (90° → 120° = +30°)
- **Kobber (non-ferro):** Fase går **negativ** (90° → -40° = -130°)

**Kobber giver stærkere signal** - Amplitude 50 vs 11 for metal cap. Dette skyldes kobbers høje ledningsevne som skaber stærke hvirvelstrømme.

**Afstandsdetektion virker** - Amplitude falder med afstand som forventet:
- 0 cm: Amplitude 50
- 5 cm: Amplitude 36
- 10 cm: Amplitude 25

### Software-fejl fundet og rettet

Under testen opdagede vi at klassificeringen var **inverteret** i koden:
- Koden sagde: negativt faseskift = ferro (FORKERT)
- Virkeligheden: negativt faseskift = non-ferro (KORREKT)

**Løsning:** Klassificeringslogikken blev rettet så:
- Positivt faseskift → FERRO (jern, stål)
- Negativt faseskift → NON-FERRO (kobber, aluminium)

### Tærskelværdier justeret

Den oprindelige magnitude-tærskel (+20) var for høj til at detektere svagere signaler. Sænket til 20% af baseline eller minimum +3 for bedre følsomhed.

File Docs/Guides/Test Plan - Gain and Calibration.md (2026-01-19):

# Test Plan: Gain & Calibration

**Date:** 2026-01-19
**Tester:**
**Equipment:** Metal detector, 98K potentiometer, metal cap test object

---

## Step 1: Minimum Gain (Baseline)
- [x] Turn pot fully **counter-clockwise** (minimum gain)
- [x] No metal near coil

| Measurement | Value |
|---|---|
| Amplitude | 1 |
| Phase | 60 |

---

## Step 2: Calibrate at Minimum Gain
- [x] Press calibrate button (no metal near coil)
- [x] Wait for calibration to complete

| Measurement | Value |
|---|---|
| Amplitude | 1 |
| Phase | 60 |

---

## Step 3: Metal Test at Minimum Gain
- [x] Place metal cap directly on coil

| Measurement | Value |
|---|---|
| Amplitude | 1 |
| Phase | 60 |

---

## Step 4: Medium Gain (~50%)
- [x] Turn pot to **middle position**
- [x] Remove metal, no metal near coil

| Measurement | Value |
|---|---|
| Amplitude | 3 |
| Phase | 90 |

---

## Step 5: Calibrate at Medium Gain
- [x] Press calibrate button (no metal near coil)

| Measurement | Value |
|---|---|
| Amplitude | 3 |
| Phase | 90 |

---

## Step 6: Metal Test at Medium Gain
- [x] Place metal cap directly on coil

| Measurement | Value |
|---|---|
| Amplitude | 11 |
| Phase | 120 |

---

## Step 7: High Gain (~80%)
- [x] Turn pot to **80% position**
- [x] Remove metal, no metal near coil

| Measurement | Value |
|---|---|
| Amplitude | 4 |
| Phase | 100 |

---

## Step 8: Calibrate at High Gain
- [x] Press calibrate button (no metal near coil)

| Measurement | Value |
|---|---|
| Amplitude | 4 |
| Phase | 100 |

---

## Step 9: Metal Test at High Gain
- [x] Place metal cap directly on coil

| Measurement | Value |
|---|---|
| Amplitude | 14 |
| Phase | 123 |

---

## Step 10: Optimal Gain - Distance Test
- [ ] Find gain where no-metal reading is stable (not noisy)
- [ ] Calibrate at this gain setting

**Optimal pot position:** ____%

| Distance | Amplitude | Phase | Detected? |
|---|---|---|---|
| 0 cm | | | |
| 5 cm | | | |
| 10 cm | | | |
| 15 cm | | | |

---

## Notes / Observations

### Konklusion

**Minimum gain er for lav** - Ved minimum gain (amplitude=1) kunne detektoren slet ikke registrere metal. Amplitude og fase forblev uændret med metal på spolen.

**50% og 80% gain virker begge** - Begge indstillinger viste tydelig amplitude stigning og faseskift når metal var til stede:
- 50% gain: Amplitude 3→11 (3.7x stigning), fase +30°
- 80% gain: Amplitude 4→14 (3.5x stigning), fase +23°

**Anbefalet driftsindstilling: 50-60% gain**
- God detekteringsfølsomhed
- Tilstrækkelig hovedrum til større metalobjekter
- Lavere støjniveau end ved højere gain

### Hardware ændringer under test

Oprindeligt blev en 470K potentiometer brugt, men dette gav alt for høj forstærkning (op til 4700x). Signalet klippede kraftigt ved selv lave pot-indstillinger.

**Løsning:** Skiftet til 98K potentiometer, som giver en mere brugbar forstærkningsområde (1x til ~981x) hvor hele potentiometerets rotation kan udnyttes.

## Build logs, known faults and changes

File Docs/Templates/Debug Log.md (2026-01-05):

# Bug: {{title}}

**Date:** {{date}}  
**Status:** 🔴 Open | 🟡 In Progress | 🟢 Resolved  
**Severity:** 🔥 Critical | ⚠️ High | 📋 Medium | 💡 Low

---

## Symptoms

## Expected Behavior

## Actual Behavior

## Steps to Reproduce
1. 
2. 
3. 

## Environment
- **Board:** Arduino Mega 2560 / Uno
- **Code Version:** 
- **Hardware Setup:** 

## Investigation

### Hypothesis 1

### Measurements

### Debug Output
```
// Serial output or measurements
```

## Root Cause

## Solution

## Prevention
How to prevent this in the future:

---
#bug #debug

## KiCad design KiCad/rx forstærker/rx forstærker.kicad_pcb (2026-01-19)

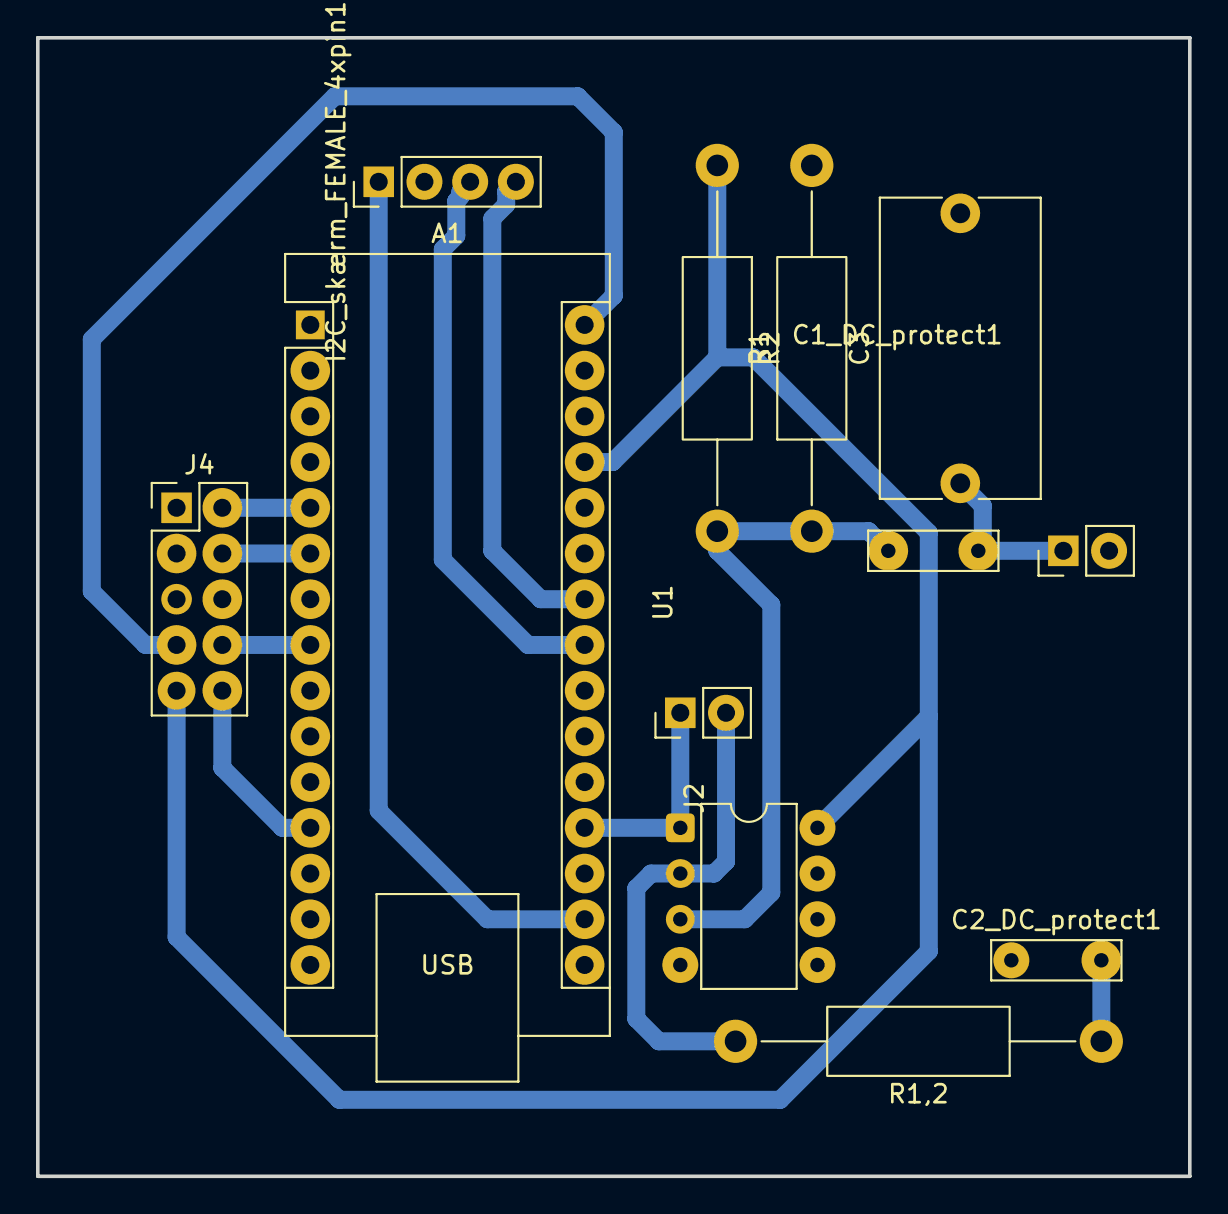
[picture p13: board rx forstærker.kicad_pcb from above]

Board: 2 copper layers, 64.0 x 63.2 mm, 12 parts (0 on the bottom side), 15 nets.

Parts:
A1: Arduino_Nano
C1_DC_protect1: 1u; C_Rect_L7.0mm_W2.0mm_P5.00mm
C2_DC_protect1: C; C_Rect_L7.0mm_W2.0mm_P5.00mm
C3: 150n; C_Rect_L16.5mm_W8.7mm_P15.00mm_MKT
I2C_skærm_FEMALE_4xpin1: Conn_01x04_Pin; PinHeader_1x04_P2.54mm_Vertical
J1: Rx spole; PinHeader_1x02_P2.54mm_Vertical
J2: Pot_pins_2xpin; PinHeader_1x02_P2.54mm_Vertical
J4: MALE Headers 5xpin; PinHeader_2x05_P2.54mm_Vertical
R1, R2: 100k; R_Axial_DIN0411_L9.9mm_D3.6mm_P20.32mm_Horizontal
R1,2: 1000; R_Axial_DIN0411_L9.9mm_D3.6mm_P20.32mm_Horizontal
U1: MCP6002-xMC; DIP-8_W7.62mm

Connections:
+5V: A1.27 (+5V), J4.9, R2.1, U1.8 (V+)
+9V: A1.30 (VIN), J4.7
/2.5V: C1_DC_protect1.2, R1.1, R2.2, U1.3
/Kalibrering: A1.6 (D3), J4.4
/PA_power_off: A1.8 (D5), J4.8
/Rx_ADC: A1.19 (A0), J2.1, U1.1
/SCL: A1.24 (A5), I2C_skærm_FEMALE_4xpin1.4
/SDA: A1.23 (A4), I2C_skærm_FEMALE_4xpin1.3
/Start/Stop: A1.5 (D2), J4.2
/TX_out->PA: A1.12 (D9), J4.10
/Vin: A1.17 (3V3), I2C_skærm_FEMALE_4xpin1.1
/rx spole. 12.225mH og 71 ohm: C1_DC_protect1.1, C3.1, J1.1
GND: A1.4 (GND), A1.29 (GND), C2_DC_protect1.1, C3.2, I2C_skærm_FEMALE_4xpin1.2, J4.1, J4.3, R1.2, U1.4 (V-)
unnamed: C2_DC_protect1.2, R1,2.1
unnamed: J2.2, R1,2.2, U1.2

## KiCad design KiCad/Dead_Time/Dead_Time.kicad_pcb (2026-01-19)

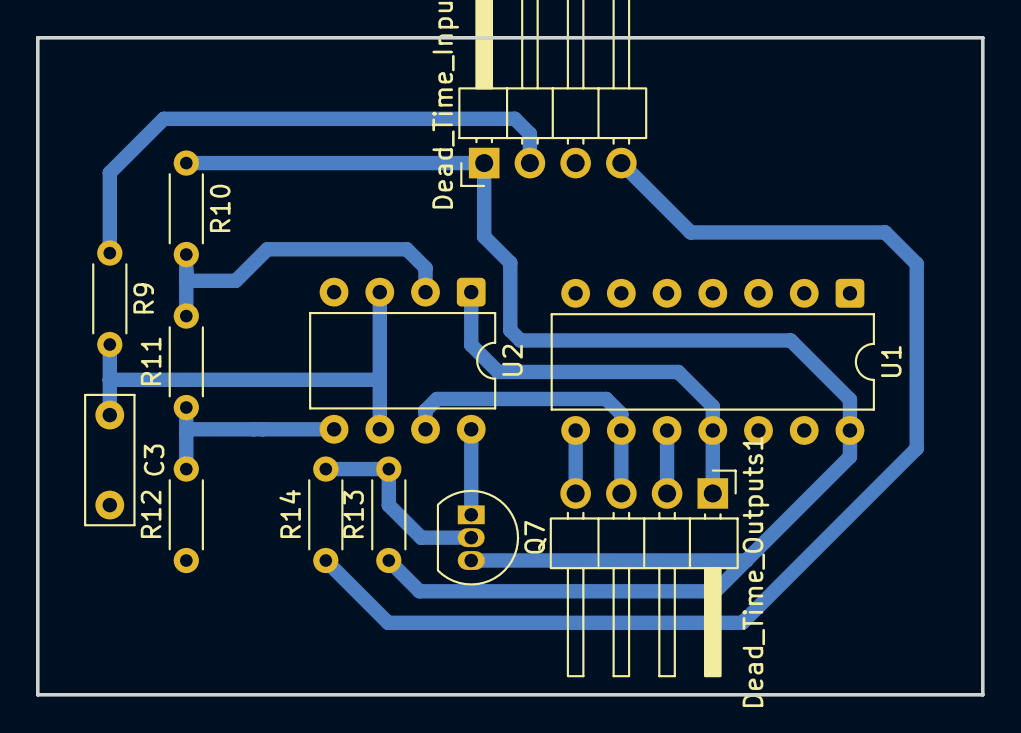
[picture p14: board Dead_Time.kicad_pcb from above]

Board: 2 copper layers, 52.5 x 36.5 mm, 12 parts (0 on the bottom side), 13 nets.

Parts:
C3: 4n8; C_Rect_L7.0mm_W2.5mm_P5.00mm
Dead_Time_Inputs1: Conn_01x04_Pin; PinHeader_1x04_P2.54mm_Horizontal
Dead_Time_Outputs1: Conn_01x04_Pin; PinHeader_1x04_P2.54mm_Horizontal
Q7: PNP_BC558; TO-92_Inline
R9: 15k; R_Axial_DIN0204_L3.6mm_D1.6mm_P5.08mm_Horizontal
R10, R12: 2k25; R_Axial_DIN0204_L3.6mm_D1.6mm_P5.08mm_Horizontal
R11: 500; R_Axial_DIN0204_L3.6mm_D1.6mm_P5.08mm_Horizontal
R13: 10k; R_Axial_DIN0204_L3.6mm_D1.6mm_P5.08mm_Horizontal
R14: 1k; R_Axial_DIN0204_L3.6mm_D1.6mm_P5.08mm_Horizontal
U1: 74AUC2G04; DIP-14_W7.62mm
U2: MCP6002; DIP-8_W7.62mm

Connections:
+5V: Dead_Time_Inputs1.1, Q7.3 (E), R10.1, R13.1, U1.14
/KILL_SWITCH: Q7.1 (C), U2.8 (V+)
/Meas_VStep1: R10.2, R11.2, U2.2 (-)
/Meas_VStep2: R11.1, R12.2, U2.5 (+)
/PWM1: Dead_Time_Outputs1.1, U1.11, U2.1
/PWM1_NOT: Dead_Time_Outputs1.2, U1.10
/PWM2: Dead_Time_Outputs1.3, U1.9, U2.7
/PWM2_NOT: Dead_Time_Outputs1.4, U1.8
/PWM_In: Dead_Time_Inputs1.2, R9.1
/on/off: Dead_Time_Inputs1.4, R14.1
GND: C3.2, Dead_Time_Inputs1.3, R12.1, U1.7, U2.4 (V-)
unnamed: Q7.2 (B), R13.2, R14.2
unnamed: C3.1, R9.2, U2.3 (+), U2.6 (-)

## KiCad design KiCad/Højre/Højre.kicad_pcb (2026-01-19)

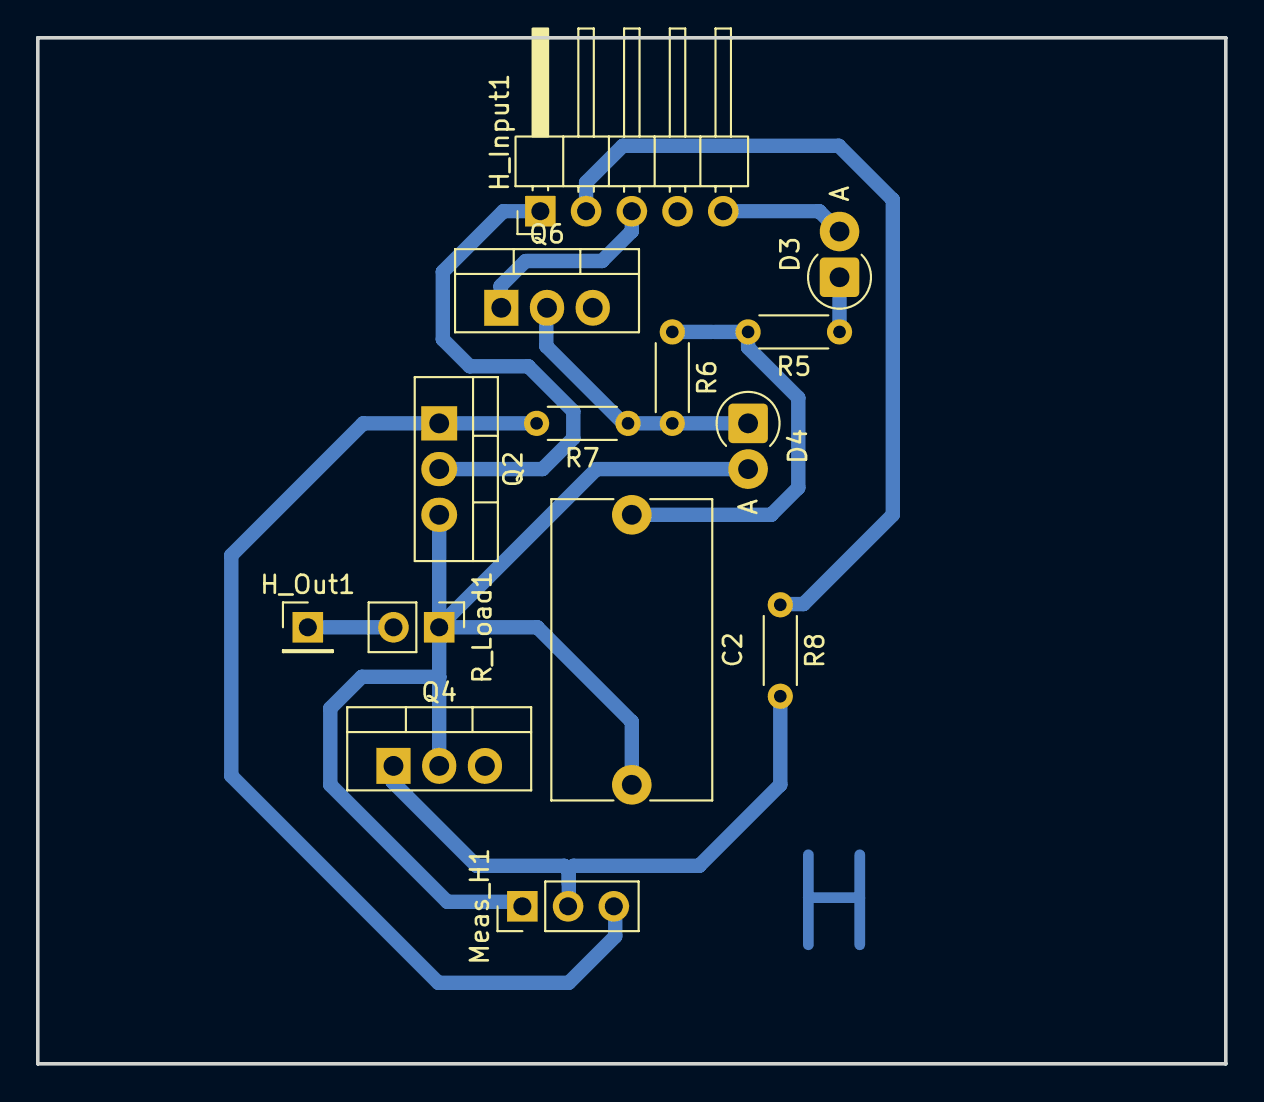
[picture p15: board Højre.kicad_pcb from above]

Board: 2 copper layers, 66.0 x 57.0 mm, 14 parts (0 on the bottom side), 12 nets.

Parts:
C2: 820n; C_Rect_L16.5mm_W8.7mm_P15.00mm_MKT
D3, D4: D; D_DO-41_SOD81_P2.54mm_Vertical_AnodeUp
H_Input1: Conn_01x05_Pin; PinHeader_1x05_P2.54mm_Horizontal
H_Out1: Conn_01x01_Pin; PinHeader_1x01_P2.54mm_Vertical
Meas_H1: Conn_01x03_Pin; PinHeader_1x03_P2.54mm_Vertical
Q2, Q4, Q6: NMOS_IRL530; TO-220-3_Vertical
R5, R7, R8: 1; R_Axial_DIN0204_L3.6mm_D1.6mm_P5.08mm_Horizontal
R6: 1k; R_Axial_DIN0204_L3.6mm_D1.6mm_P5.08mm_Horizontal
R_Load1: 47; PinHeader_1x02_P2.54mm_Vertical

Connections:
+5V: D3.2 (A), H_Input1.5
+9V: H_Input1.1, Q2.2 (G)
/Meas_GATE_M2: Meas_H1.3, Q2.1 (D), R7.2
/Meas_GATE_M4: Meas_H1.2, Q4.1 (D), R8.2
/Meas_H_Out: C2.2, D4.2 (A), Meas_H1.1, Q2.3 (S), Q4.2 (G), R_Load1.1
/PWM1_NOT: H_Input1.3, Q6.1 (D)
/PWM2: H_Input1.2, R8.1
GND: H_Input1.4, Q4.3 (S), Q6.3 (S)
unnamed: C2.1, R5.2, R6.1
unnamed: D3.1 (K), R5.1
unnamed: D4.1 (K), Q6.2 (G), R6.2, R7.1
unnamed: H_Out1.1, R_Load1.2

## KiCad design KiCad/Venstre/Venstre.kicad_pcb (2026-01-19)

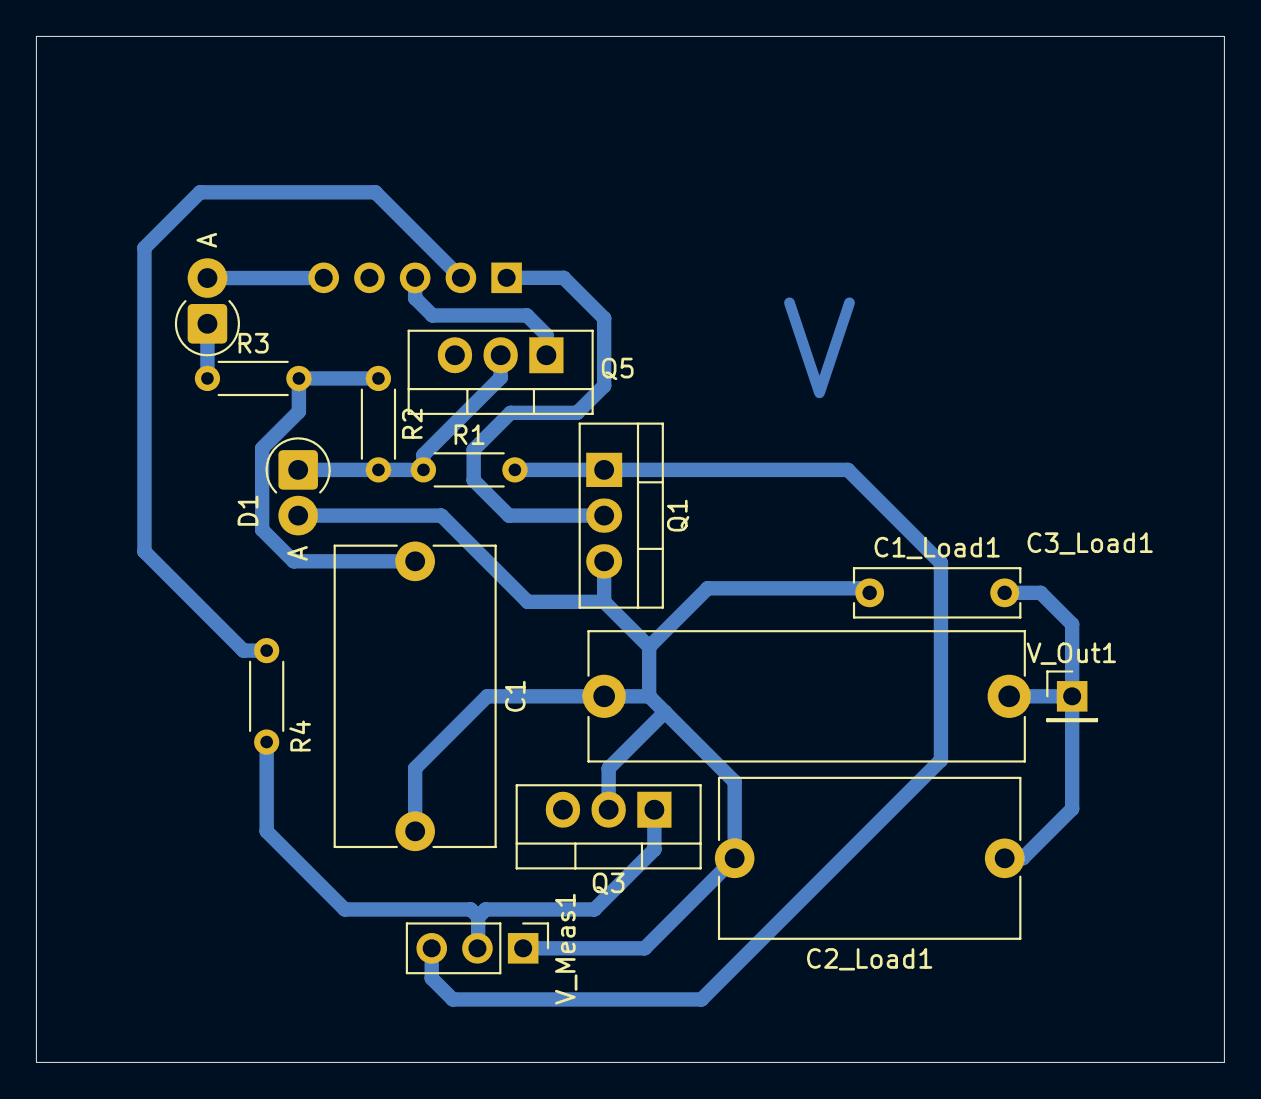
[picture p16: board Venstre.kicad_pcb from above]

Board: 2 copper layers, 66.0 x 57.0 mm, 16 parts (1 on the bottom side), 12 nets.

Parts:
C1, C2_Load1: 820n; C_Rect_L16.5mm_W8.7mm_P15.00mm_MKT
C1_Load1: 100n; C_Rect_L9.0mm_W2.5mm_P7.50mm_MKT
C3_Load1: 2u2; C_Rect_L24.0mm_W7.0mm_P22.50mm_MKT
D1, D2: D; D_DO-41_SOD81_P2.54mm_Vertical_AnodeUp
Q1, Q3, Q5: NMOS_IRL530; TO-220-3_Vertical
R1, R3, R4: 1; R_Axial_DIN0204_L3.6mm_D1.6mm_P5.08mm_Horizontal
R2: 1k; R_Axial_DIN0204_L3.6mm_D1.6mm_P5.08mm_Horizontal
V_Inputs1: Conn_01x05_Pin; PinHeader_1x05_P2.54mm_Horizontal
V_Meas1: Conn_01x03_Pin; PinHeader_1x03_P2.54mm_Vertical
V_Out1: Conn_01x01_Pin; PinHeader_1x01_P2.54mm_Vertical

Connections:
+5V: D2.2 (A), V_Inputs1.5
+9V: Q1.2 (G), V_Inputs1.1
/Meas_GATE_M1: Q1.1 (D), R1.2, V_Meas1.3
/Meas_GATE_M3: Q3.1 (D), R4.2, V_Meas1.2
/Meas_V_Out: C1.2, C1_Load1.1, C2_Load1.2, C3_Load1.1, D1.2 (A), Q1.3 (S), Q3.2 (G), V_Meas1.1
/PWM1: R4.1, V_Inputs1.2
/PWM2_NOT: Q5.1 (D), V_Inputs1.3
GND: Q3.3 (S), Q5.3 (S), V_Inputs1.4
unnamed: C1.1, R2.1, R3.2
unnamed: D1.1 (K), Q5.2 (G), R1.1, R2.2
unnamed: D2.1 (K), R3.1
unnamed: C1_Load1.2, C2_Load1.1, C3_Load1.2, V_Out1.1

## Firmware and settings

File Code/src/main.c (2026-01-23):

/*
 * Metal Detektor - Hovedprogram
 *
 * Hardware:
 *   Pin 9  = TX signal (2kHz firkantbølge til sendespole)
 *   Pin 11 = Buzzer output (PWM tone)
 *   Pin A0 = RX signal (modtaget signal fra modtagerspole)
 *   Pin A4 = I2C SDA (OLED display)
 *   Pin A5 = I2C SCL (OLED display)
 *   Pin D2 = Knap (Start/Stop detektor - Krav 9a)
 *   Pin D3 = Knap (Kalibrering - Krav 9b)
 *
 * Hvordan det virker:
 *   1. Timer0 genererer 8kHz interrupt og toggler TX pin hver 2. gang = 2kHz
 *   2. ADC sampler automatisk ved hver Timer0 interrupt = 8kHz sampling
 *   3. DFT akkumulerer 64 samples og beregner magnitude og fase
 *   4. Resultater vises på OLED display
 */

#include <avr/io.h>
#include <avr/interrupt.h>
#include <util/delay.h>

/* --- Modul includes --- */
#include "include/config.h"
#include "include/timer.h"
#include "include/adc.h"
#include "include/button.h"
#include "include/dft.h"
#include "include/filter.h"
#include "include/detection.h"
#include "include/display.h"
#include "include/buzzer.h"
#include "include/jingle.h"
#include "drivers/I2C.h"
#include "drivers/ssd1306.h"

/* --- Main --- */
int main(void) {
    // Initialiser hardware - Timer og ADC FØRST (uafhængig af display)
    Timer1_init();
    timer0_init();
    adc_init();
    button_init();
    buzzer_init();

    // Display init SIDST (kan blokere hvis OLED ikke er tilsluttet)
    I2C_Init();
    InitializeDisplay();
    clear_display();

    // VIGTIGT: Aktiver globale interrupts!
    sei();

    // Splash skærm + opstartslyd
    display_splash();
    play_startup_jingle();
    _delay_ms(500);
    clear_display();

    // Knap state til edge detection
    uint8_t btn_start_prev = 1;
    uint8_t btn_cal_prev = 1;

    // Hovedløkke
    while (1) {
        // Sleep mode styring
        if (do_sleep) {
            SMCR |= (1 << SE);      // Enable sleep mode (Idle mode)
        } else {
            SMCR &= ~(1 << SE);     // Disable sleep mode
        }

        // Når DFT vindue er færdigt, beregn og vis resultater
        if (DFT_done) {
            DFT_done = 0;
            if (detection_active) {
                DFT_Calc();         // Beregn magnitude og fase
                IIR_Filt();         // Filtrer værdier

                // Opdater buzzer baseret på signal styrke
                uint16_t signal = 0;
                if (is_calibrated && mag_filtered > cal_mag) {
                    signal = mag_filtered - cal_mag;
                }
                buzzer_update(signal);
            } else {
                // Detektor pauset - sluk buzzer
                buzzer_update(0);
            }

            // Opdater display
            display_dft();
        }

        // Tjek knap D2 - Start/Stop detektor (Krav 9a)
        uint8_t btn_start = button_read_start_stop();
        if (btn_start_prev && !btn_start) {    // Falling edge = trykket
            _delay_ms(50);                      // Debounce
            toggle_detection();
            clear_display();
        }
        btn_start_prev = btn_start;

        // Tjek knap D3 - Kalibrering (Krav 9b)
        uint8_t btn_cal = button_read_calibrate();
        if (btn_cal_prev && !btn_cal) {        // Falling edge = trykket
            _delay_ms(50);                      // Debounce
            calibrate();
            buzzer_beep(100);                   // Bekræftelses-beep
            display_calibrated();
            _delay_ms(1000);
            clear_display();
        }
        btn_cal_prev = btn_cal;

        _delay_ms(50);
    }
}

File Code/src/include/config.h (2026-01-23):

/*
 * config.h - Konfiguration for Metal Detektor
 *
 * Alle globale indstillinger og konstanter samlet ét sted
 */

#ifndef CONFIG_H
#define CONFIG_H

/* --- DFT indstillinger --- */
#define F_SAMPLE 8000       // Sample frekvens (Hz) - skal være 4x signal frekvens
#define F_SIGNAL 2000       // TX/RX signal frekvens (Hz)
#define N 64                // Antal samples per DFT vindue (flere = mere præcist, men langsommere)

/* --- DFT fasekoefficienter --- */
// For samples periodisk Pi/2 ved vælgelse af k = 16
// Dette sikrer at vi ikke behøver at lave udregninger med Realdel og Imaginærdel samtidig
// og ydermere betyder dette at vi kan forudregne og slippe for at regne med andet end +/- 1
#define RePhase1  1         // cos(0)
#define ImPhase2  1         // sin(Pi/2)
#define RePhase3 -1         // cos(Pi)
#define ImPhase4 -1         // sin(3Pi/2)

/* --- ADC indstillinger --- */
#define ADC_MIDDELVAERDI 512  // DC offset kompensation (512 = midt i 10-bit range)

/* --- Metal klassificering --- */
#define PHASE_THRESHOLD 5   // Grader - tærskel for ferro/non-ferro klassificering

/* --- Pin konfiguration --- */
// TX signal output
#define TX_PIN    PB1       // Pin 9 = TX signal (2kHz firkantbølge til sendespole)

// Knapper (active low med pull-up)
#define BTN_START_STOP  PD2 // Start/Stop detektor (Krav 9a)
#define BTN_CALIBRATE   PD3 // Kalibrering (Krav 9b)
#define SLEEP_PIN       PD5 // Pin 5 = Sleep mode control

// Buzzer output (PWM via Timer2)
#define BUZZER_PIN      PB3 // Pin 11 = Buzzer (OC2A)

#endif /* CONFIG_H */

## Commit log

2026-01-05 Initial commit: VLF Metal Detector project
    [Metaldetector.kicad_pcb, Metaldetector.kicad_sch]
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2026-01-07 Add power_test directory with power budget test code
    Merged code from Powerbudget branch as a separate directory to allow
    running power consumption tests independently from the main detector code.
    Includes Power Budget Analysis documentation.
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2026-01-07 Update .gitignore and untrack generated files
    Remove workspace.json, nested .vscode folders, .claude settings, and
    build artifacts from tracking to prevent merge conflicts when switching
    branches. These files are machine/user-specific and shouldn't be shared.
2026-01-07 Add debug system and complete firmware implementation
    Debug System:
    - debug.h/debug.c: 4-screen diagnostic system (ADC, DFT Accum, DFT Result, Timing)
    - Integer math: isqrt(), fast_atan2_deg() for embedded constraints
    - Pin 13 toggle for oscilloscope timing verification
    - Activate by holding both buttons in IDLE state
    Firmware:
    - Complete main.c state machine (STARTUP, IDLE, RUNNING, CALIBRATING, DEBUG)
    - rx.c: ADC sampling at 8kHz with Timer1 Compare Match B trigger
    - dsp.c: 64-sample DFT with 4x oversampling optimization
    - detector.c: Phase-based metal classification (65° threshold)
    - display.c: OLED screen implementations
    - ui.c: Button polling with debounce, buzzer PWM control
    Documen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
    [main.c]
2026-01-08 Add Arduino Nano (ATmega328P) support
    Implement portable firmware supporting both Arduino Mega 2560 and Nano:
    - config.h: Board detection with conditional pin/timer definitions
    - tx.c: Use config macros for TX PWM pin (PB5 on Mega, PB1 on Nano)
    - ui.c: Timer4 (Mega) / Timer2 (Nano) buzzer, portable button handling
    - main.c: Use BTN_PIN macros for button reading
    - debug.h/c: Include config.h for debug pin (PB7 on Mega, PB0 on Nano)
    - I2C.c: Conditional Port A startup code for Mega only
    - platformio.ini: Add [env:nano] and [env:nano_old] build environments
    Pin mapping for Nano:
    - TX PWM: Pin 9 (PB1/OC1A)
    - Buzzer: Pin 3 (PD3/OC2B)
    - Buttons: Pin 2 (PD2), Pin 4 (PD4)
    - Debug: Pin 8 (PB0)
    [I2C.c, config.h, main.c]
2026-01-08 QSPICE model er oprettet ikke done endu
    [Metaldetector.kicad_sch]
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2026-01-08 converted program to run on nano, fixed code with comments about why its more correct, and added datasheet reference, have not tested on breadboard yet.
    [I2C.c, config.h, main.c]
2026-01-09 Port migration branch logic with bug fixes applied
    - Simplified DSP/TX code using migration branch style
    - Fixed OCR0A: 124 -> 249 for correct 8kHz interrupt rate
    - Fixed types: xn as int16_t for signed DC offset result
    - Replaced floating-point sqrt/atan2 with integer-only versions
    - Using auto-trigger ADC (ADATE) instead of manual triggering
    - Added proper header declarations and function prototypes
    - Removed verbose comments, keeping code cleaner
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2026-01-09 fixede timer0
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2026-01-09 Reorganize documentation: new Docs/ structure, delete outdated files
    - Created Docs/Guides, Docs/Theory, Docs/Meetings, Docs/Templates
    - Moved all documentation to appropriate folders
    - Deleted outdated: Debug_Guide.md, Development Roadmap.md, Search Coil Design.md
    - Renamed Coil_Design_Reconciliation.md to Coil Design.md
    - Updated Home.md with new links and current architecture
2026-01-10 Major documentation overhaul and firmware cleanup
    Project Roadmap & Requirements:
    - Add Project_Roadmap.md with full requirements analysis (16 krav)
    - Map implementation status: ~45% complete (SW 70%, HW 30%)
    - Document outstanding tasks, risks, and test checklist
    Firmware (main.c):
    - Restructure with clear section headers and organization
    - Add TODO markers with requirement numbers (Krav 2, 9a, 9b, 8c)
    - Add commented code templates for future implementation
    - No functional changes - preparation for team implementation
    README Updates:
    - Main README.md: Correct to Arduino Nano, internal ADC, H-bridge design
    - Code/README.md: Reflect actual single-file structure, add status table
    - KiCad/RE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
    [main.c]
2026-01-10 Add push-pull driver design and efficiency analysis to TX Driver docs
    - Add new push-pull (totem-pole) driver circuit with 5 BJTs
    - Add ASCII schematics and component list for push-pull design
    - Add H-bridge vs push-pull comparison table
    - Add efficiency and battery consumption analysis section
    - Add detailed battery life calculations (174 min vs 271 min)
    - Add build instructions, wiring guide, and test procedures
    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
2026-01-10 Add report export system for Overleaf integration
    - Report_Export/ folder for staging assets (figures, schematics, code, data)
    - export_to_report.sh script to sync assets to report repository
    - README with workflow and naming conventions
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2026-01-12 Add MATLAB DFT verification system with DSP course convention
    - Refactor main.c with cleaner structure and simplified comments
    - Add CAPTURE_SAMPLES mode for MATLAB verification
    - Extract capture functionality to separate capture.c/capture.h module
    - UART interface for sending raw ADC samples to MATLAB
    MATLAB Verification (Docs/Matlab/verify_dft.m):
    - Implement DFT verification using DSP course convention (62743)
    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
    [last_capture.csv]
2026-01-12 Add QSPICE simulation documentation
    Document the H-bridge TX driver simulation files:
    - Hbro_sim.qsch: Main H-bridge with IRL530 MOSFETs and LC tank (~98% efficiency)
    - bootstrap.qsch: Bootstrap gate driver for high-side N-channel drive
    - dead_time.qsch: RC-based dead-time generator using op-amp comparators
    Includes circuit topology, component specifications, operating principles,
    and simulation commands for parameter sweeps.
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2026-01-12 Rx forstærker udkast
    [rx forstærker.kicad_pcb, rx forstærker.kicad_sch]
2026-01-12 Add coil winder project and documentation
    - Add complete coil winder firmware with Doxygen documentation
    - ATmega328P-based controller for automated coil winding
    - Servo-controlled wire guide with encoder feedback
    - SSD1306 OLED display interface
    - Configurable coil presets for TX/RX coils
    - 3D printable mechanical parts (OpenSCAD)
    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
    [assembly.scad, base_plate.scad, bearing_mount.scad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]
2026-01-13 Replace ITR8307 reflective sensor with break-beam optical sensor
    - New sensor design using SFH4546 IR emitter + BP104 photodiode + LM311 comparator
    - All components available from DTU component shop
    - More reliable detection using slotted encoder disc instead of reflective stripe
    - Updated circuit schematics, component calculations, and wiring diagrams
    - Added DTU component shop inventory CSV for reference
    [dtu_component_shop.csv]
2026-01-13 Rx forstærker uden kond
    [rx forstærker.kicad_sch]
2026-01-13 Fix Wheeler inductance formula and update coil design documentation
    - Fix Wheeler formula coefficient: 0.8 (inches) -> 0.315 (cm)
    - Add single-layer Wheeler formula for bucking coil
    - Add geometry warning for flat TX coil
    - Update MATLAB script with verified formulas
    - Update coil specifications based on corrected calculations
    - Update power budget for 360mA TX current
    - Add Doxygen-generated HTML documentation
    - Update graph to show TX current vs resistance at resonance
    [main.c]
2026-01-15 Enkelte QSPICE ændringer plus kicad schematik af Hbro
    [Højre_side.kicad_sch, Metaldetector.kicad_sch, Venstre_side.kicad_sch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]
2026-01-15 ændret kicad opsætning
    [Dead_Time.kicad_pcb, Dead_Time.kicad_sch, Højre.kicad_pcb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]
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2026-01-15 Update Coil Design with measured values
    - TX+Bucking series: 2.03 mH (vs 5.82 mH theoretical)
    - RX inductance: 12.25 mH (0.4% error from theory)
    - Bucking coil optimal: 20 turns (removed 15 from 35)
2026-01-15 Update coil specs with verified measurements from verify_coils.m
    Actual specifications:
    - TX: 70 turns, 2 layers, 200mm, 0.56mm wire → 1.97 mH
    - Bucking: 20 turns, 1 layer, 60mm, 0.56mm wire → 0.038 mH
    - RX: 445 turns, 3 layers, 50mm, 0.15mm wire → 11.1 mH
    Verification results:
    - TX+Bucking: 2.01 mH theoretical vs 2.03 mH measured (-0.9% error)
    - RX: 11.1 mH theoretical vs 12.2 mH measured (-9.0% error)
    All tests PASS within ±10% tolerance.
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2026-01-16 nyste pcb design til AP forstærker
    [Dead_Time.kicad_sch, Højre.kicad_pcb, Højre.kicad_sch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]
2026-01-16 alla pcber er klar til routing
    [Dead_Time.kicad_pcb, Dead_Time.kicad_sch, Højre.kicad_pcb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]
2026-01-16 Tilføj system interconnect dokumentation
    Tilføjer KiCad skematik med overblik over multi-board arkitekturen:
    - Signal flow mellem boards
    - Connector pinout anbefalinger
    - Fil placeringer
    [System_Interconnect.kicad_sch]
2026-01-16 deadtime pcb almost done, missing 1 gnd connection
    [Dead_Time.kicad_pcb, Dead_Time.kicad_sch]
2026-01-16 Venstre og Højre pcb klar til produktion
    [Højre.kicad_pcb, Venstre.kicad_pcb]
2026-01-16 midlertidig backup før branch skift
    [Højre.kicad_pcb, Venstre-B_Cu.dxf, Venstre-Edge_Cuts.dxf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]
2026-01-17 gemme punkt før jeg laver om i deadtime pcb
    [Dead_Time.kicad_pcb, Dead_Time.kicad_sch, Højre.kicad_pcb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]
2026-01-17 pcb layouts done
    [Dead_Time-B_Cu.dxf, Dead_Time.kicad_pcb, Dead_Time.kicad_sch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]
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2026-01-18 RX forstærker + MCU i kicad,mangler footprints2
    [rx forstærker.kicad_sch]
2026-01-18 rxforstærker simplificeret
    [rx forstærker.kicad_sch]
2026-01-18 Modulariser kode og tilføj buzzer feedback
    Opdeler main.c i separate moduler for bedre læsbarhed:
    - config.h: Alle konfigurationskonstanter
    - timer: TX signal generation og sleep mode
    - adc: 8kHz ADC sampling
    - button: Knap håndtering
    - dft: DFT beregning
    - filter: IIR lavpasfilter
    - detection: Kalibrering og metal klassificering
    - display: OLED visning med signal bar og pænere layout
    - buzzer: Audio feedback der øges med signal styrke
    Buzzer bruger Timer2/Pin 11 og bipper hurtigere jo tættere på metal.
    [adc.c, button.c, buzzer.c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]
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2026-01-19 Add graphical HUD display with icons and startup sound
    - Graphical progress bar and large percentage numbers on display
    - Metal type icons (ferro, non-ferro, searching)
    - Splash screen with DTU 34621 branding at startup
    - Startup jingle (rising power-up sound)
    - Simplified buzzer to beeps that increase with signal strength
    - Reduced display flicker by only redrawing changed elements
    - Translated all comments to Danish
    [buzzer.c, main.c]
2026-01-19 lavet pcb design til arduino/Rx forstærker
    [Højre.kicad_pcb, rx forstærker-B_Cu.dxf, rx forstærker.kicad_pcb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]
2026-01-19 Update documentation for modular architecture and remove coil winder
    - Update all docs to reflect 11-module structure with include/ folder
    - Mark implemented features as done (buzzer, jingle, HUD, classification)
    - Update completion percentages (Software 95%, Overall 75%)
    - Replace EEPROM section with Buzzer/Jingle documentation
    - Remove unused coil_winder firmware and related documentation
    [assembly.scad, base_plate.scad, bearing_mount.scad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]
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2026-01-19 Add H-bridge power control to start/stop button
    When detection is stopped, PD5 is held HIGH permanently to disable
    the H-bridge. Timer1 ISR now checks detection_active before toggling
    SLEEP_PIN, preventing override of the stop state.
    [timer.c]
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2026-01-21 Remove MATLAB capture/debug code and reorganize project structure
    - Remove capture.c/capture.h (MATLAB verification interface)
    - Remove debug display mode and D4 button from firmware
    - Update Code_Review.md to reflect changes
    - Move loose files into appropriate folders:
    - Home.md, Test Plans -> Docs/
    - export_to_report.sh -> Scripts/
    - Add battery discharge test scripts and results
    - Add H-bridge gate oscilloscope images
    [battery_discharge_20260121_112726.csv, battery_discharge_20260121_115143.csv]
2026-01-21 Add script to regenerate battery graphs with smoothed voltage curve
    Applies moving average filter to reduce ADC noise in the voltage readings.
    Window size is configurable (default 30 samples).
2026-01-22 Clean up battery test files and add smoothed graph
    Remove old/duplicate graphs and keep only the relevant CSV with the
    new smoothed voltage curve visualization.
    [battery_discharge_20260121_112726.csv]
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
